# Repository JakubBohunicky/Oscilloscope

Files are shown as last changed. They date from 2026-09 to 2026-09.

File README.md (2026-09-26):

# Digital USB Oscilloscope

A simple 2-channel USB oscilloscope built around an **ESP32-S3** and an **AD9288** ADC (100 MSPS per channel). The board samples the signal, sends the data over USB to a PC, and a Windows app draws the waveform.

Made as a high-school SOČ project (2025).

<p align="center">
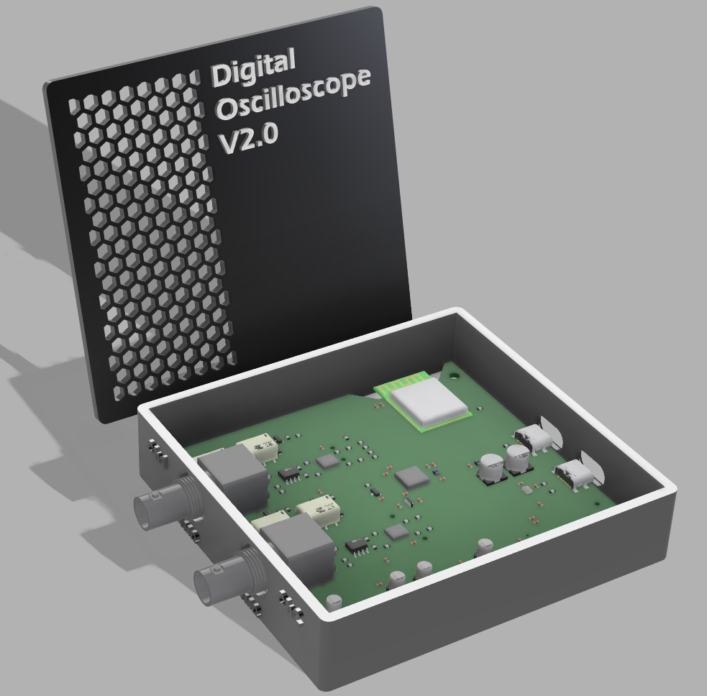
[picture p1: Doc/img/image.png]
3D render of V2.0 in its case
  
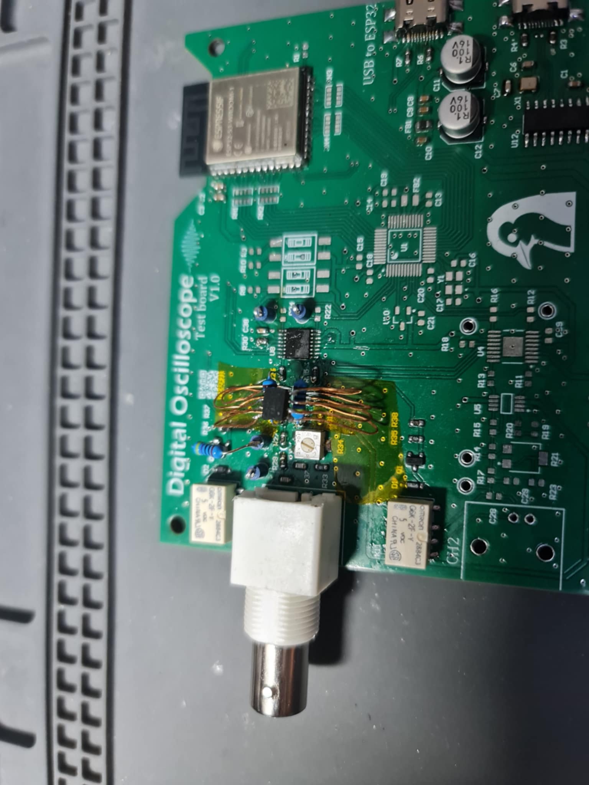
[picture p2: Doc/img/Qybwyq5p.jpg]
Assembled V1.0 test board
  
</p>
<p align="center"><i>Left: V2.0 in its 3D-printed case (render). Right: V1.0 test board.</i></p>

## Features

- 2 channels, BNC inputs
- AD9288 dual 8-bit ADC, up to 100 MSPS per channel
- x1 / x10 input range switched by relays
- Adjustable gain per channel (V/div) and time base (s/div)
- Powered and connected over USB-C
- PC app with live waveform display, min/max readout and optional smoothing

## How it works

```
BNC in → x1/x10 relays → AD8138 (diff. driver) → AD8370 (VGA) → AD9288 ADC → ESP32-S3 → USB-UART (CH340) → PC app
```

1. The input signal goes through a relay-switched attenuator (x1 / x10).
2. The **AD8138** converts it to a differential signal and the **AD8370** variable-gain amplifier scales it so it fits the ADC's 1 Vpp input.
3. The **AD9288** samples both channels; the **ESP32-S3** reads the samples in parallel through its GPIOs.
4. The ESP32 sends the data over UART (460800 baud) through a CH340 USB bridge.
5. The PC app sets the COM port, time base and V/div, and draws the received samples.

Power comes from the USB 5 V. LDOs make 3.3 V for the ESP32 and ADC, and a DC-DC boost to 12 V followed by regulators makes the ±5 V for the ADC driver.

## Schematic

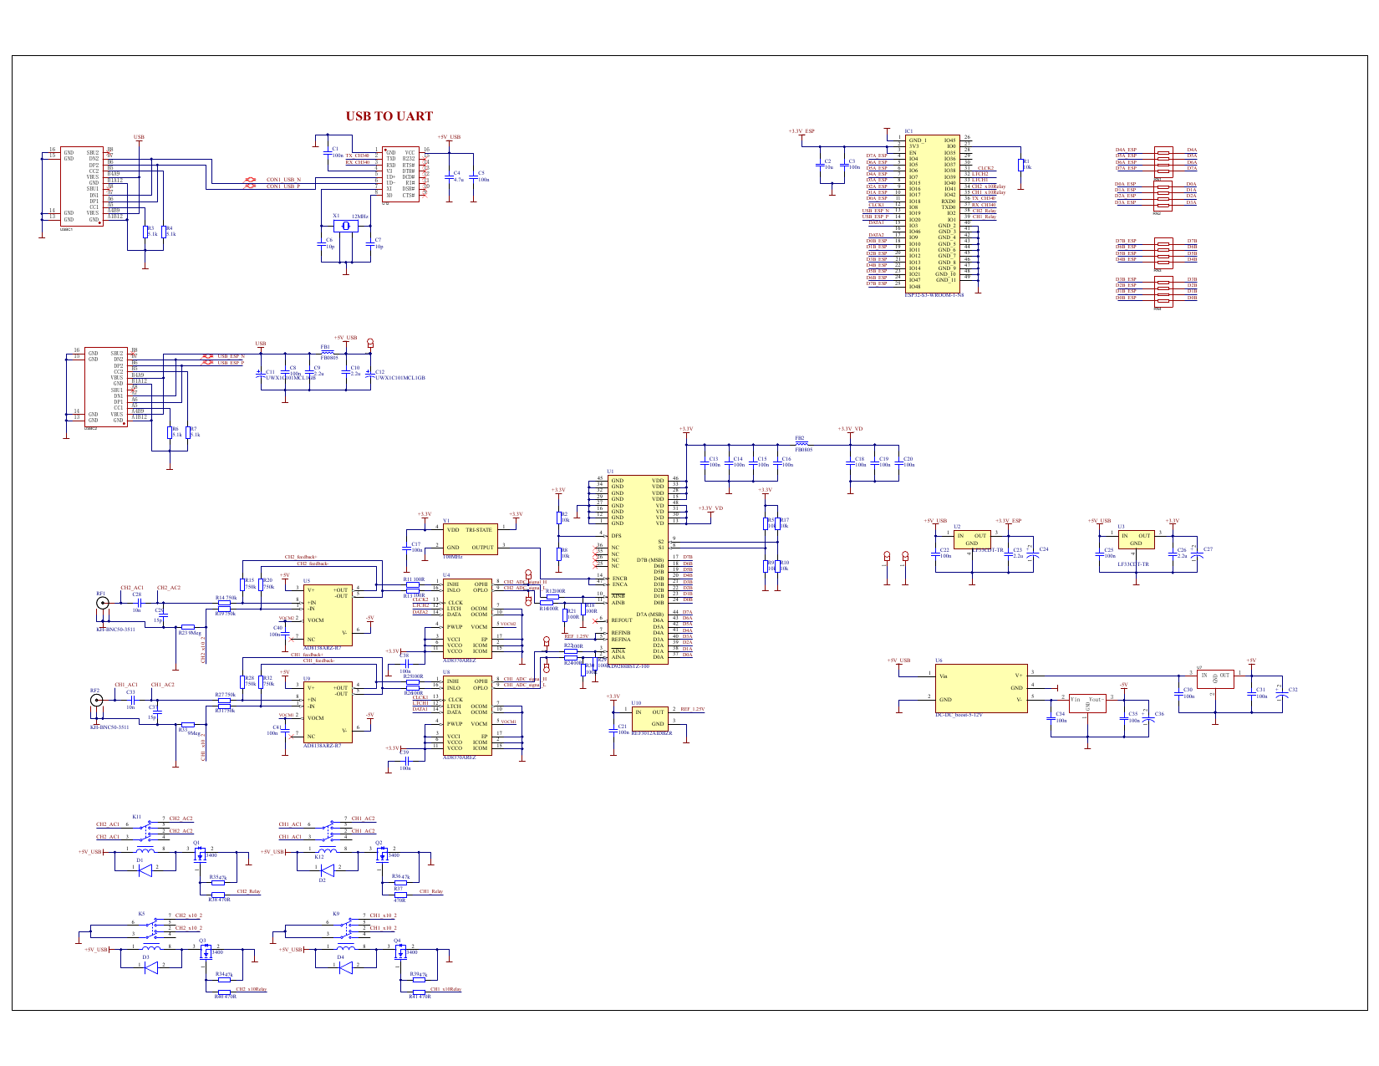
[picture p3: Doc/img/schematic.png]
Schematic


Full Altium projects (schematic, PCB, 3D model, assembly drawings) are in [`PCBs/`](PCBs/).

## Simulation

The input stage was simulated in SPICE before building the board, in both x1 and x10 mode.

| x1 | x10 |
|---|---|
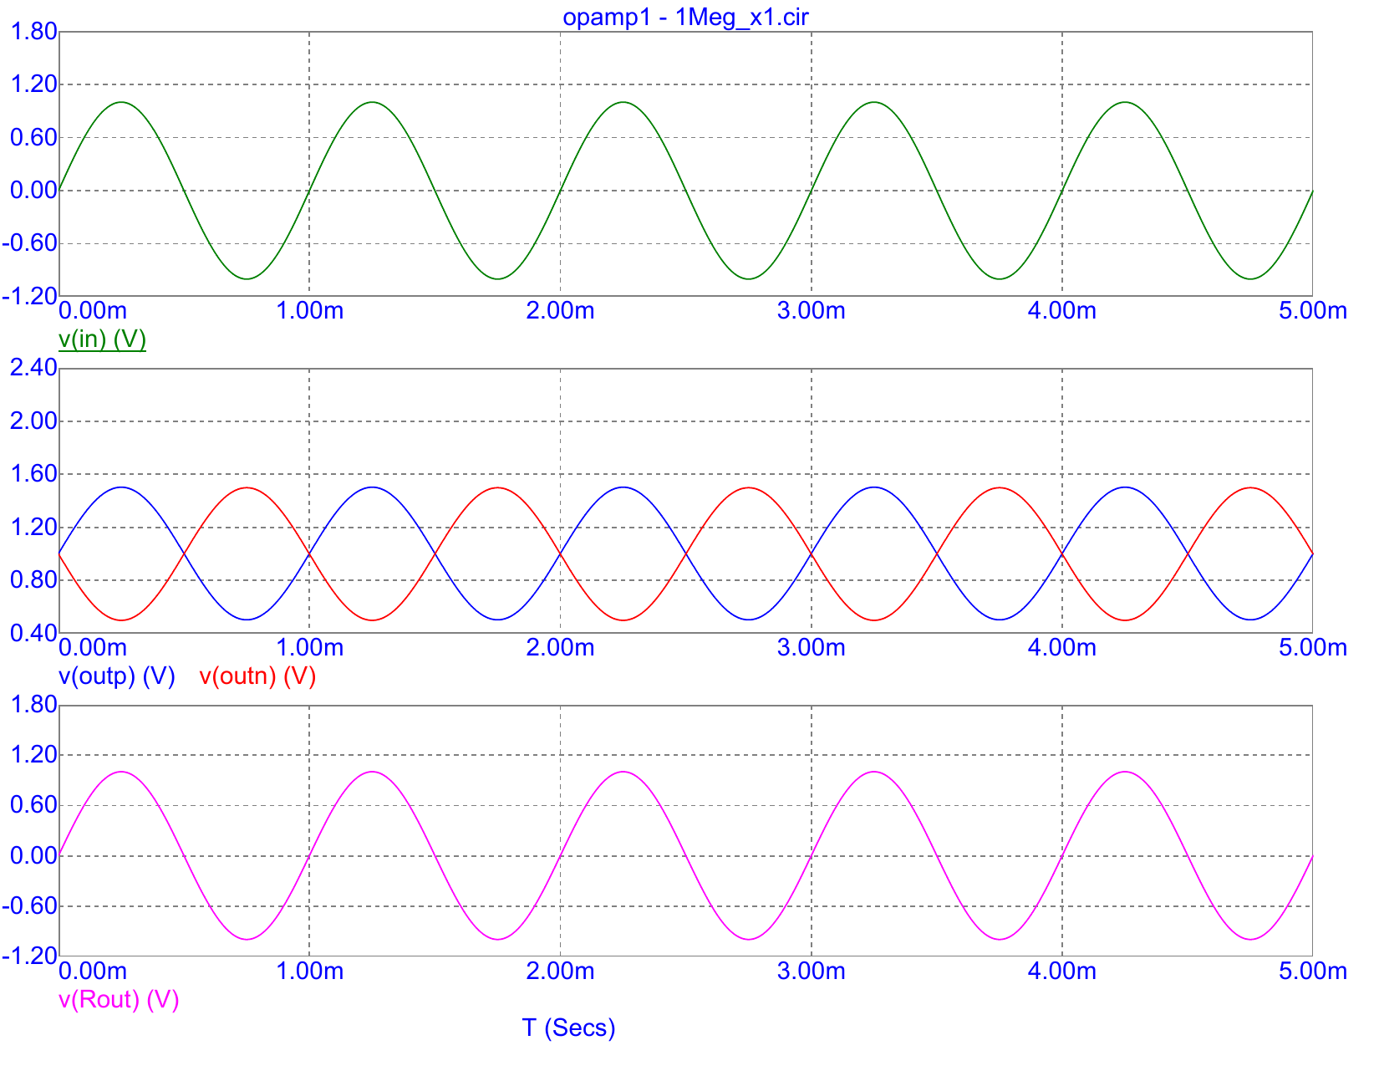
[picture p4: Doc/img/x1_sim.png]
x1 simulation
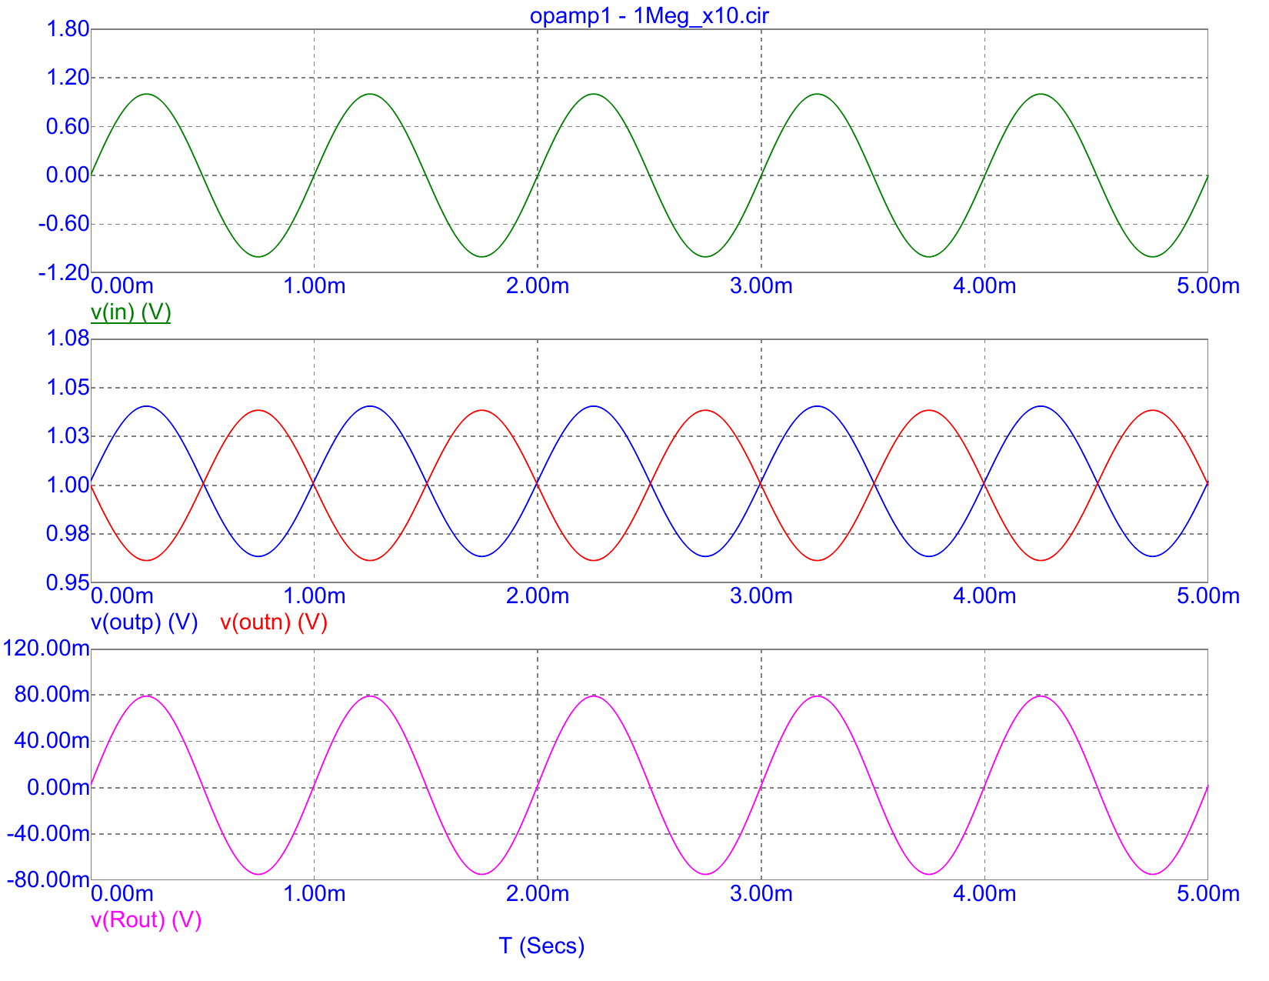
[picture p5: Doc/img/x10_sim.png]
x10 simulation
|  |  |

Circuit files are in [`Sim/`](Sim/).

## PC application

A simple Windows app (C# WinForms, source in [`Firmware/APP/`](Firmware/APP/); open `Osciloskop_software.sln` in Visual Studio) that works like a serial plotter: pick the COM port, press **OPEN**, and set the time base and V/div for each channel.

| Sine (5 ms/div) | Two sines, phase shift (8 µs/div) |
|---|---|
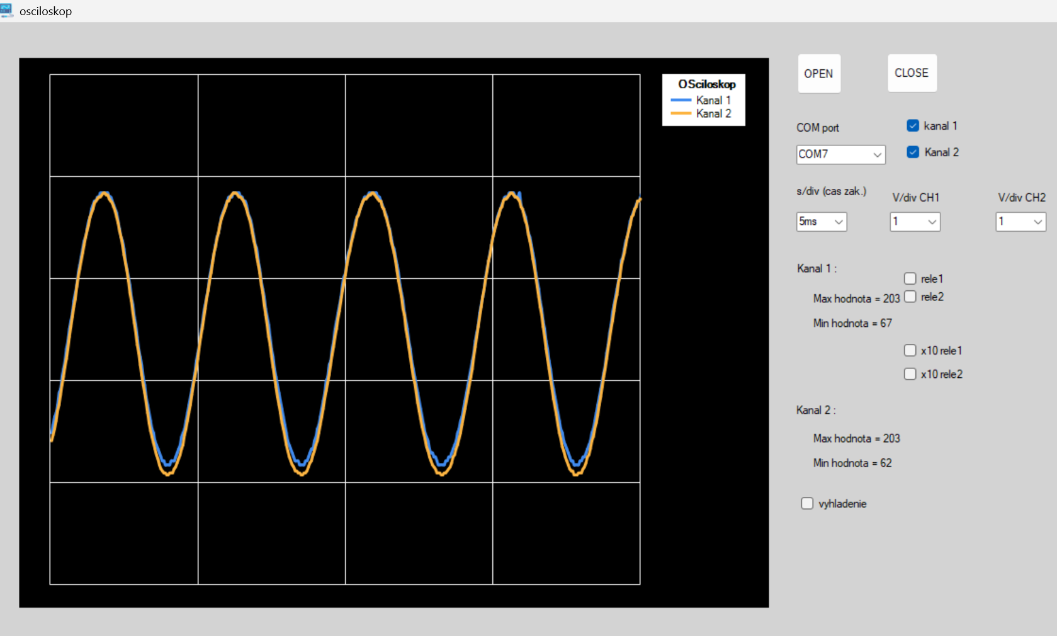
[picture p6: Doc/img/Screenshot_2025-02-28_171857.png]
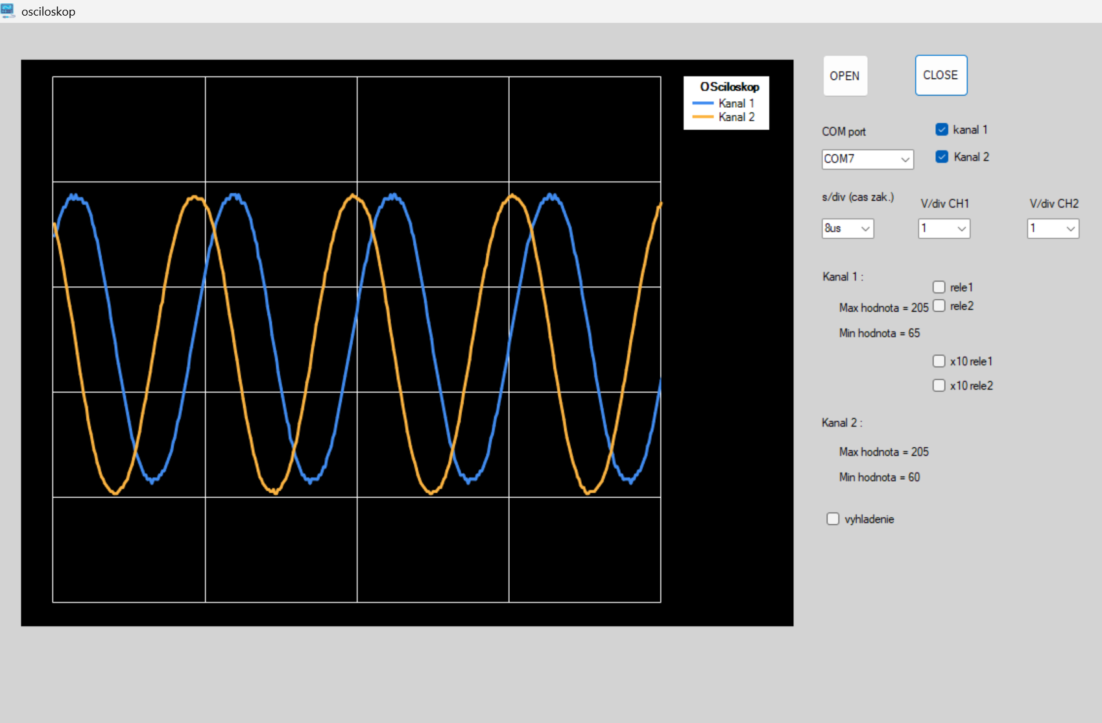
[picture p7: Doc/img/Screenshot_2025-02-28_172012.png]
|  |  |
| **Sine, different V/div** | **Triangle** |
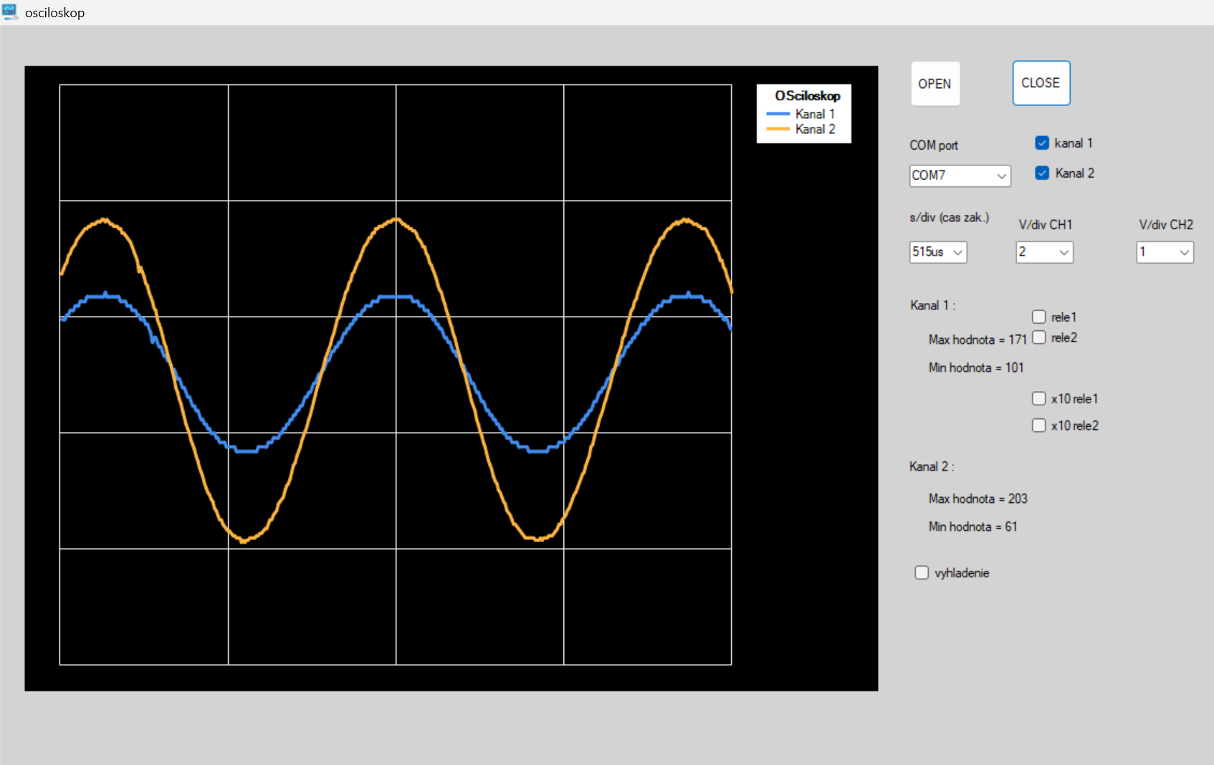
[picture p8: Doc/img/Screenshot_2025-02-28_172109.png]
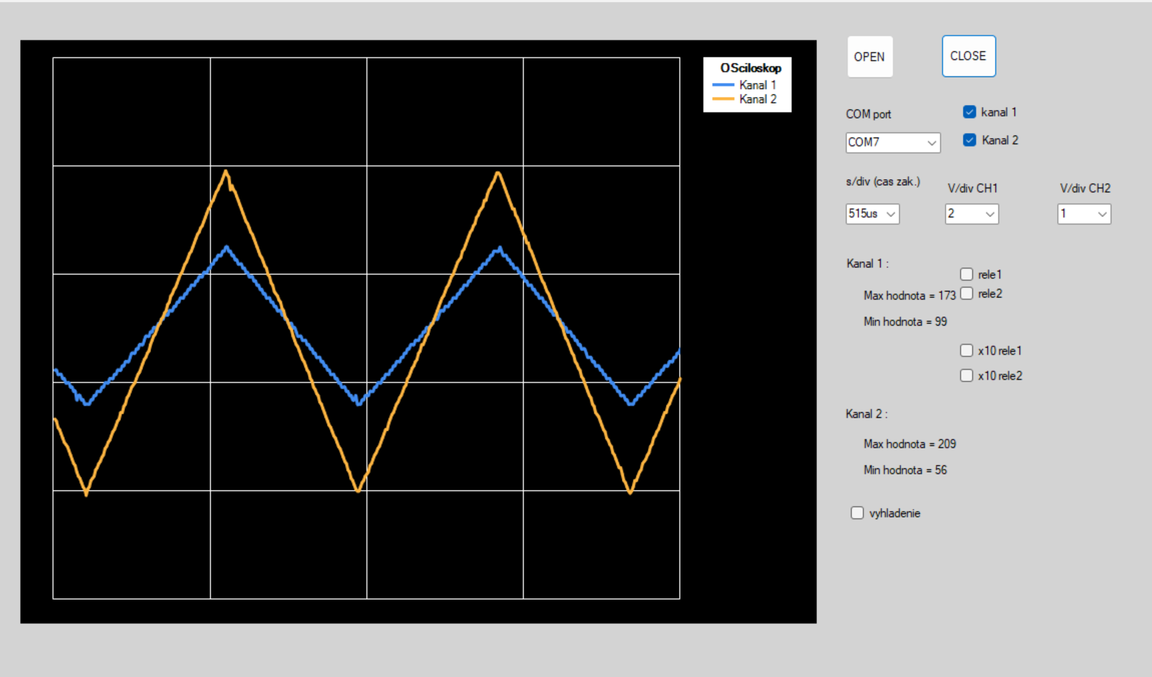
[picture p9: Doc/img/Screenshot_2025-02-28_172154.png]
|  |  |
| **Square wave** | **Linearity test** |
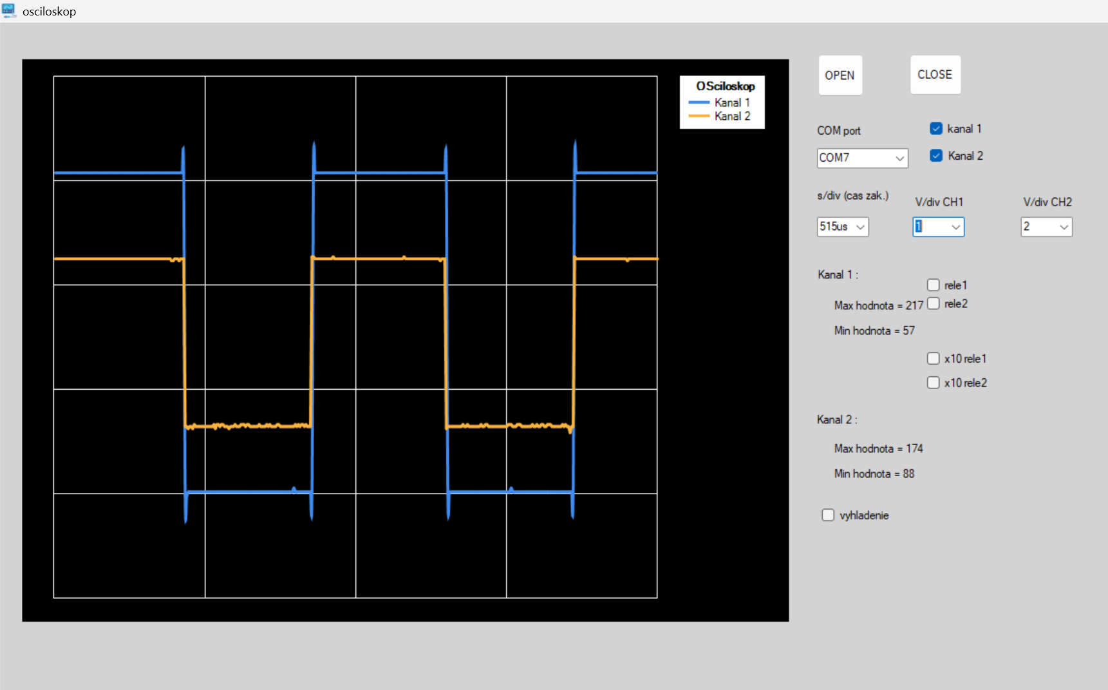
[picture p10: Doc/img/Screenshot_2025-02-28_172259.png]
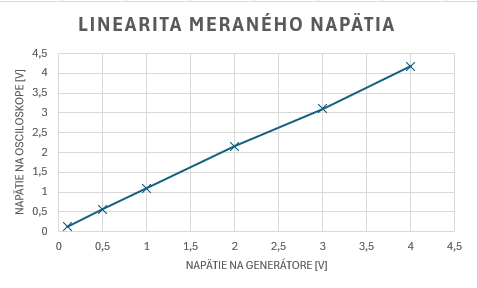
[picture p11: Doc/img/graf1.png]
|  |  |

The linearity test compares the voltage set on a signal generator with the voltage measured by the oscilloscope (0–4 V).

## Repository

| Folder | Contents |
|---|---|
| `PCBs/` | Altium projects, schematics and assembly drawings (V01, V02) |
| `Firmware/EPS32/` | ESP32 firmware (ESP-IDF) |
| `Firmware/APP/` | Windows app for viewing the signal (C#, Visual Studio) |
| `Sim/` | SPICE simulations of the input stage |
| `Doc/` | Full documentation and presentation (in Slovak) |

## Build the firmware

Needs [ESP-IDF](https://docs.espressif.com/projects/esp-idf/en/latest/esp32s3/get-started/).

```bash
cd Firmware/EPS32
idf.py set-target esp32s3
idf.py build flash monitor
```

## Documentation

- [Full documentation (SK)](Doc/SOC_Documentation.pdf)
- [Presentation (SK)](Doc/SOC_Presentation.pdf)

## Authors

Jakub Bohunický, Ondrej Peter, Peter Bódi

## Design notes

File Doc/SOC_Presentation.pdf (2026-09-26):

# Digitálny Osciloskop

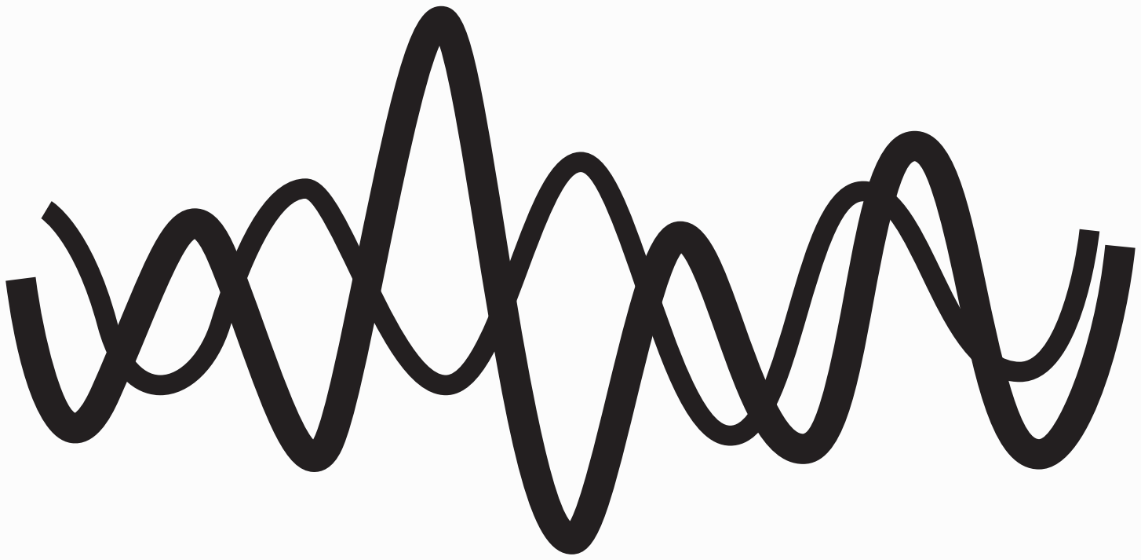
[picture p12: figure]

Jakub Bohunický,
Ondrej Peter, Peter Bódi

SPSŠE Nitra

# Náš cieľ:

Vytvoriť cenovo dostupný osciloskop pre študentov s možnosťou vlastného zostavenia

# Vývoj nášho osciloskopu

### Výber súčiastok

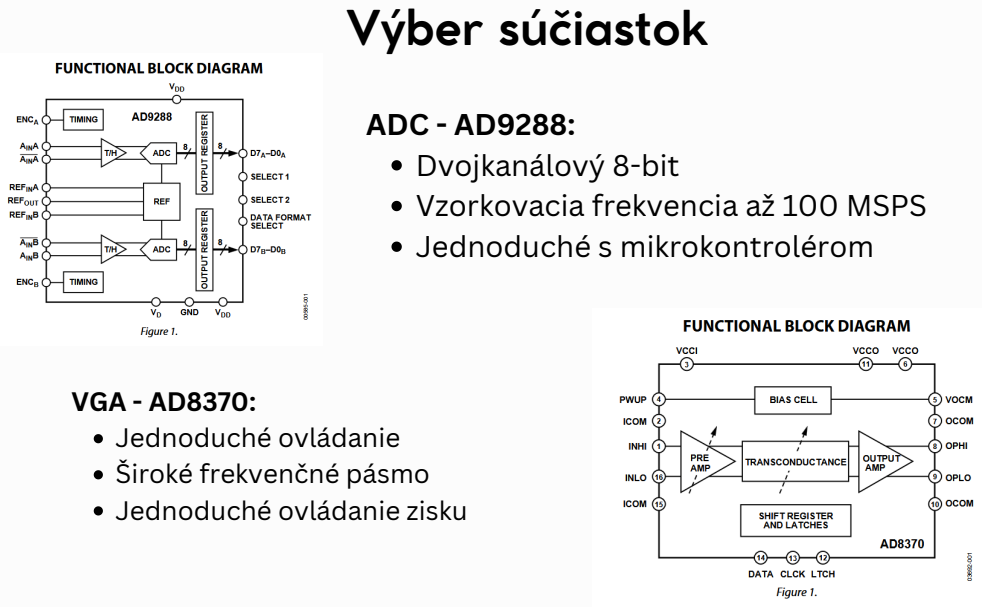
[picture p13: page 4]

ADC - AD9288:
Dvojkanálový 8-bit
Vzorkovacia frekvencia až 100 MSPS
Jednoduché s mikrokontrolérom

VGA - AD8370:
Jednoduché ovládanie
Široké frekvenčné pásmo
Jednoduché ovládanie zisku

### Výber súčiastok

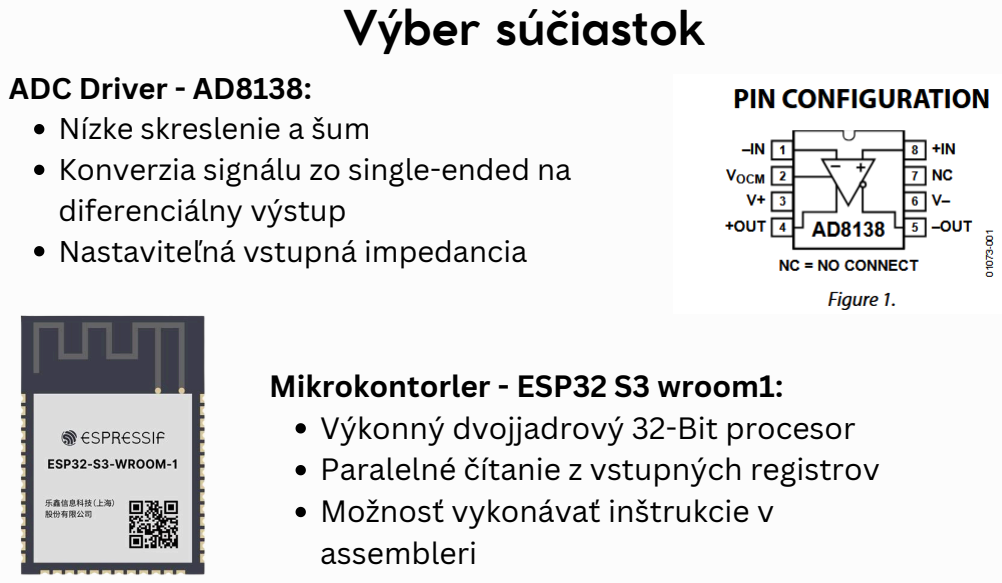
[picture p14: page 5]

ADC Driver - AD8138:
Nízke skreslenie a šum
Konverzia signálu zo single-ended na
diferenciálny výstup
Nastaviteľná vstupná impedancia

Mikrokontorler - ESP32 S3 wroom1:
Výkonný dvojjadrový 32-Bit procesor
Paralelné čítanie z vstupných registrov
Možnosť vykonávať inštrukcie v
assembleri

### Simulácia vstupného obvodu

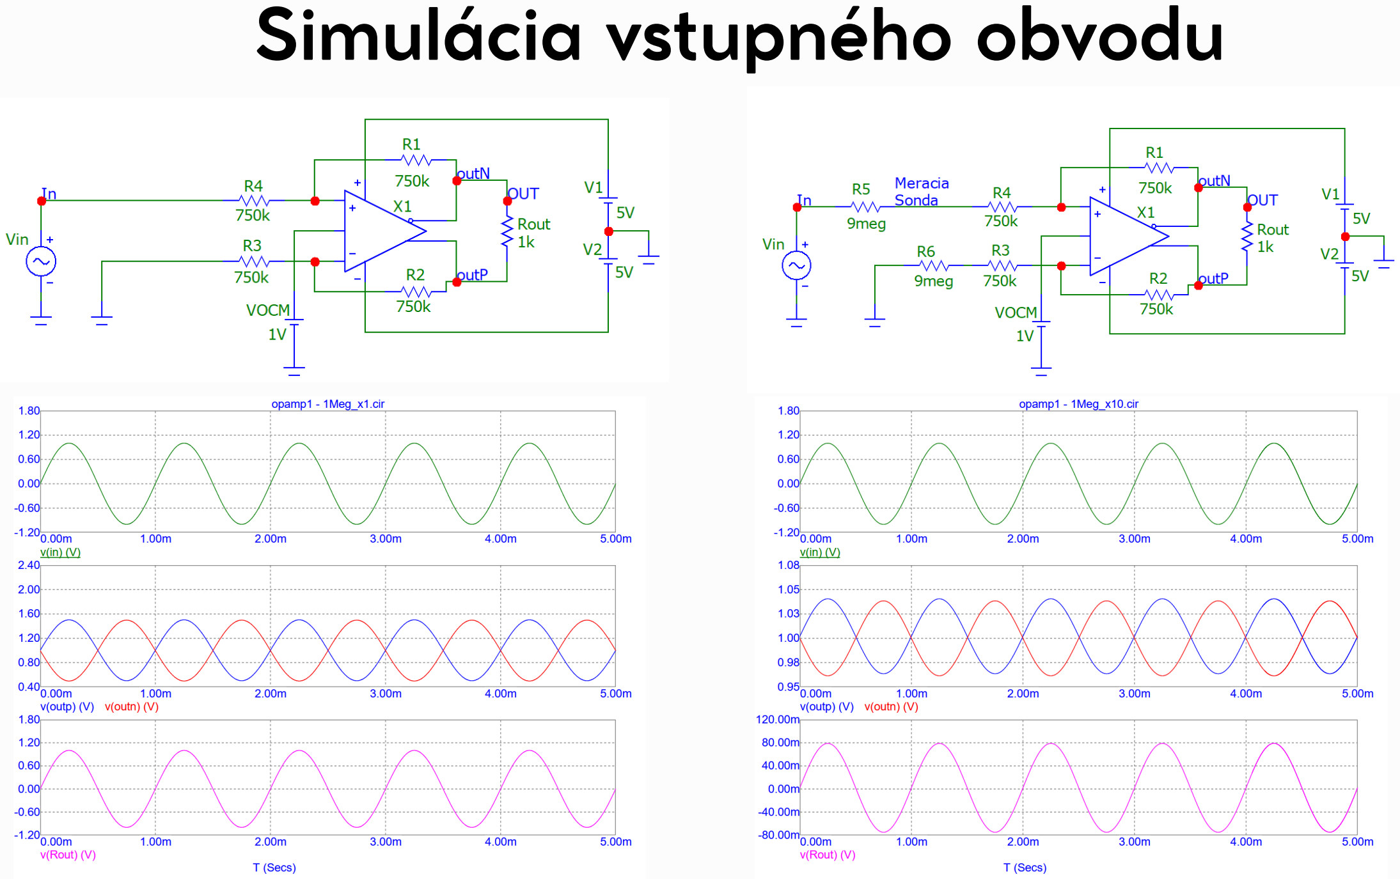
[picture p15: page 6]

### Bloková schéma

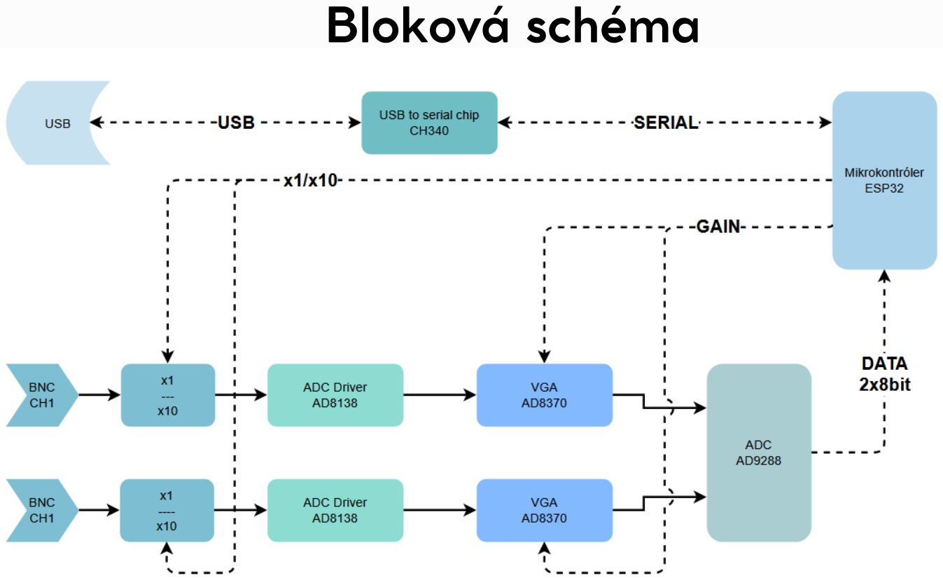
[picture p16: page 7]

### Nastavovalnie zosilnenia

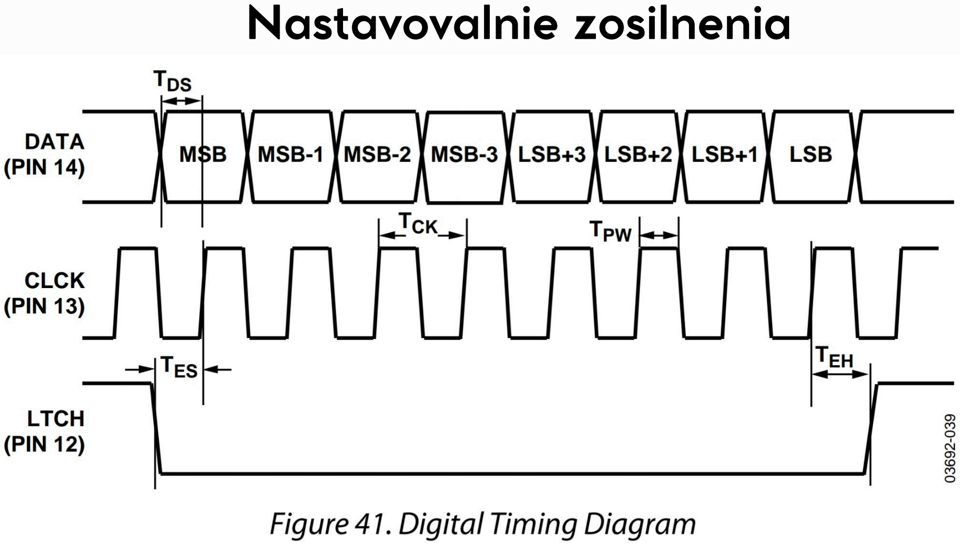
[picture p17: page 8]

### Testovacia doska

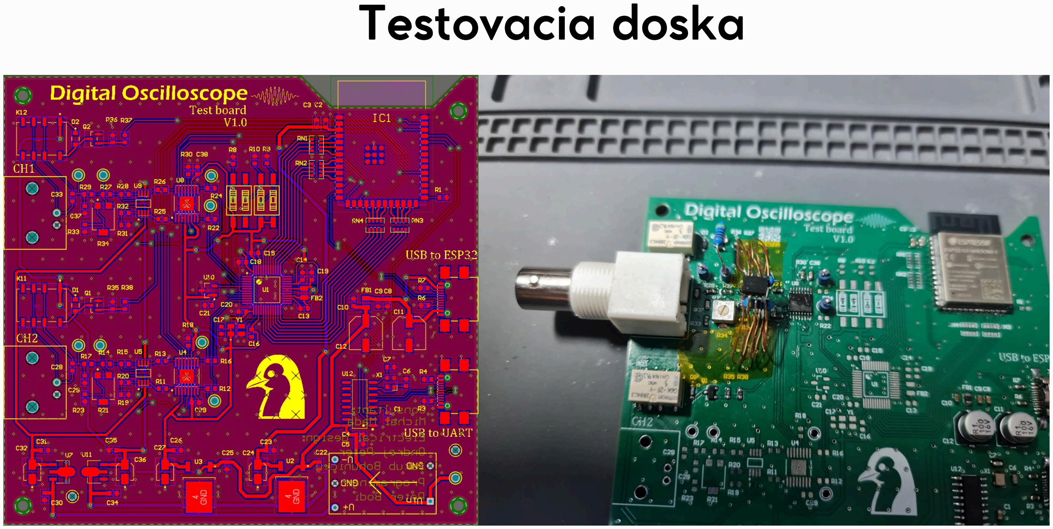
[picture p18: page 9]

### Finálne vyhotovenie

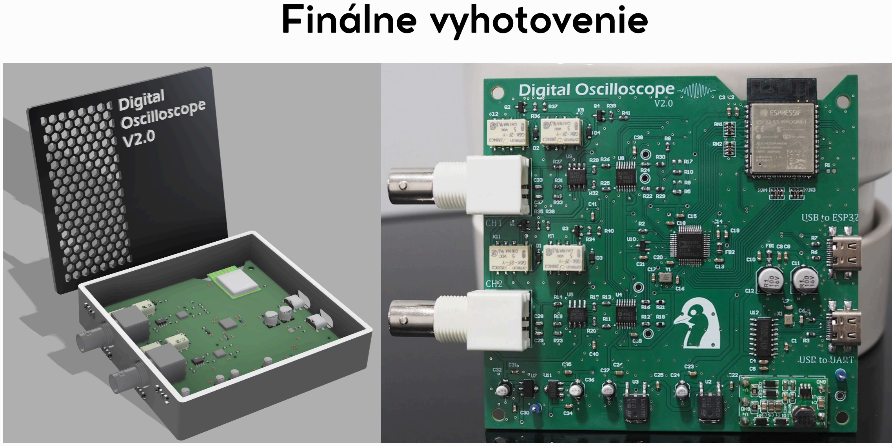
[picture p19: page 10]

### CHARAKTERISTIKY OSCILOSKOPU

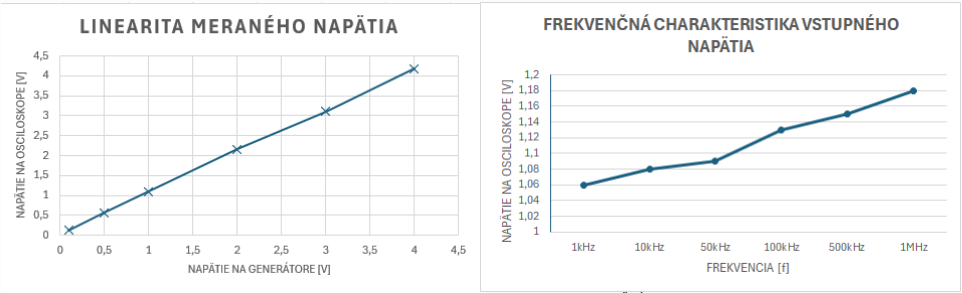
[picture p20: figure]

PRI VSTUPNOM NAPÄTÍ 1V

Dosihnuté parametre:
Maximálne vstupné napätie: 5V/50V
Vzorkovacia frekvencia: 100MSPS/80MSPS Vstupná impedancia: 1MΩ

# Ďakujem za pozornosť

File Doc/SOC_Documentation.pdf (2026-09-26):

STREDNÁ PRIEMYSELNÁ ŠKOLA STROJNÍCKA A ELEKTROTECHNICKÁ

ULICA FRAŇA KRÁĽA 20, 949 01 NITRA

DIGITÁLNY OSCILOSKOP

Stredoškolská odborná činnosť

Číslo odboru: 12

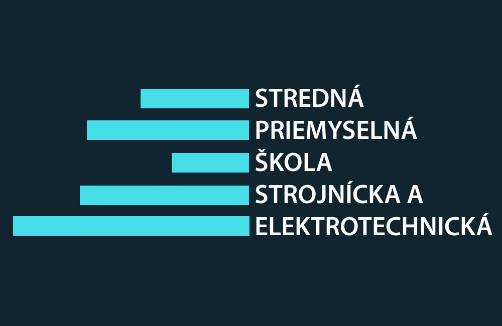
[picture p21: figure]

Riešitelia :Jakub Bohunický, Ondrej Peter, Peter Bódi

Nitra

2025

Ročník štúdia: tretí, štvrtý

STREDNÁ PRIEMYSELNÁ ŠKOLA STROJNÍCKA A ELEKTROTECHNICKÁ

ULICA FRAŇA KRÁĽA 20, 949 01 NITRA

DIGITÁLNY OSCILOSKOP

Stredoškolská odborná činnosť

Číslo odboru: 12

Riešitelia: Jakub Bohunický, Ondrej Peter, Peter Bódi

Nitra

2025

Ročník štúdia: tretí, štvrtý

Školiteľ: Ing. Michal Mada

Čestné vyhlásenie

Vyhlasujem, že prácu stredoškolskej odbornej činnosti na tému Digitálny

osciloskop som vypracoval samostatne, s použitím uvedených literárnych zdrojov. Som

si vedomý zákonných dôsledkov, ak v nej uvedené údaje nie sú pravdivé.

Meno a priezvisko autora

Poďakovanie

Touto cestou by sme sa chceli poďakovať školiteľovi práce, Ing. Michalovi

Madovi za pomoc, odborné vedenie, cenné rady a pripomienky pri vypracovaní našej

práce.

## OBSAH

SPŠSE Nitra | Problematika a prehľad literatúry

ÚVOD

Digitálne USB osciloskopy predstavujú moderné a flexibilné nástroje na meranie

a analýzu elektrických signálov. Pri práci s nimi sa stretávame s rôznymi pojmami, ako

sú vzorkovacia frekvencia, šírka pásma, ktoré môžu byť pre začiatočníkov náročné na

pochopenie. Táto téma nás oslovila natoľko, že sme sa rozhodli vytvoriť si vlastný

osciloskop, aby sme lepšie poukázali na jeho fungovanie a možnosti využitia. Touto

prácou chceme sprístupniť tému digitálnych osciloskopov najmä pre študentov tým, že

poskytneme interaktívne a dostupné možnosti zobrazenia a analýzy signálov. Pomocou

grafického znázornenia a možnosti meniť parametre merania umožníme lepšie

pochopenie fungovaniu elektroniky a jej využitia v praxi. Pochopenie základných

princípov obvodov je kľúčové nielen pri štúdiu, ale aj v praktickej elektronike, keďže

tieto prístroje sú nevyhnutnou súčasťou vývoja a diagnostiky elektronických systémov.

Takéto USB osciloskopy kombinujú kompaktnosť s vysokou presnosťou merania,

vhodnou aj pre náročnejšie projekty. Pre študentov poskytujú dostatočný výkon na

efektívnu prácu a rozvoj v elektrotechnike.

SPŠSE Nitra | Problematika a prehľad literatúry

### 1 PROBLEMATIKA A PREHĽAD LITERATÚRY

### 1.1 OSCILOSKOP

Osciloskop je elektronický merací prístroj na zobrazovanie a analýzu elektrických

signálov v čase. Na jednej osi znázorňuje napätie a na druhej čas, čo umožňuje detailné

skúmanie ich vlastností, ako sú amplitúda, frekvencia či skreslenie. Jeho využitie je

neoddeliteľnou súčasťou práce s elektrickými obvodmi, kde pomáha odhaľovať chyby,

overovať návrhy a optimalizovať systémy. Umožňuje presné doladenie parametrov, čím

zabezpečuje spoľahlivú a efektívnu prevádzku zariadení. Navyše hrá kľúčovú úlohu v

rozvoji nových technológií a inovácií.

Osciloskop umožňuje nielen sledovať, ale aj analyzovať signály, čím prispieva k

presnejšej kontrole a zlepšovaniu výkonu elektronických systémov. Poskytuje tak

neoceniteľný pohľad do správania elektrických signálov, čo uľahčuje diagnostiku a vývoj

nových technológií. (OSCILOSKOP, 2020)

### 1.2 VÝVOJ OSCILOSKOPOV

Vývoj osciloskopov prešiel od analógových zariadení po moderné digitálne

prístroje s pokročilými funkciami. Kým staršie analógové modely využívali katódovú

trubicu (CRT) na zobrazovanie signálov v reálnom čase, ich obmedzené možnosti

ukladania údajov viedli k postupnému nahradeniu digitálnymi osciloskopmi (DSO).

DSO priniesli revolúciu v meracej technike, pretože signály konvertujú do

digitálnej podoby pomocou vzorkovania. Ich hlavnými výhodami sú možnosť ukladania,

podrobnej analýzy, automatických výpočtov a širokej škály pokročilých funkcií. Vďaka

veľkej pamäti umožňujú dlhodobý záznam signálov a ich detailnú analýzu. Dnes sú

štandardom v priemysle, výskume aj vzdelávaní vďaka svojej flexibilite a presnosti.

### 1.3 VÝBER SPRÁVNEHO TYPU OSCILOSKOPU

Pri výbere osciloskopu zohrávajú dôležitú úlohu parametre, ako sú šírka pásma,

vzorkovacia frekvencia, mobilita a cena. Stolné osciloskopy sú určené pre profesionálne

aplikácie, kde je potrebná vysoká presnosť, rýchle vzorkovanie a pokročilé nástroje. Ich

veľké displeje a viackanálové meranie umožňujú detailnú vizualizáciu a diagnostiku

zložitých elektronických systémov. Nevýhodou je ich vyššia cena a nižšia prenosnosť.

SPŠSE Nitra | Problematika a prehľad literatúry

Naopak, USB osciloskopy predstavujú kompaktné a cenovo dostupné riešenie. Sú

vhodné pre študentov, začínajúcich technikov a hobby nadšencov, ktorí potrebujú

základné meranie signálov bez nutnosti investovať do drahých prístrojov. Ich hlavnými

výhodami sú prenosnosť, jednoduché ovládanie a nízka cena. Nevýhodou môže byť

nižšia presnosť a závislosť od výkonu počítača.

Pre špecifické aplikácie existujú aj prenosné osciloskopy, ktoré kombinujú

výhody oboch typov. Poskytujú dostatočnú presnosť, pričom sú navrhnuté na použitie v

teréne, kde je potrebná mobilita a nezávislosť od externého počítača. Ich nevýhodou je

však často vyššia cena v porovnaní s USB modelmi. (TYPY OSCILOSKOPOV, 2025)

### 1.4 ZÁKLADNÉ ČASTI OSCILOSKOPU

Vstupný obvod - osciloskopu slúži na privádzanie a prispôsobenie meraného

signálu pre ďalšie spracovanie. Zabezpečuje správne impedančné prispôsobenie a

ochranu ďalších častí obvodov pred prepätím.

Operačný zosilňovač - Operačný zosilňovač je kľúčový prvok pri úprave

analógového signálu pred jeho spracovaním v analógovo-digitálnom prevodníku (ADC).

Jeho hlavnou úlohou je zosilnenie alebo zoslabnutie signálu, čím optimalizuje využitie

dynamického rozsahu ADC a zabezpečuje presnú digitalizáciu.

Riadenie zisku zosilňovača umožňuje prispôsobiť veľkosť signálu požiadavkám

spracovacieho systému, čím sa predchádza jeho preťaženiu alebo strate jemných detailov.

Dôležitými parametrami operačných zosilňovačov sú šírka pásma, linearita, nízky šum a vstupná impedancia. Široké pásmo zaručuje spoľahlivé spracovanie vysokofrekvenčných

signálov, lineárna odozva minimalizuje skreslenie a nízka úroveň šumu zabezpečuje

presnosť merania aj pri slabých vstupných signáloch. Vysoká vstupná impedancia je

nevyhnutná na to, aby zosilňovač nezaťažoval zdroj signálu a nespôsoboval jeho degradáciu. (OPERAČNÉ ZOSILŇOVAČE, 2015)

SPŠSE Nitra | Problematika a prehľad literatúry

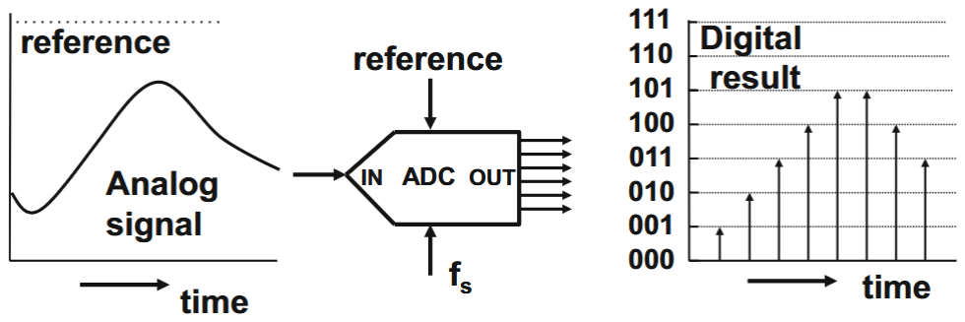
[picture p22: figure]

8

Analógovo-digitálny prevodník (ADC) - slúži na konverziu spojitého

analógového signálu do digitálnej formy, ktorú je možné ďalej spracovávať

mikrokontrolérom alebo iným digitálnym systémom. Tento proces pozostáva z troch

hlavných krokov: vzorkovanie, kvantovanie a kódovanie.

Pri vzorkovaní sa analógový signál meria v pravidelných časových intervaloch,

pričom frekvencia vzorkovania určuje, ako často sa odoberajú vzorky. Kvantovanie

priraďuje každej vzorke najbližšiu možnú diskrétnu hodnotu, čo vedie k vzniku

kvantizačnej chyby. Nakoniec kódovanie prevádza získané hodnoty na digitálny kód

reprezentujúci vstupný signál v číselnej forme.

Presnosť digitalizovaného signálu závisí od rozlíšenia ADC a vzorkovacej

frekvencie – vyššie hodnoty týchto parametrov zabezpečujú vernejšiu reprezentáciu

analógového signálu. Oproti analógovému spracovaniu signálu ponúka digitálne

spracovanie viaceré výhody, ako lepší odstup signálu od šumu, presné uchovávanie

údajov a možnosť vykonávania komplexných výpočtov.

Obrázok 1 ADC, Marcel JM Pelgrom, 2020

SPŠSE Nitra | Problematika a prehľad literatúry

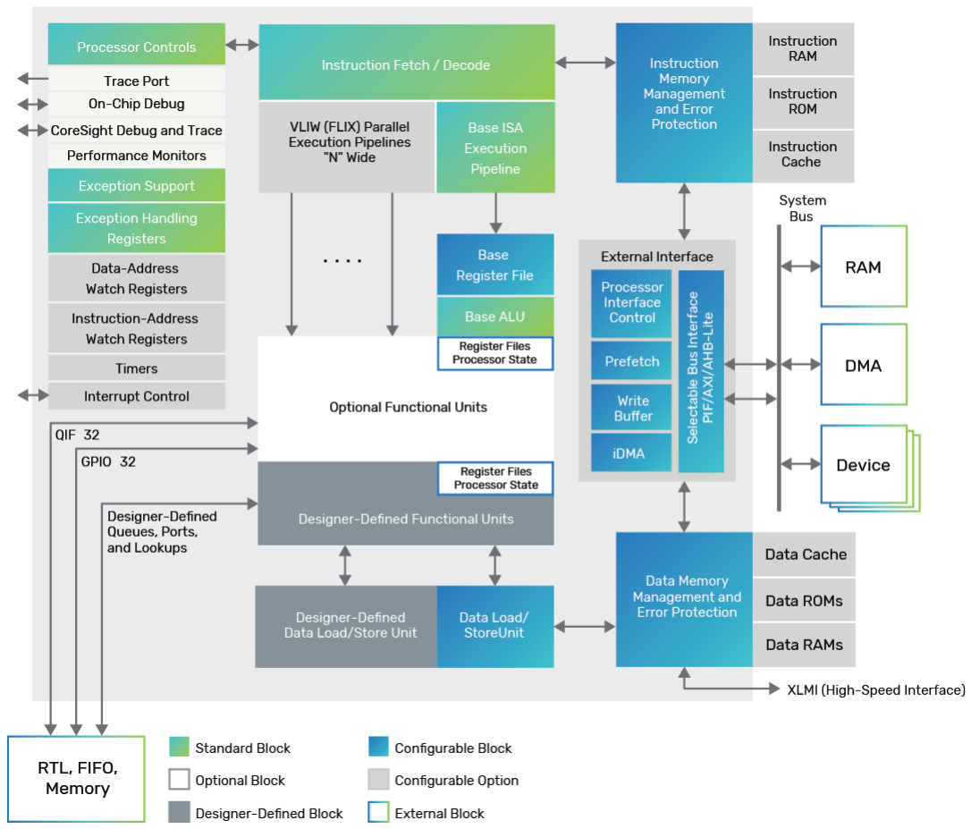
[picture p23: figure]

9

Mikrokontrolér - je vysoko integrované zariadenie, ktoré obsahuje procesor

(CPU), pamäť a periférne obvody na jednom čipe. Jeho úlohou je riadenie a spracovanie

údajov v elektronických systémoch, pričom umožňuje efektívne a automatizované

vykonávanie úloh.

Mikrokontrolér vykonáva program uložený v pamäti ROM alebo Flash, kde sú

uložené inštrukcie pre jeho činnosť. Počas behu programu využíva RAM na dočasné

uloženie údajov a EEPROM na uchovávanie trvalých informácií. Vstavané časovače,

vstupno-výstupné (I/O) porty a komunikačné rozhrania umožňujú interakciu s okolitým

prostredím a inými zariadeniami.

Obrázok 2 Blokový diagram procesora Xtensa LX7 používaný v ESP32, Cadence, 2025

SPŠSE Nitra | Ciele práce SOČ

10

### 2 CIELE PRÁCE SOČ

Cieľom tejto práce je návrh a realizácia digitálneho USB osciloskopu spolu so

softvérom na PC, ktorý umožní presnú analýzu signálov v reálnom čase. Systém bude

využívať vysokorýchlostný AD prevodník na vzorkovanie signálov a komunikovať s

počítačom cez USB rozhranie. Softvér bude slúžiť na vizualizáciu nameraných údajov,

spracovanie signálov a ich analýzu.

Čiastkové ciele:

- Výber vhodných súčiastok pre realizáciu zariadenia
- Návrh schémy a simulácia digitálneho USB osciloskopu
- Návrh a výroba dosky plošných spojov
- Realizácia a následné osadenie DPS
- Osadenie a oživenie elektroniky osciloskopu
- Implementácia firmvéru pre mikrokontrolér zabezpečujúceho

komunikáciu a spracovanie dát

- Vývoj PC softvéru na vizualizáciu a analýzu signálov
- Testovanie a optimalizácia celého systému

SPŠSE Nitra | Výsledky práce

### 3 MATERIÁL A METODIKA

### 3.1 HARDWARE

Na prevod analógových signálov na digitálne hodnoty sme si vybrali dvojkanálový

prevodník AD9288, ktorý poskytuje vzorkovaciu frekvenciu 100 MSPS na každý kanál s

rozlíšením 8 bitov. Tento prevodník sme zvolili kvôli jeho diferenciálnemu vstupu, ktorý

nám umožňuje presnejšie meranie signálu a efektívnejšiu elimináciu rušenia. Vďaka jeho

vysokej rýchlosti snímania dokážeme zachytiť aj veľmi rýchle zmeny v analyzovanom

signáli, čo je pre náš merací systém kľúčové.

Aby sme mohli signál korektne priviesť na ADC, použili sme zosilňovač AD8370

s nastaviteľným ziskom, ktorý nám umožňuje nastaviť úroveň zosilnenia od -11 dB do

+34 dB. Tento zosilňovač sme zvolili na prispôsobenie signálu tak, aby napätie medzi

diferenciálnym vstupmi ADC nepresiahlo 1 Vpp (peak-to-peak). Pre správne impedančné

prispôsobenie vstupu osciloskopu sme si vybrali operačný zosilňovač AD8138ARMZ,

ktorý zabezpečuje vstupnú impedanciu 1 MΩ.

Ako riadiaci mikropočítač sme v tejto práci použili ESP32 vo verzií S3, a to najmä

z dôvodu vysokej rýchlosti procesora (až 240MHz) v porovnaní napríklad s bežnejšie

používaným ale pomalším mikropočítačom ATmega 8 a toho, že procesor ktorý sme sa

rozhodli použiť disponuje dvoma jadrami ktoré dokážu bežať súčasne a nezávisle na

sebe. To z mikropočítača ESP32 robí optimálnu voľbu práve pre aplikáciu ako riadiaci

prvok tohto projektu, keďže každé jadro dokáže nezávisle spracovávať dáta z

prislúchajúceho meracieho kanálu. Toto je nevyhnutné, keďže cieľom tejto práce je

vytvorenie osciloskopu schopného súčasne spracovávať dáta z viacerých meracích

kanálov.

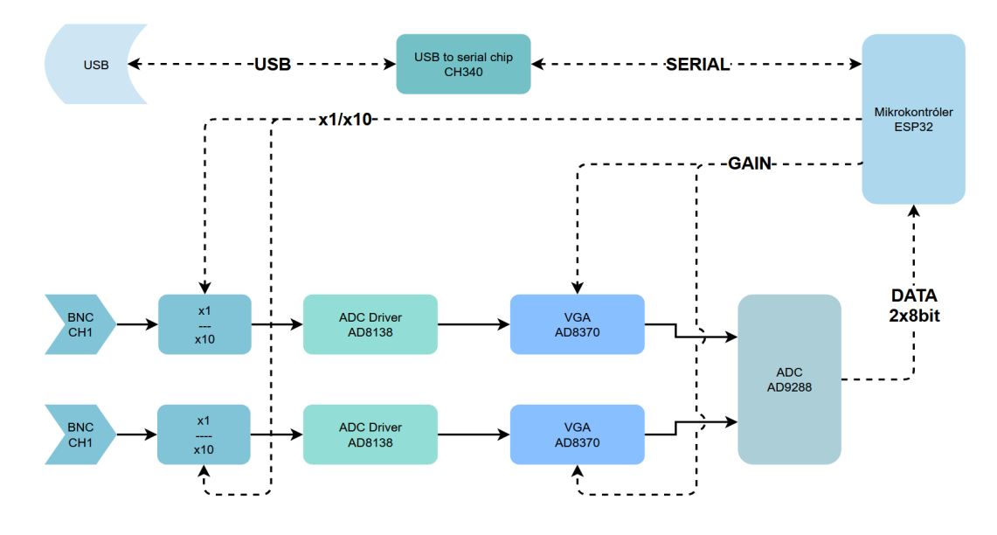
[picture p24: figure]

Obrázok 3 Bloková schéma zapojenia osciloskopu

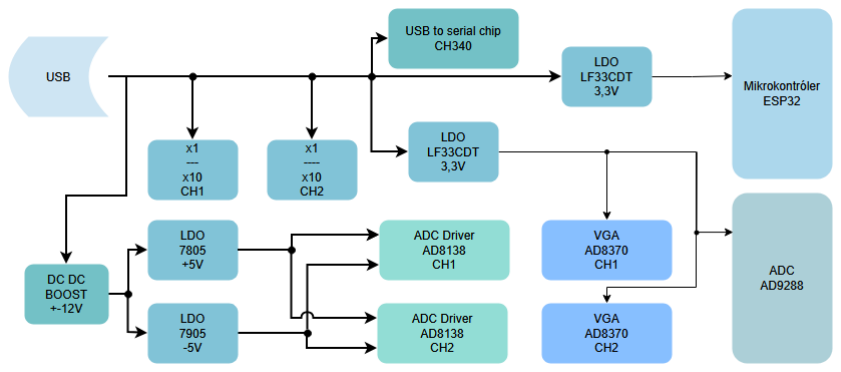
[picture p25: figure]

Na obrázku 4 môžeme vidieť schému napájania rôznych sekcii. Napájanie je

zložené zo štyroch napäťových úrovni. Jedna z najdôležitejších časti nášho osciloskopu

je mikropočítač ESP32, ktorý je napájaný vlastným LDO (low dropout regulator), ktorý

premieňa 5V z USB na 3,3V. Priamo na 5V je napojený iba prevodník z USB na UART a relé na prepínanie deličky. Ďalšie LDO z výstupom 3,3V napája dva operačné

zosilňovače s nastaviteľným ziskom (VGA) a analógovo digitálny prevodník. Ďalší blok

mame DC-DC boost na napätie 12V kvôli zápornej napájacej vetve, ktorú budeme

potrebovať na napájanie ADC driveru. Napätie 12V sme následne prekonvertovali na dve

Obrázok 4 Bloková schéma napájania osciloskopu vetvy +5V a -5V kvôli stabilnej hodnote napájacieho napätia a kvôli zníženiu šumu, ktorý

vzniká pri spínaných meničoch.

### 3.2 SIMULÁCIA A VÝPOČTY

Súčasne s výberom dostupných súčiastok pre náš osciloskop sme vykonali

simuláciu vstupného obvodu, aby sme zabezpečili kompatibilitu medzi jednotlivými

integrovanými obvodmi. Cieľom bolo overiť správnu funkčnosť celého zapojenia ešte

pred objednaním plošných spojov, čím sme minimalizovali nutnosti dodatočných úprav.

Jednou zo základných požiadaviek pri návrhu bolo zabezpečenie vstupnej impedancie na

úrovni 1 MΩ, čo je štandardná hodnota pre osciloskopy. Vstupný zosilňovač, ktorý sme

použili, má v datasheete uvedenú rovnicu na výpočet vstupnej impedancie, podľa ktorej

sme upravili hodnoty rezistorov v obvode spätnej väzby na hodnotu 750kΩ.

Keďže osciloskop sa používa s meracími sondami, ktoré často ponúkajú

prepínateľný deliaci pomer x1 a x10, museli sme tomu prispôsobiť aj náš vstupný obvod.

Pri použití sondy s pomerom x10 sa do cesty signálu zaradí dodatočný odpor 9 MΩ, ktorý

spolu s existujúcou impedanciou vstupu vytvára napäťový delič. Aby sme zachovali

správne fungovanie zosilňovača, bolo potrebné pridať ďalší 9 MΩ odpor na druhý vstup

nášho zosilňovača, keďže pracuje v single-ended zapojení. Tým sme zabezpečili rovnaké

podmienky pre signál a zabránili skresleniu alebo nesprávnemu fungovaniu meraní.

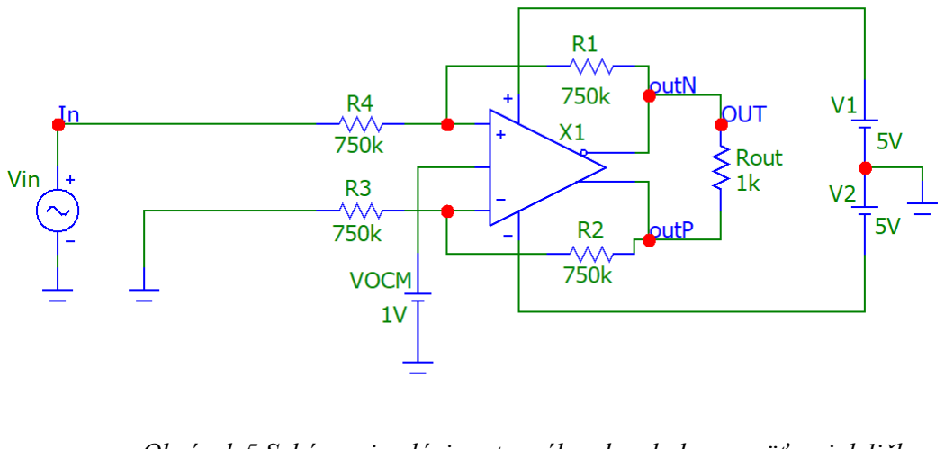
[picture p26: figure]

Obrázok 5 Schéma simulácie vstupného obvodu bez napäťovej deličky

Na simulovanej schéme môžeme vidieť operačný zosilňovač s pinom VOCM,

ktorý slúži na ofset signálu jednosmernou zložkou, pre správne prispôsobenie signálu do

ADC. Tento pin v skutočnom zapojení ovláda operačný zosilňovač s nastaviteľným

ziskom. V simulácii sme použili jednosmerný zdroj, kvôli jednoduchosti simulovaného

zapojenia. Na výstupe operačného zosilňovača máme diferenciálne vedenie, ktoré znižuje

citlivosť na elektromagnetické rušenie, ktoré sa môže indukovať na vodičoch. Keďže

ADC príma rozdiel signálu medzi dvoma diferenciálnymi vodičmi, spoločne rušenie sa

eliminuje, ak je vedenie dobre navrhnuté. Diferenciálny prenos signálu taktiež eliminuje

vplyv kolísania zeme, pretože meria iba spomínaný rozdiel napätia medzi dvoma

vodičmi, ktoré sú pripojené na vstup ADC.

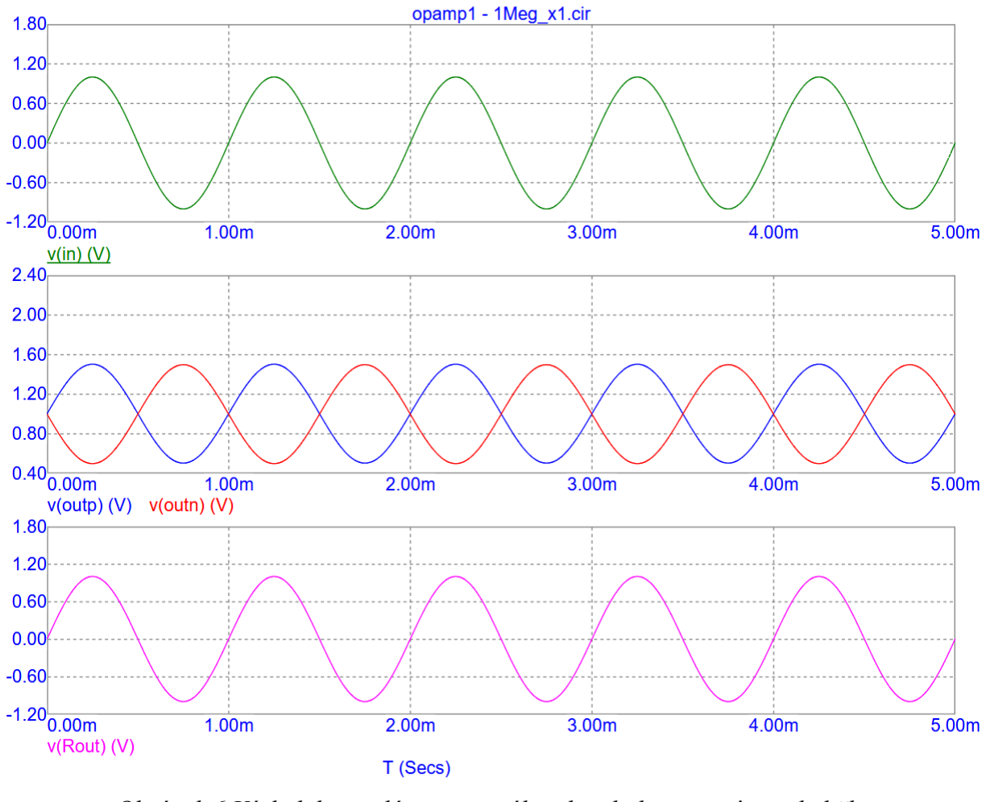
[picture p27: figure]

Obrázok 6 Výsledok simulácie vstupného obvodu bez napäťovej dedičky

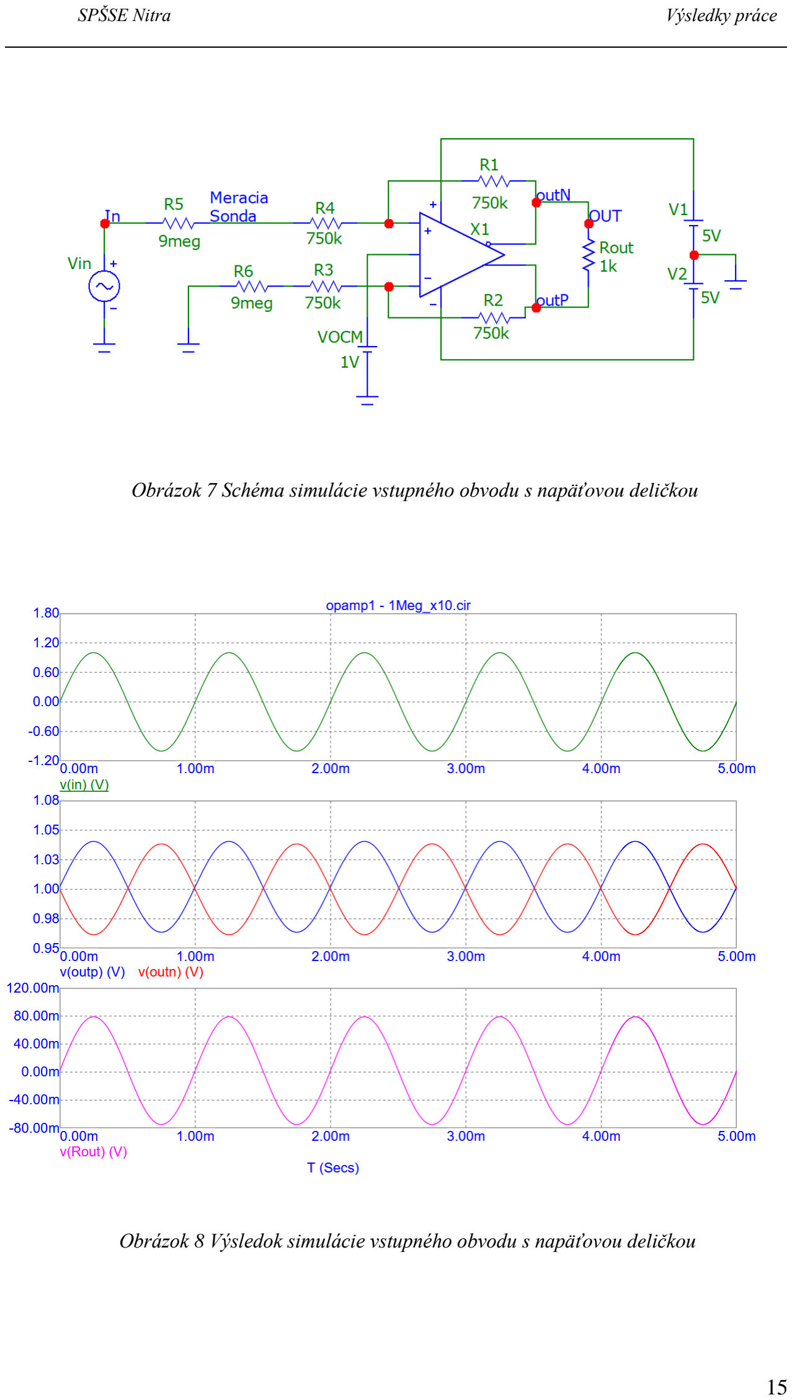
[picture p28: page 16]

Obrázok 7 Schéma simulácie vstupného obvodu s napäťovou deličkou

Obrázok 8 Výsledok simulácie vstupného obvodu s napäťovou deličkou

### 3.3 KOMUNIKÁCIA S AD8370

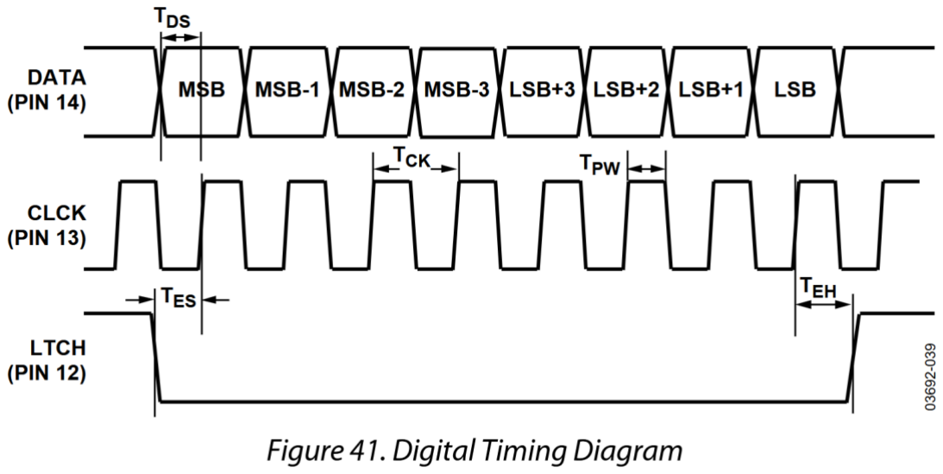
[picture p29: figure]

Obrázok 9 komunikácia na riadenie operačného zosilňovača s riaditeľným ziskom

Komunikáciu medzi VGA a mikrokontrolérom riadime sami, keďže sme museli

implementovať požadovaný riadiaci protokol nášho zosilňovača. VGA začína prijímať

hodnotu zosilnenia signálu zopnutím pinu LTCH na zem. Následne cyklicky zopíname

pin CLOCK, pričom pred každým zopnutím nastavíme hodnotu na pine DATA z výstupu

ESP32, keďže VGA číta hodnoty na nábežnú hranu signálu CLOCK.

Prenášané dáta do VGA tvoria 8-bitovú sériu, na základe ktorej sa nastavuje

hodnota zosilnenia. Prvý bit zo série, známy ako MSB (Most Significant Bit), sa používa

na prepínanie zosilňovača medzi režimami HIGH a LOW gain. Zvyšných 7 bitov slúži

na nastavenie konkrétnej hodnoty zosilnenia pre vybraný režim VGA.

### 3.4 NÁVRH DOSKY

Na návrh dosky plošných spojov sme použili Altium Designer, pretože poskytuje

veľmi dobré prostredie na prácu s komplikovanejšími návrhmi a zároveň obsahuje širokú

škálu knižníc súčiastok, čo výrazne uľahčilo proces návrhu.

Pre tento projekt sme sa rozhodli pre štvorvrstvovú dosku, aby sme

minimalizovali rušenie, keďže ide o merací prístroj, kde je dôležitá presnosť signálov.

Horná a dolná vrstva boli použité na signálové cesty, zatiaľ čo vnútorné vrstvy slúžili ako

polygóny pre GND. Tieto vrstvy boli prepojené prepojkami, čím sme zabezpečili kratšie

prúdové slučky a tým aj nižšie elektromagnetické rušenie.

Okrem toho sme impedančne prispôsobili dosku plošných spojov (PCB) podľa

impedančného profilu výrobcu, pričom sme zohľadnili hrúbku dielektrika, hrúbku medi

a šírku ciest, aby sme zabezpečili správne impedančné parametre a minimalizovali odrazy

signálu. Pri návrhu sme tiež dbali na správne rozloženie komponentov a napájacích trás,

čím sme zabezpečili spoľahlivú funkčnosť návrhu.

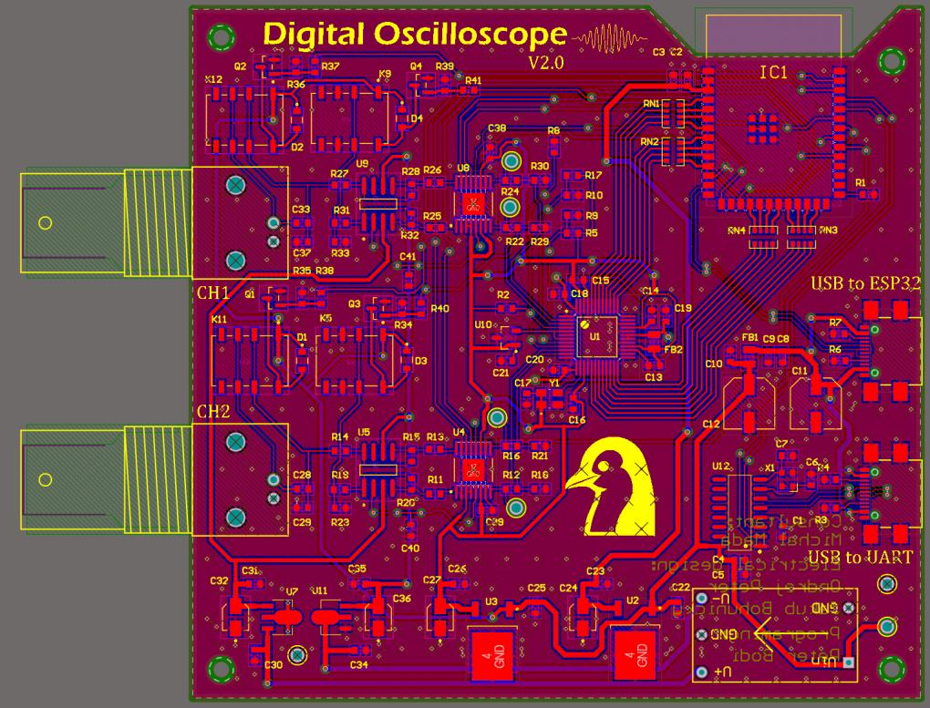
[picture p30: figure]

Obrázok 10 Návrh PCB

### 4 VÝSLEDKY PRÁCE

### 4.1 POPIS VIZUÁLNEJ ČASTI APLIKÁCIE

Aplikácia obsahuje hlavné okno, ktoré je rozdelené na niekoľko logických častí. Tieto

časti slúžia na ovládanie aplikácie, výber nastavení a zobrazovanie grafických

výstupov. Aplikácia je automaticky maximalizovaná hneď pri spustení, aby sa

využila celá plocha obrazovky.

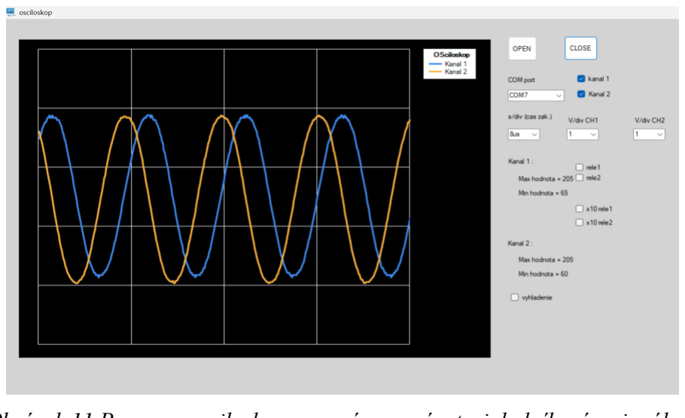
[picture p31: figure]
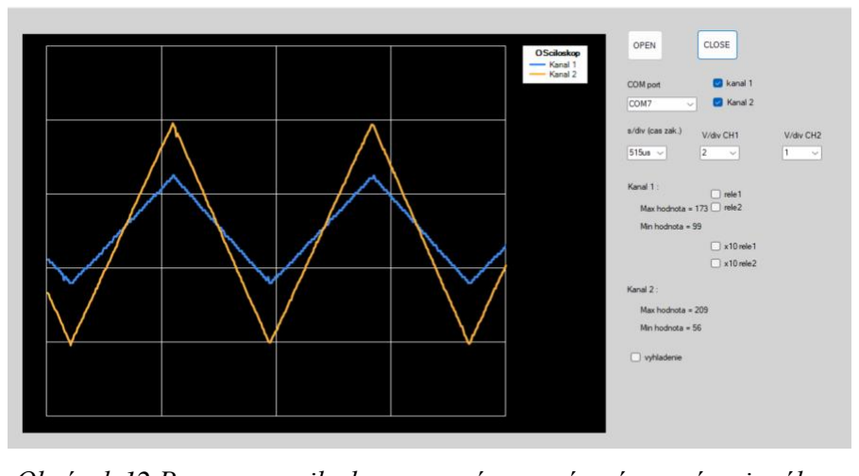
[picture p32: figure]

Obrázok 12 Program osciloskopu so znázorneným sínusovým signálom

Obrázok 11 Program osciloskopu so znázorneným trojuholníkovým signálom

Nastavenie a spustenie komunikácie:

- Nastavenie sériovej komunikácie:
- OPEN – tlačidlo, ktoré otvára sériový port a inicializuje komunikáciu

(realizované pomocou komponentu Button).

- CLOSE – tlačidlo, ktoré zatvára sériový port, avšak iba v prípade ak bol

vopred (realizované pomocou komponentu Button).

- Rozbaľovacie menu na výber COM portu - umožňuje výber portu na

komunikáciu so zariadením (realizované pomocou komponentu

comboBox).

- Menu pre voľbu časovej základne (t/div) - umožňuje výber časovej

základne osciloskopu v závislosti od frekvencie meraného signálu

komunikáciu so zariadením (realizované pomocou komponentu

comboBox).

- Menu pre voľbu napäťového rozsahu (U/div) - umožňuje nastaviť

napäťový rozsah v závislosti od amplitúdy meraného signálu komunikáciu

so zariadením (realizované pomocou komponentu comboBox).

- Tlačidlo SINGE CHANEL – tlačidlo slúžiace na voľbu zobrazenia

oboch meracích kanálov (dual chanel ) alebo iba jedného z nich (single

chanel), ak je tlačidlo aktívne osciloskop funguje ako jednokanálový, v

opačnom prípade zobrazuje súčasne oba meranie kanály (realizované

komponentom checkBox).

Zobrazovanie nameraných hodnôt:

Je realizované pomocou dvoch grafických panely, pričom každý zobrazuje jeden

z kanálov (vytvorené s použitím komponentu chart), na ktorých sú vykreslené dáta v

reálnom čase. Dáta sú zobrazené vo forme časového priebehu pre každý zo kanálov, teda

na osy X sa nachádza priebeh časovej základne osciloskopu a na osy Y sú zobrazované

namerané napäťové úrovne jednotlivých vzoriek. Pred každým nasledujúcim meracím

cyklom sú predchádzajúce vzorky odstránené a nahradené novými.

### 4.2 POPIS FUNGOVANIA APLIKÁCIE

Aplikácia funguje ako jednoduchý sériový plotter (zobrazovač), ktorý prijíma dáta

zo sériového portu (z mikropočítača) a zobrazuje ich v reálnom čase.

1. Inicializácia aplikácie
- Po spustení sa načítajú dostupné COM porty z počítača a pridajú sa do

rozbaľovacieho menu pre výber portu. Používateľ si môže vybrať port, ku

ktorému je pripojený osciloskop.

- Do ďalšieho rozbaľovacieho menu sa načítajú dostupné hodnoty pre časovú

základňu. Podľa tohto nastavenia si užívateľ volí aj vzorkovaciu frekvenciu,

keďže je závislá od nastavenie časovej základne.

- V poslednom rozbaľovacom menu je potrebné nastavenie požadovaného

napäťového rozsahu meraného signálu. V závislosti od tohto nastavenia dôjde k

prislúchajúcej konfigurácii meracích zosilňovačov.

- Sériový port je nakonfigurovaný na rýchlosť 460800 bajtov za sekundu, čo

umožňuje vysokorýchlostný prenos dát.

2. Otvorenie sériového portu
- Po kliknutí na tlačidlo OPEN sa otvorí vybraný sériový port. Program vyšle

inicializačné príkazy pozostávajúce zo zvolených rozsahov pre prvotné nastavenie

osciloskopu.

3. Prijímanie a spracovanie dát
- Program | neustále | kontroluje | prichádzajúce | dáta | pomocou | udalosti

„serialPort_DataReceived“. Dáta sú spracovávané na základe špecifických

podmienok:

- Ak je prijatá hodnota "CH1", program začne zapisovať prijaté dáta do poľa

určeného pre uloženie dát z prvého meracieho kanálu.

- Ak je prijatá hodnota "CH2", znamená to, že nasledujúce dáta budú

prislúchať k druhému kanálu a teda musia byť ukladané do prislúchajúcej

pozície v pamäti.

- Po odoslaní všetkých nameraných dát pre daný cyklus meracia je z

mikropočítača vyslaný príkaz „VYPIS“ čo počítaču signalizuje, že všetky

vzorky boli úspešne prijaté a môže prejsť na ďalší krok, ktorým je

vykreslenie nameraných priebehov pomocou volania metódy „Invoke“.

- Prijaté hodnoty sú rozdelené na vzorky a každá vzorka sa pridáva do

zodpovedajúceho grafu.

4. Zobrazovanie dát
- Metóda „Invoke“ vykresľuje získané dáta na grafy pre kanály 1 a 2 (prípadne len

jeden z nich ak je osciloskop nastavený ako jednokanálový).

- Pre každý kanál sú vykreslené dáta na osobitnom grafe. Používajú sa série bodov,

ktoré sa dynamicky aktualizujú s prichádzajúcimi dátami.

5. Zatvorenie sériového portu
- Tlačidlo CLOSE ukončí komunikáciu so zariadením tým, že zatvorí sériový port.

Tým sa zabráni ďalšiemu prijímaniu dát. Toto tlačidlo slúži teda najmä pre

dočasné zastavenie príjmu ďalších dát a umožnenie analýzy vzoriek už prijatých.

### 4.3 PROGRAMOVÝ CYKLUS

Konfigurácia meracieho zosilňovača – pred každým meracím cyklom je

potrebné nastaviť napäťové zosilnenie meraného signálu pomocou meracieho

zosilňovača. Hodnota zosilnenia je reprezentovaná osem bitovým číslom prislúchajúcim

k napäťovému rozsahu, ktorý si užívateľ zvolil v grafickom rozhraní vytvorenom pre toto

zariadenie. Toto nastavenie meracieho zosilňovača je realizované formou synchrónnej

komunikácie upravenej na parametre vyžadované dokumentáciou použitého zosilňovača.

Na komunikáciu medzi mikropočítačom (ESP32) a meracím zosilňovačom sú použité tri

GPIO piny mikropočítača vopred nakonfigurované na účel tejto komunikácie. Prenos dát

začína prepnutím pinu pripojeného na povoľovací vstup zosilňovača do logickej nuly,

následne sa po jednotlivých bitoch prenesie číslo zodpovedajúce zvolenému rozsahu, čo

je realizované spínaní GPIO pinu pripojeného na dátový vstup zosilňovača, aktuálne

hodnota na tomto pine závisí od vymaskovanej hodnoty čísla reprezentujúceho zvolený

rozsah a rýchlosť toho spínania závisí od rýchlosti hodinového (synchronizačného) cyklu,

ktorý sa vysiela na hodinový (CLK) vstup zosilňovača. Po odoslaní ôsmych bitov reprezentujúcich zvolený rozsah sa povoľovací vstup prepne spať do logickej nuly čo

signalizuje ukončenie komunikácie. Po ukončení komunikácie s meracím zosilňovačom nastane v programe pauza o dĺžke 1µs. Táto pauza slúži na zaistenie toho, že merací

zosilňovač stihol korektne nastaviť požadované zosilnenie. Toto nastavenie je zhodné pre

zosilňovače oboch kanálov.

Odoberanie vzoriek meraného priebehu – Samotné meranie pozostáva z

viacerých častí. Prvou je odoberanie vzoriek meraného signálu v digitálnej forme z

výstupu AD prevodníka, ktorého úlohou je prevádzať analógovú hodnotu napätia

privádzaného na jeho vstup na osem bitové číslo reprezentované logickými hodnotami na

jeho výstupných pinoch. Táto forma výstupu z AD prevodníka umožňuje paralelné čítanie

všetkých bitov súčasne, čo výrazne zvyšuje rýchlosť zápisu do pamäti mikropočítača v

porovnaní so sériovým čítaním jednotlivých bitov. Keďže táto forma výstupu po prvotnej

konfigurácii spojovacích pinov umožňuje priamy zápis priamo do registrov oboch jadier

procesora účastne. Následne sú hodnoty z oboch registrov zapísané do zodpovedajúcich

buniek vnútornej pamäte mikropočítača. Ako najrýchlejšie riešenie pre tento zápis sme

sa rozhodli pre implementáciu rutiny assmbleru, keďže vykonanie tejto inštrukcie trvá

len jeden hodinový cyklus procesora, čo umožňuje dosiahnuť vyššiu vzorkovaciu

frekvenciu v porovnaní s použitím bežných inštrukcii jazyka C v, ktorom sú realizované

ostatné časti programu. Po načítaní vzorky nasleduje oneskorenie, ktoré je realizované

taktiež pomocou ruty assembleru s názvom „nop“, ktorá reprezentuje len prázdnu

inštrukciu pre procesor, ktorá však trvá len jeden takt procesora teda je ňou možné vytvoriť veľmi presné oneskorenia a to už od dĺžky jednotiek nanosekúnd pre meranie

veľmi vysokých frekvencii, až po niekoľko sekundové oneskorenia pre meranie

frekvencii menších ako 1Hz. Po uplynutí oneskorenia dôjde k odobraniu ďalšej vzorky vyššie uvedeným spôsobom. Dĺžka tohto oneskorenia závisí od zvoleného časového

rozsahu, ktorý udáva s akou frekvenciou sa má meraný signál vzorkovať.

Komunikácia s počítačom – Po uložení dát opisujúcich meraný priebeh do

vnútornej pamäti mikropočítača sú následne odosielané cez rozhranie UART (USB) do

pripojeného počítača na následné spracovanie a vykreslenie užívateľovi. Z dôvodu

zvýšenia rýchlosti prenosu sa namerané dáta odosielajú v upravenom formáte, táto úprava

spočíva v odosielaní viacerých vzoriek v jednom prenášanom reťazci v, ktorom sú

jednotlivé hodnoty oddelené vopred definovaným znakom. Toto riešenie sme zvolili aj napriek tomu, že komunikačná rýchlosť (bound rate) by mala postačovať aj na

odosielanie každej hodnoty oddelene, tu však narážame na obmedzenia systému v ktorom

bola vyvinutá aplikácia prijímajúca dáta, ktorá neumožňuje ukladať prijaté dáta pri danej

rýchlosti. Preto je potrebné viacero vzoriek vkladať do jedného prenosového reťazca

ktorý je po prijatí v PC korektne uložený a dekódovaný. Po odoslaní všetkých vzoriek sa

mikropočítač vráti do stavu čakania na to, kým mu bude z PC vyslaný napäťový a časový

rozsah (ako je bližšie uvedené v časti 2.) a po prijatí týchto rozsahov sa celým merací

cyklus (body 2. až 4.) spustí znovu.

### 4.4 VÝSLEDNE VYHOTOVENIE

Počas vývoja sme narazili na viaceré problémy, pričom jedným z najvýraznejších

bol nesprávny offset na diferenciálnych pároch medzi naším VGA a ADC prevodníkom.

Náš VGA poskytuje na pine VOCM napätie, ktoré sa rovná presne polovici jeho

napájacieho napätia, čo v našom prípade predstavovalo 3.33V / 2 = 1.67V. Toto napätie

následne ovplyvňovalo prvý vstupný operačný zosilňovač, ktorý posunul úroveň signálu

príliš vysoko. Náš ADC však vyžaduje, aby bol offset diferenciálnych párov presne 1V.

Aby sme tento problém odstránili v novej generácii dosiek, implementovali sme

napäťový delič na vstupoch, ktorý prispôsobuje úroveň signálu na požadovanú hodnotu 1V. Ďalším problémom bolo dosiahnutie dostatočne vysokej vzorkovacej frekvencie pri

použití mikrokontroléra ESP32, ktorý beží na frekvencii 240 MHz. Pri bežnom čítaní

údajov z ADC pomocou štandardných knižníc sme dosahovali vzorkovaciu frekvenciu

len približne 60 MHz. Aby sme tento výkon zvýšili, implementovali sme špeciálne

assemblerové inštrukcie, ktoré umožňujú extrémne rýchle načítanie celého registra v

jednom inštrukčnom cykle. Z tohto dôvodu sme prešli na model ESP32-S3, ktorý

podporuje tieto optimalizované príkazy. Táto zmena nám umožnila výrazne zvýšiť vzorkovaciu frekvenciu. Ďalšou optimalizáciou bolo paralelné spracovanie dát pomocou

oboch jadier, ktoré ESP32 ponúka. Vďaka všetkým týmto vylepšeniam sme boli schopní

dosiahnuť maximálnu vzorkovaciu frekvenciu 120 MHz.

Ku doske sme spravili krabičku pomocou 3D modelu PCB z Altium Designera, ktorú

sme vymodelovali vo fusion 360. Následne sme ju vytlačili na 3D tlačiarni.

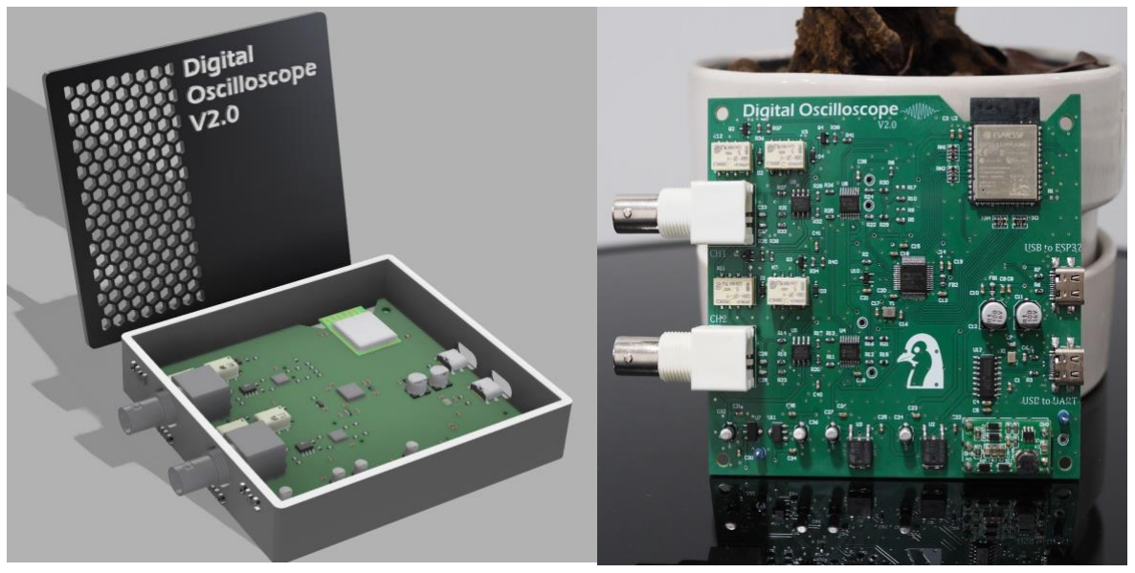
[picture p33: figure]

### 4.5 MERANIE CHARAKTERISTÍK OSCILOSKOPU

Pre overenie správnej funkčnosti a dôveryhodnosti nášho osciloskopu sme sa

rozhodli zmerať jeho vlastnosti. Ako môžeme vidieť, závislosť napätia, ktoré osciloskop

nameria na základe jeho výstupu (obr. č. 15), je lineárna. To znamená, že merania sú

konzistentné a odchýlky minimálne, čo potvrdzuje presnosť zariadenia. Pri frekvenčnej

charakteristike (obr. č. 16) sa priebeh mierne mení so zvyšujúcou sa frekvenciou. Ak sa

však pozrieme na úrovne napätia, zmena medzi minimálnou a maximálnou meracou

frekvenciou bola len 120 mV. Vzhľadom na široké frekvenčné spektrum od 1 kHz až po

1 MHz považujeme tento výsledok za dostatočný a vyhovujúci požiadavkám merania.

Obrázok 13 3D model s krabičkou | Obrázok 14 Vyhotovenie PCB

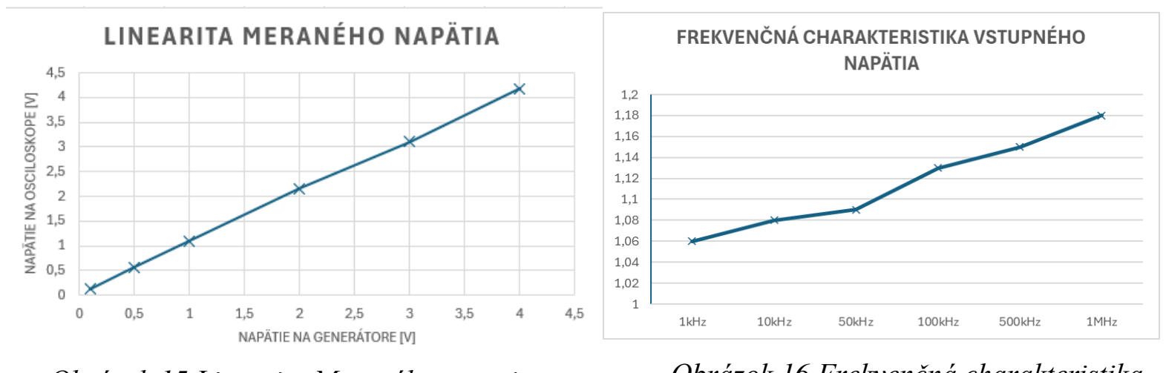
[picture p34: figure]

Obrázok 16 Frekvenčná charakteristika

vstupného napätia pri vstupe 1V

Obrázok 15 Linearita Meraného napätia

SPŠSE Nitra | Diskusia

25

DISKUSIA

Porovnaním nášho digitálneho USB osciloskopu s komerčne dostupnými

riešeniami sme zistili, že napriek nízkym výrobným nákladom približne 30 eur poskytuje

dostatočný výkon pre bežné merania. Zariadenie dosahuje vzorkovaciu frekvenciu

100 MSa/s a ponúka dva kanály, čo ho radí medzi cenovo dostupné, no funkčne adekvátne

riešenia. Tento výsledok je porovnateľný s inými lacnejšími USB osciloskopmi a

potvrdzuje, že aj ekonomicky výhodné zariadenia môžu ponúknuť dostatočne dobré

parametre aj pre náročnejšie aplikácie.

Osciloskop je vybavený vlastnou softvérovou aplikáciou pre počítač, ktorá

umožňuje sledovanie signálových priebehov v reálnom čase a poskytuje základné

analytické funkcie potrebné pre diagnostiku elektronických obvodov. Testovanie

preukázalo stabilnú prevádzku a dostatočnú presnosť, čím sa zariadenie stáva vhodným

pre široké spektrum aplikácií.

SPŠSE Nitra | Závery práce

26

ZÁVERY PRÁCE

V tejto práci sme dosiahli splnenie cieľov stanovených v úvode. Počas realizácie

však nastali určité úpravy, ako napríklad optimalizácia vstupného obvodu pre zlepšenie

presnosti merania a umožnenie pripojenia sondy s deličkou x10.

Účelom tejto práce bolo vytvoriť digitálny osciloskop, ktorý umožní efektívnu

analýzu elektrických signálov a poskytne intuitívne zobrazenie meraných údajov.

Výsledný systém môže byť využitý na vzdelávacie účely, vývoj elektronických obvodov

či diagnostiku rôznych elektrických zariadení.

Jedným z možných vylepšení tejto práce by bolo rozšírenie komunikačných

možností pridaním bezdrôtového prenosu dát cez Wi-Fi alebo Bluetooth, čím by sa

zvýšila mobilita zariadenia a umožnilo by sa jeho ovládanie cez mobilné aplikácie. Ďalšou možnosťou by bola implementácia spektrálnej analýzy pomocou FFT.

Tento produkt sa vyznačuje kompaktným dizajnom a jednoduchým napájaním cez

USB rozhranie, čo umožňuje jeho použitie kdekoľvek s počítačom, pričom náklady na

výrobu sa relatívne nízke.

SPŠSE Nitra | Zhrnutie

27

ZHRNUTIE

Cieľom tejto práce bolo navrhnúť a realizovať digitálny USB osciloskop, ktorý

umožňuje presnú analýzu elektrických signálov v reálnom čase. Dosiahli sme to návrhom

a implementáciou hardvérového zariadenia na báze vysokorýchlostného AD prevodníka,

ktoré zabezpečuje vzorkovanie signálu a jeho následné spracovanie. Meranie prebiehalo

prostredníctvom mikrokontroléra, ktorý riadil komunikáciu medzi osciloskopom a

počítačom cez USB rozhranie. Namerané údaje boli zobrazované v softvéri na PC, ktorý

poskytoval vizualizáciu signálov vo forme časových priebehov. Softvér zároveň

umožňoval analýzu kľúčových parametrov signálu. Vďaka možnosti nastavenia rôznych

vzorkovacích frekvencií a režimov záznamu bolo možné efektívne skúmať správanie

elektrických obvodov v širokom frekvenčnom rozsahu. Systém tak poskytuje komplexný

nástroj na diagnostiku signálov, identifikáciu porúch a analýzu dynamických vlastností

obvodov, pričom jeho flexibilita a použitie softvérových algoritmov umožňujú presné

spracovanie a vizualizáciu meraných dát.

SPŠSE Nitra | Resume

28

RESUME

The aim of this work was to design and implement a digital USB oscilloscope that

enables precise real-time analysis of electrical signals. We achieved this by designing and

implementing a hardware device based on a high-speed ADC, ensuring signal sampling

and subsequent processing. The measurement was carried out using a microcontroller that

managed communication between the oscilloscope and a computer via a USB interface.

The measured data was displayed in PC software, which provided signal visualization in

the form of time waveforms. The software also enabled the analysis of key signal

parameters. Thanks to the ability to set various sampling frequencies and recording

modes, it was possible to effectively study the behavior of electrical circuits across a wide

frequency range. This system thus provides a comprehensive tool for signal diagnostics,

fault identification, and analysis of circuit dynamic properties, while its flexibility and

use of software algorithms allow for precise processing and visualization of measured

data.

SPŠSE Nitra | Zoznam bibliografických odkazov

29

ZOZNAM BIBLIOGRAFICKÝCH ODKAZOV

ADC, Marcel JM Pelgrom [cit.25.2.2025].

Marcel J. M. Pelgrom 2022, Analog-to-Digital Conversion, Helmond, Netherlands

1032 strán, (ISBN 978-3-030-90808-9)

Blokový diagram procesora Xtensa LX7 používaný v ESP32

[cit.25.2.2025]. Dostupné na internete :

<https://www.cadence.com/en_US/home/resources/datasheets/xtensa-lx7-processor-

ds.html>.

OPERAČNÉ ZOSILŇOVAČE [cit.25.2.2025].

Sergio Franco 2015, Design with Operational Amplifiers and Analog Integrated Circuits

San Francisco, USA, 733 strán (ISBN 978-0-07-802816-8)

OSCILOSKOP [cit.25.2.2025].

David Herres 2020, Oscilloscopes: A Manual for Students, Engineers, and Scientists

Clarksville, USA, 276 strán (ISBN 978-3-030-53885-9)

TYPY OSCILOSKOPOV

[cit.25.2.2025]. Dostupné na internete :

<https://www.keysight.com/used/us/en/knowledge/guides/used-oscilloscope-buying-

guide/types-of-oscilloscope>.

ZOZNAM PRÍLOH

Príloha A – Schéma

Príloha B – CD so zdrojovým kódom a vizuálnou časťou aplikácie

## PRÍLOHA A

CELKOVÁ SCHÉMA ZAPOJENIA

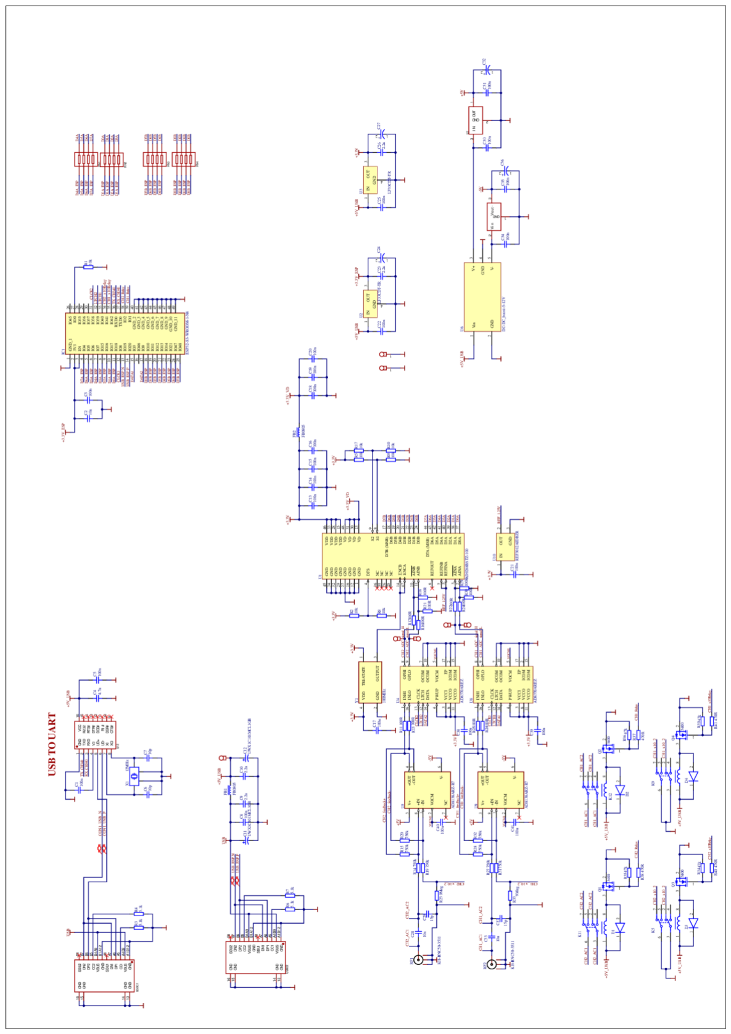
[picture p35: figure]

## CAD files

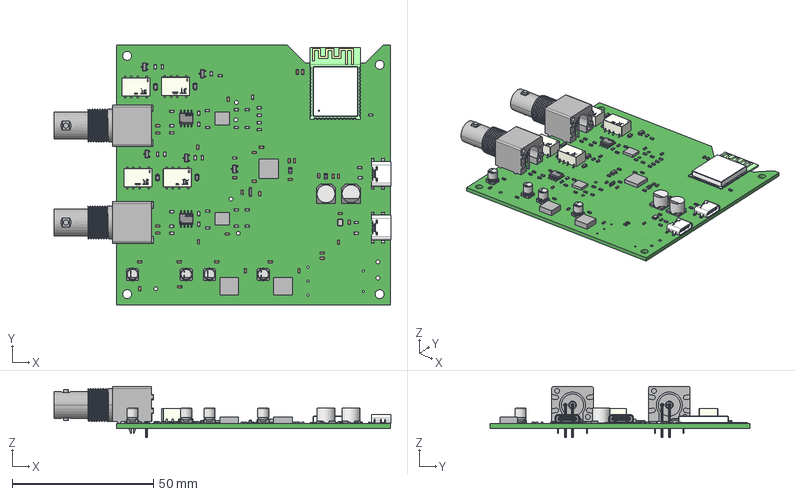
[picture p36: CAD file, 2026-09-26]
PCBs/Oscilloscope_V02/3D model_V02.step
119.5 x 92.1 x 18.2 mm
C0603 x 35
R0603 x 41
pins x 6
logo x 6
73100-0131_RGB8421504 x 2
ON Semi Logo - withoutPN x 4
ON Semi Logo - withoutPN - Copy x 4
TE Connectivity IM43GR 1 x 4
Omron G6K-2F-Y-TR-DC5 2 x 16
Omron G6K-2F-Y-TR-DC5 2_MIR2 x 16
TE Logo x 4
ROHM Logo x 4
Extruded x 5
ECS-250-6-33B2-CTN-TR3
XTAL-2520
USB_C_USB4135-GF-A x 2
BODY_MF03A
LEAD_MF03A x 3
base x 4
cap x 4
lead x 4

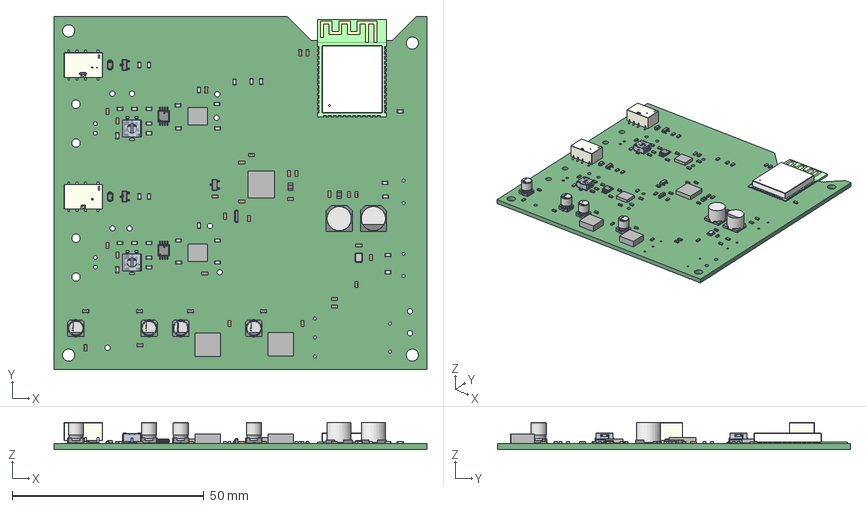
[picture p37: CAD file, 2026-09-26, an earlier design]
PCBs/Oscilloscope_V01/3D model_V01.step
97.2 x 92.1 x 7.14 mm
C0603 x 33
Extruded x 5
ECS-250-6-33B2-CTN-TR3
XTAL-2520
BODY_MF03A
LEAD_MF03A x 3
Leg x 2
Analog Devices Logo x 2
R0603 x 34
3314G1 x 2
ON Semi Logo - withoutPN x 2
ON Semi Logo - withoutPN - Copy x 2
TE Connectivity IM43GR 1 x 2
Omron G6K-2F-Y-TR-DC5 2 x 8
Omron G6K-2F-Y-TR-DC5 2_MIR2 x 8
TE Logo x 2
ROHM Logo x 2
base x 4
cap x 4
pins x 4
logo x 4
lead x 4

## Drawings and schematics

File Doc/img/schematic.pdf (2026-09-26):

# USB TO UART

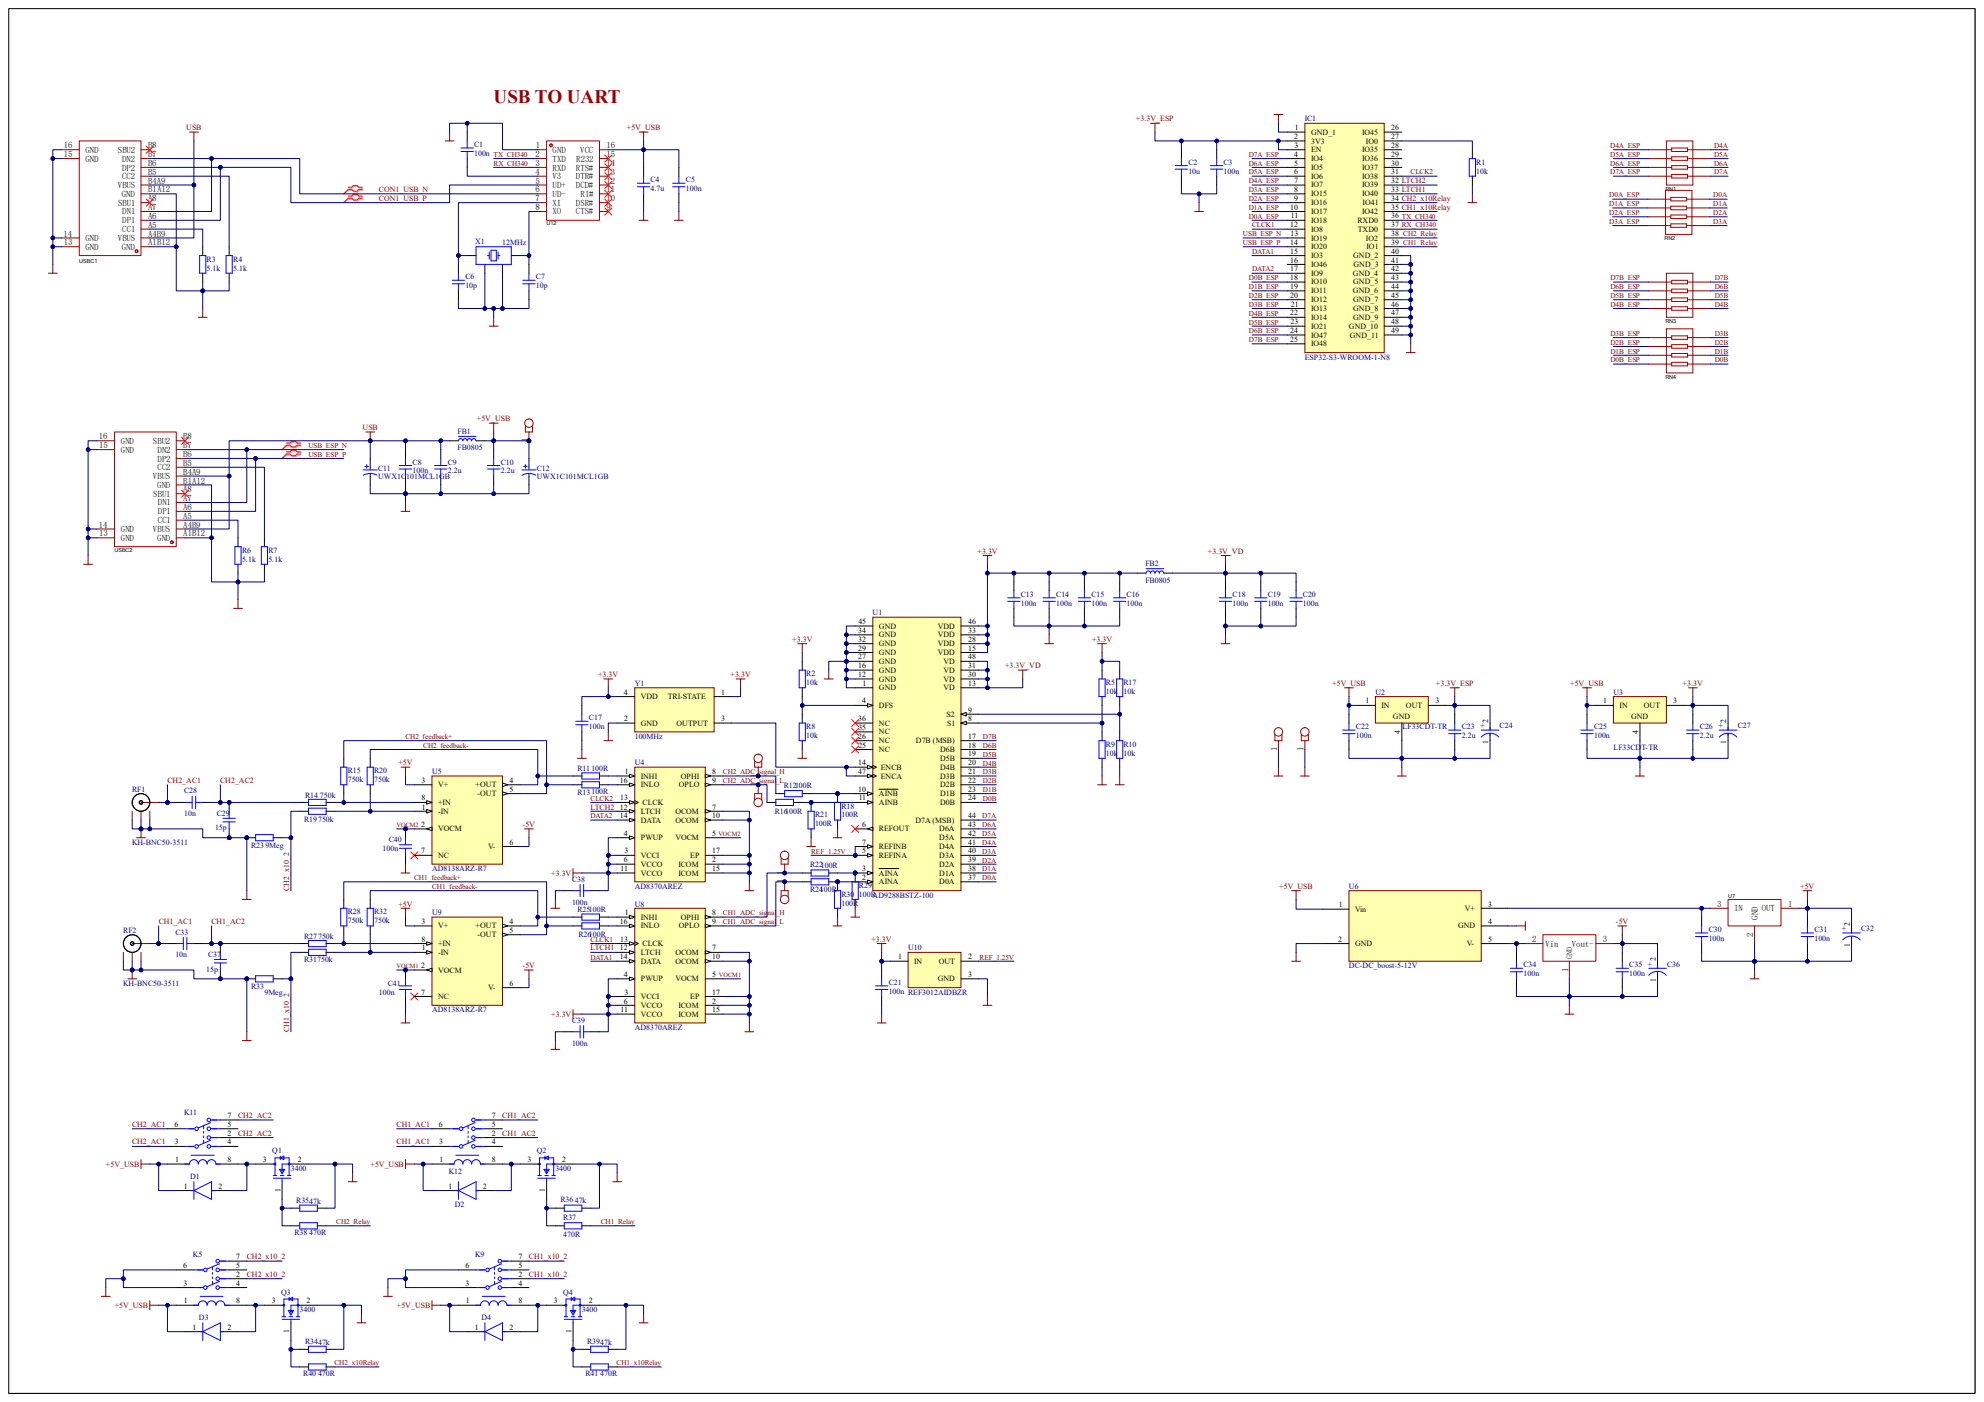
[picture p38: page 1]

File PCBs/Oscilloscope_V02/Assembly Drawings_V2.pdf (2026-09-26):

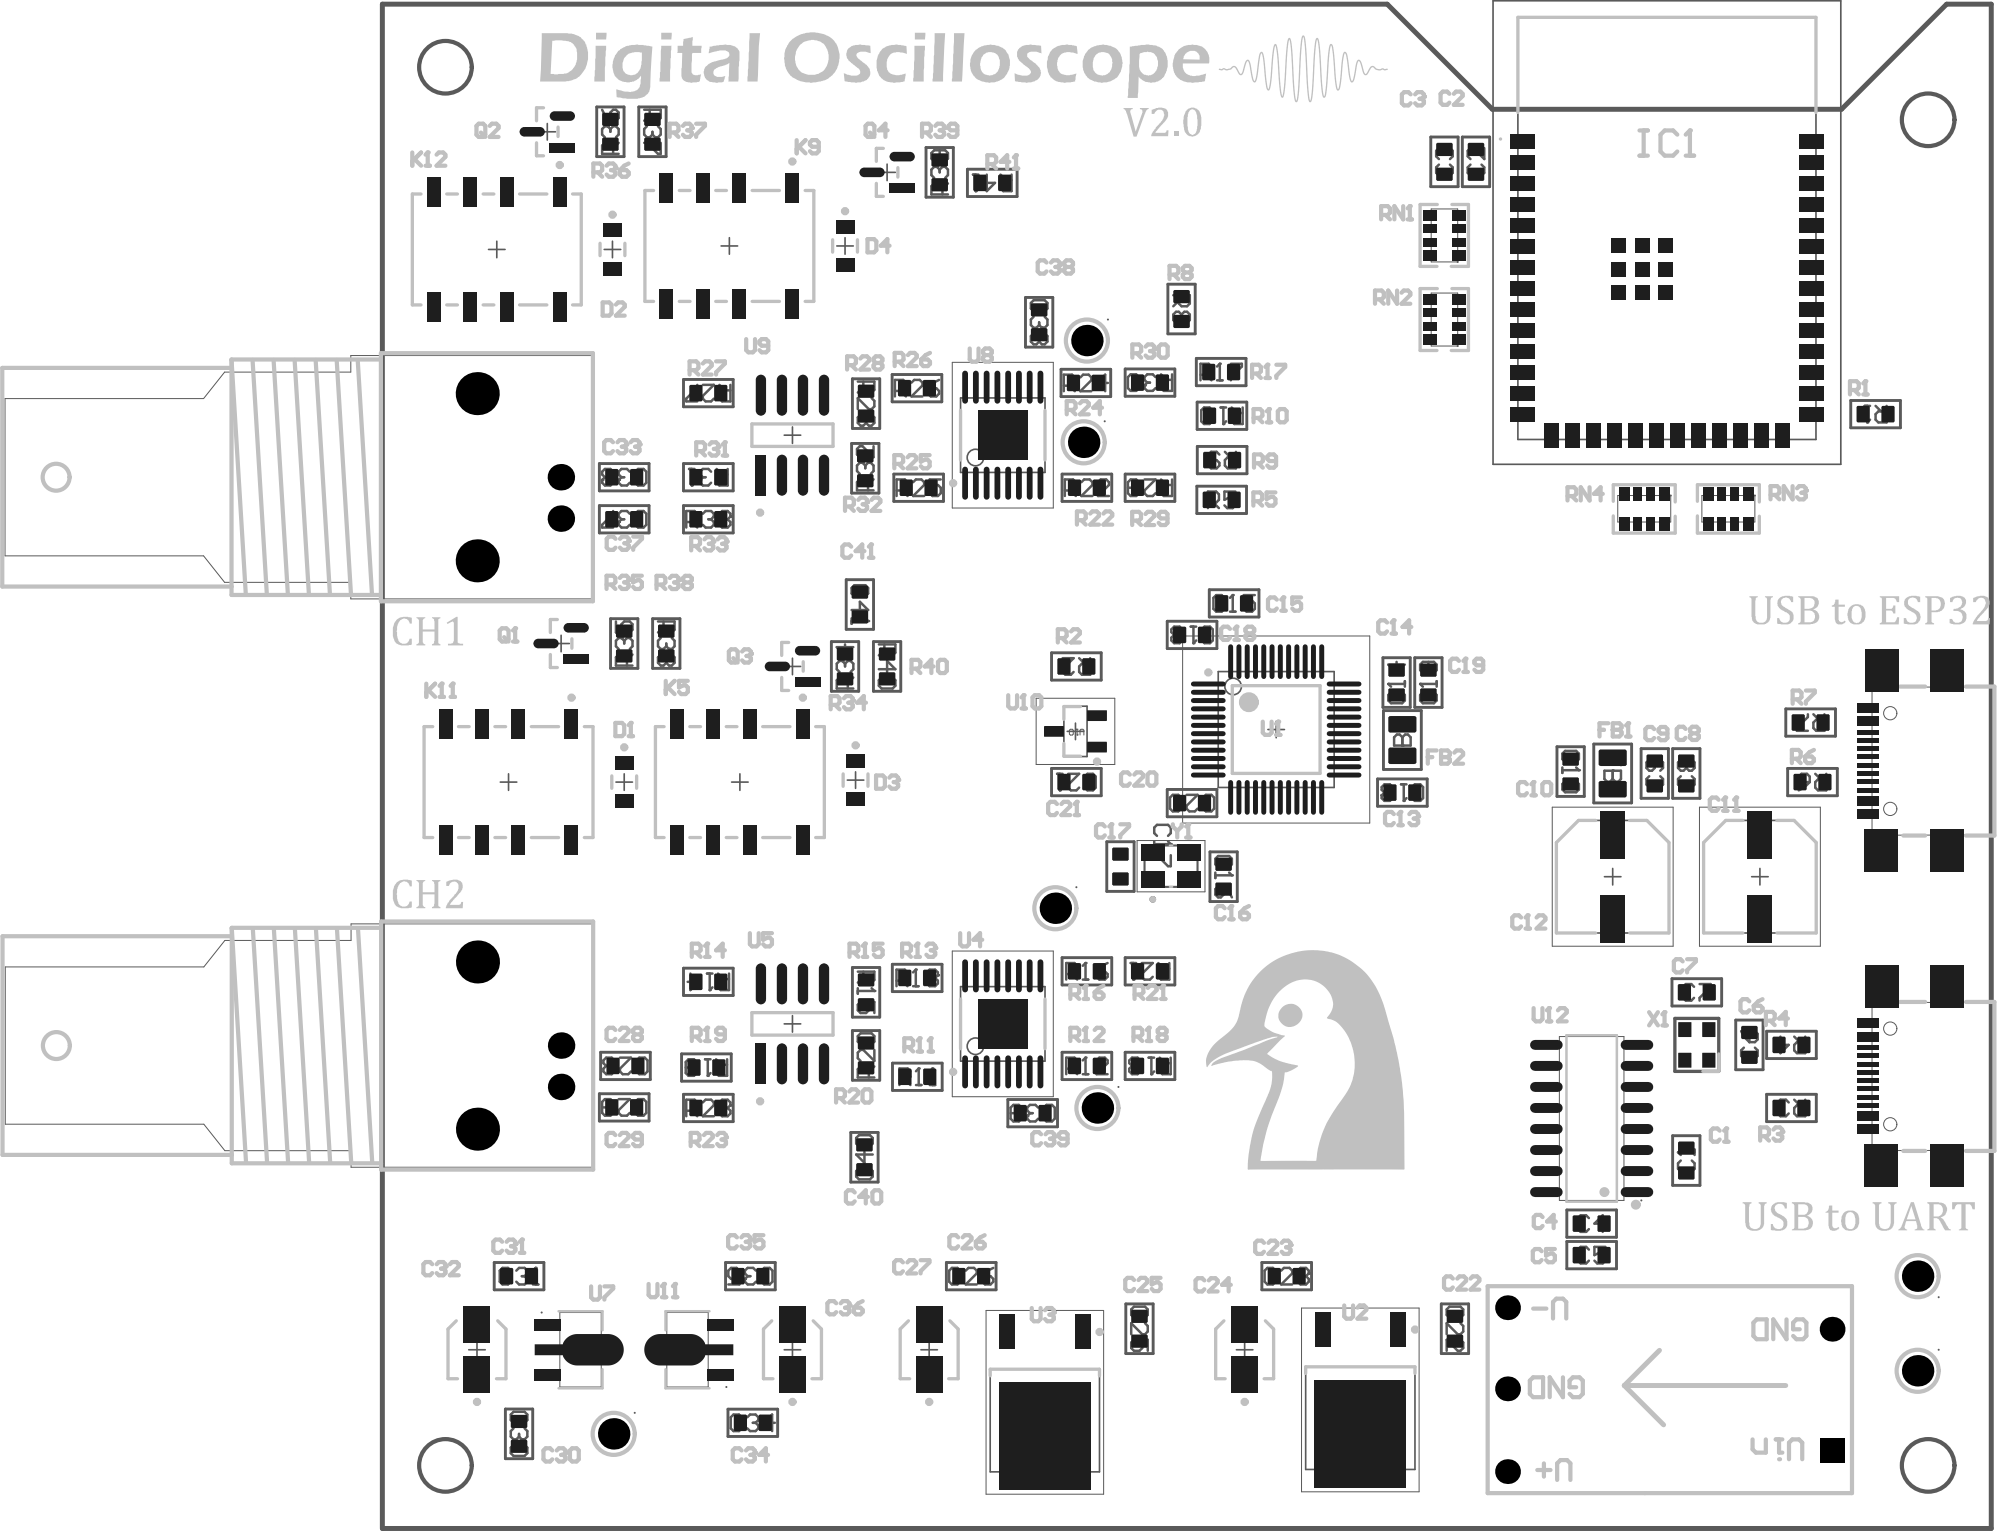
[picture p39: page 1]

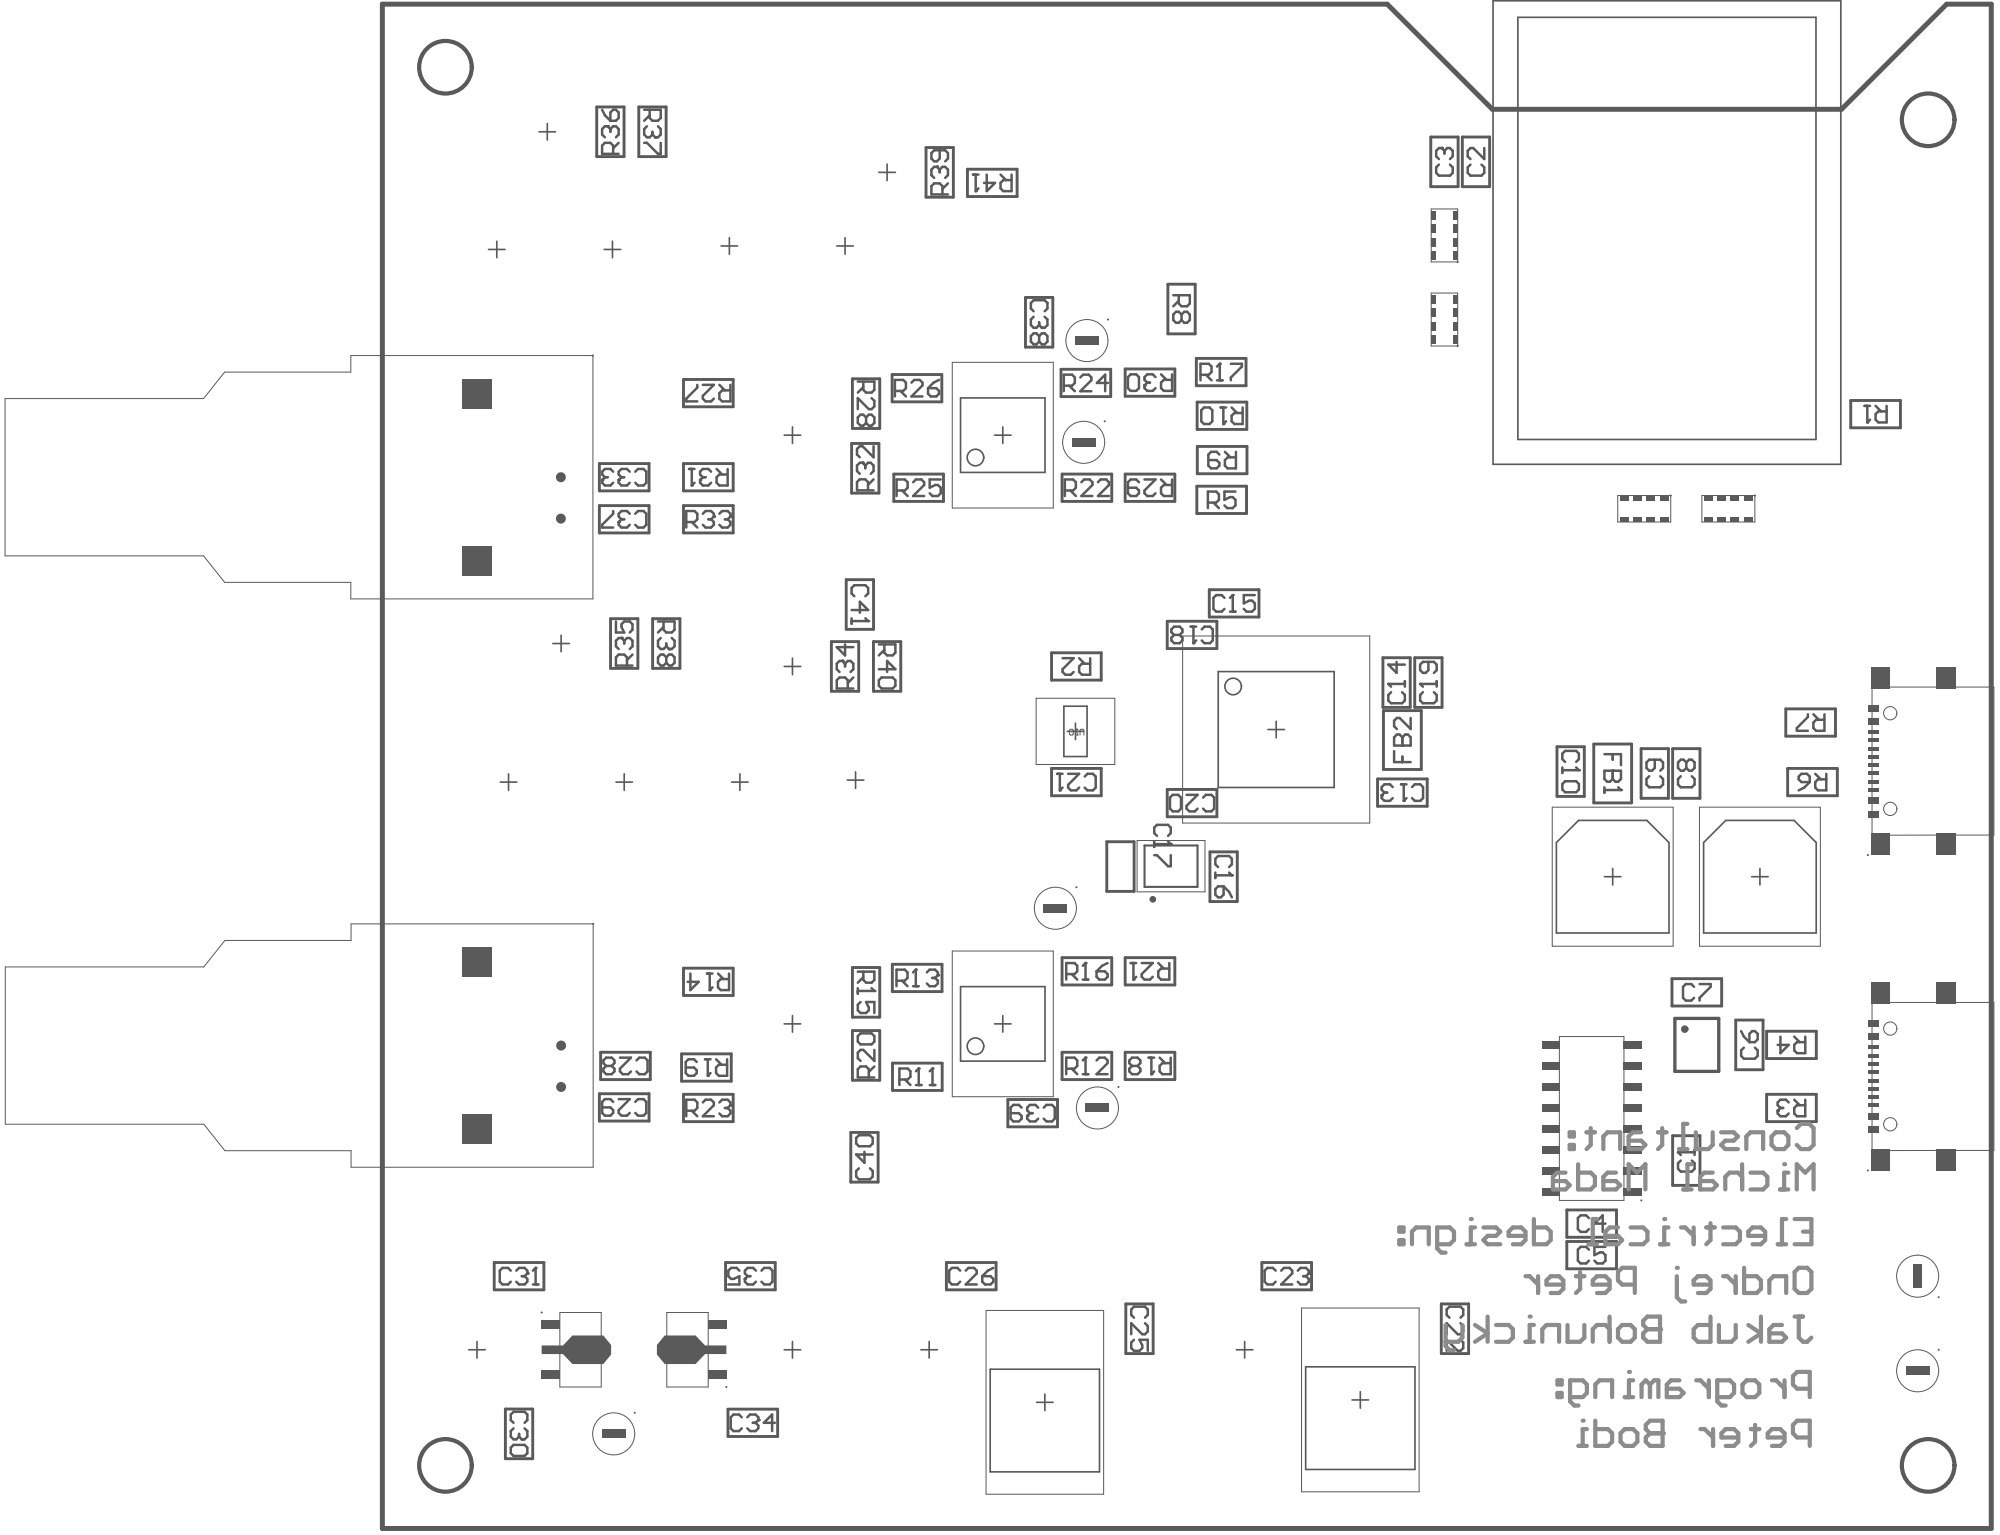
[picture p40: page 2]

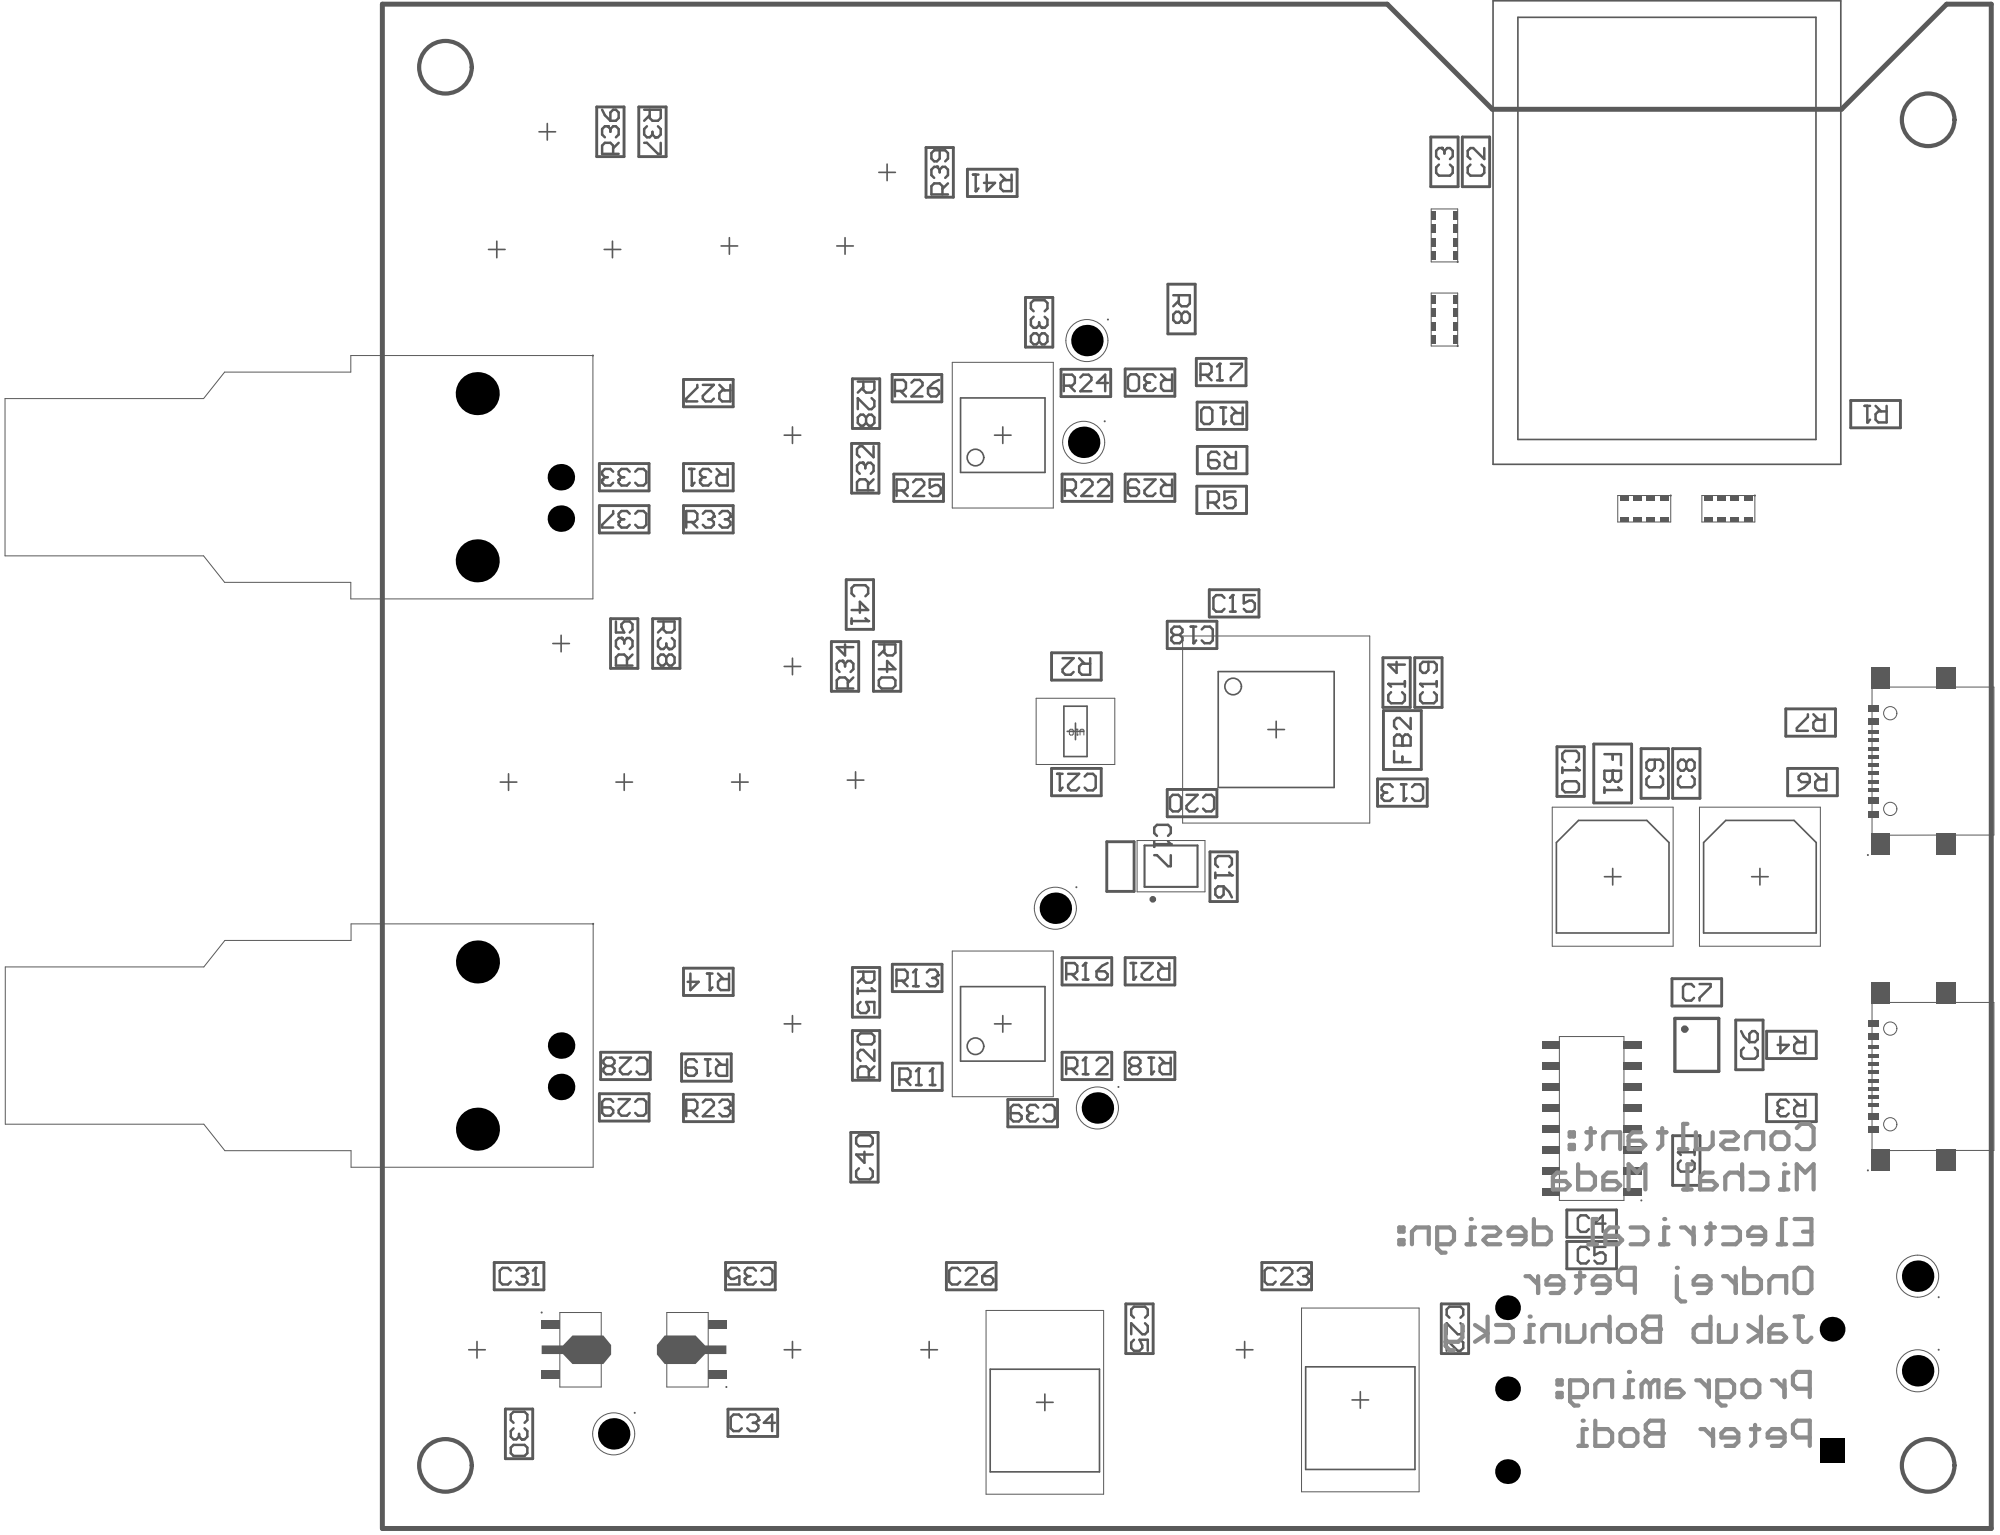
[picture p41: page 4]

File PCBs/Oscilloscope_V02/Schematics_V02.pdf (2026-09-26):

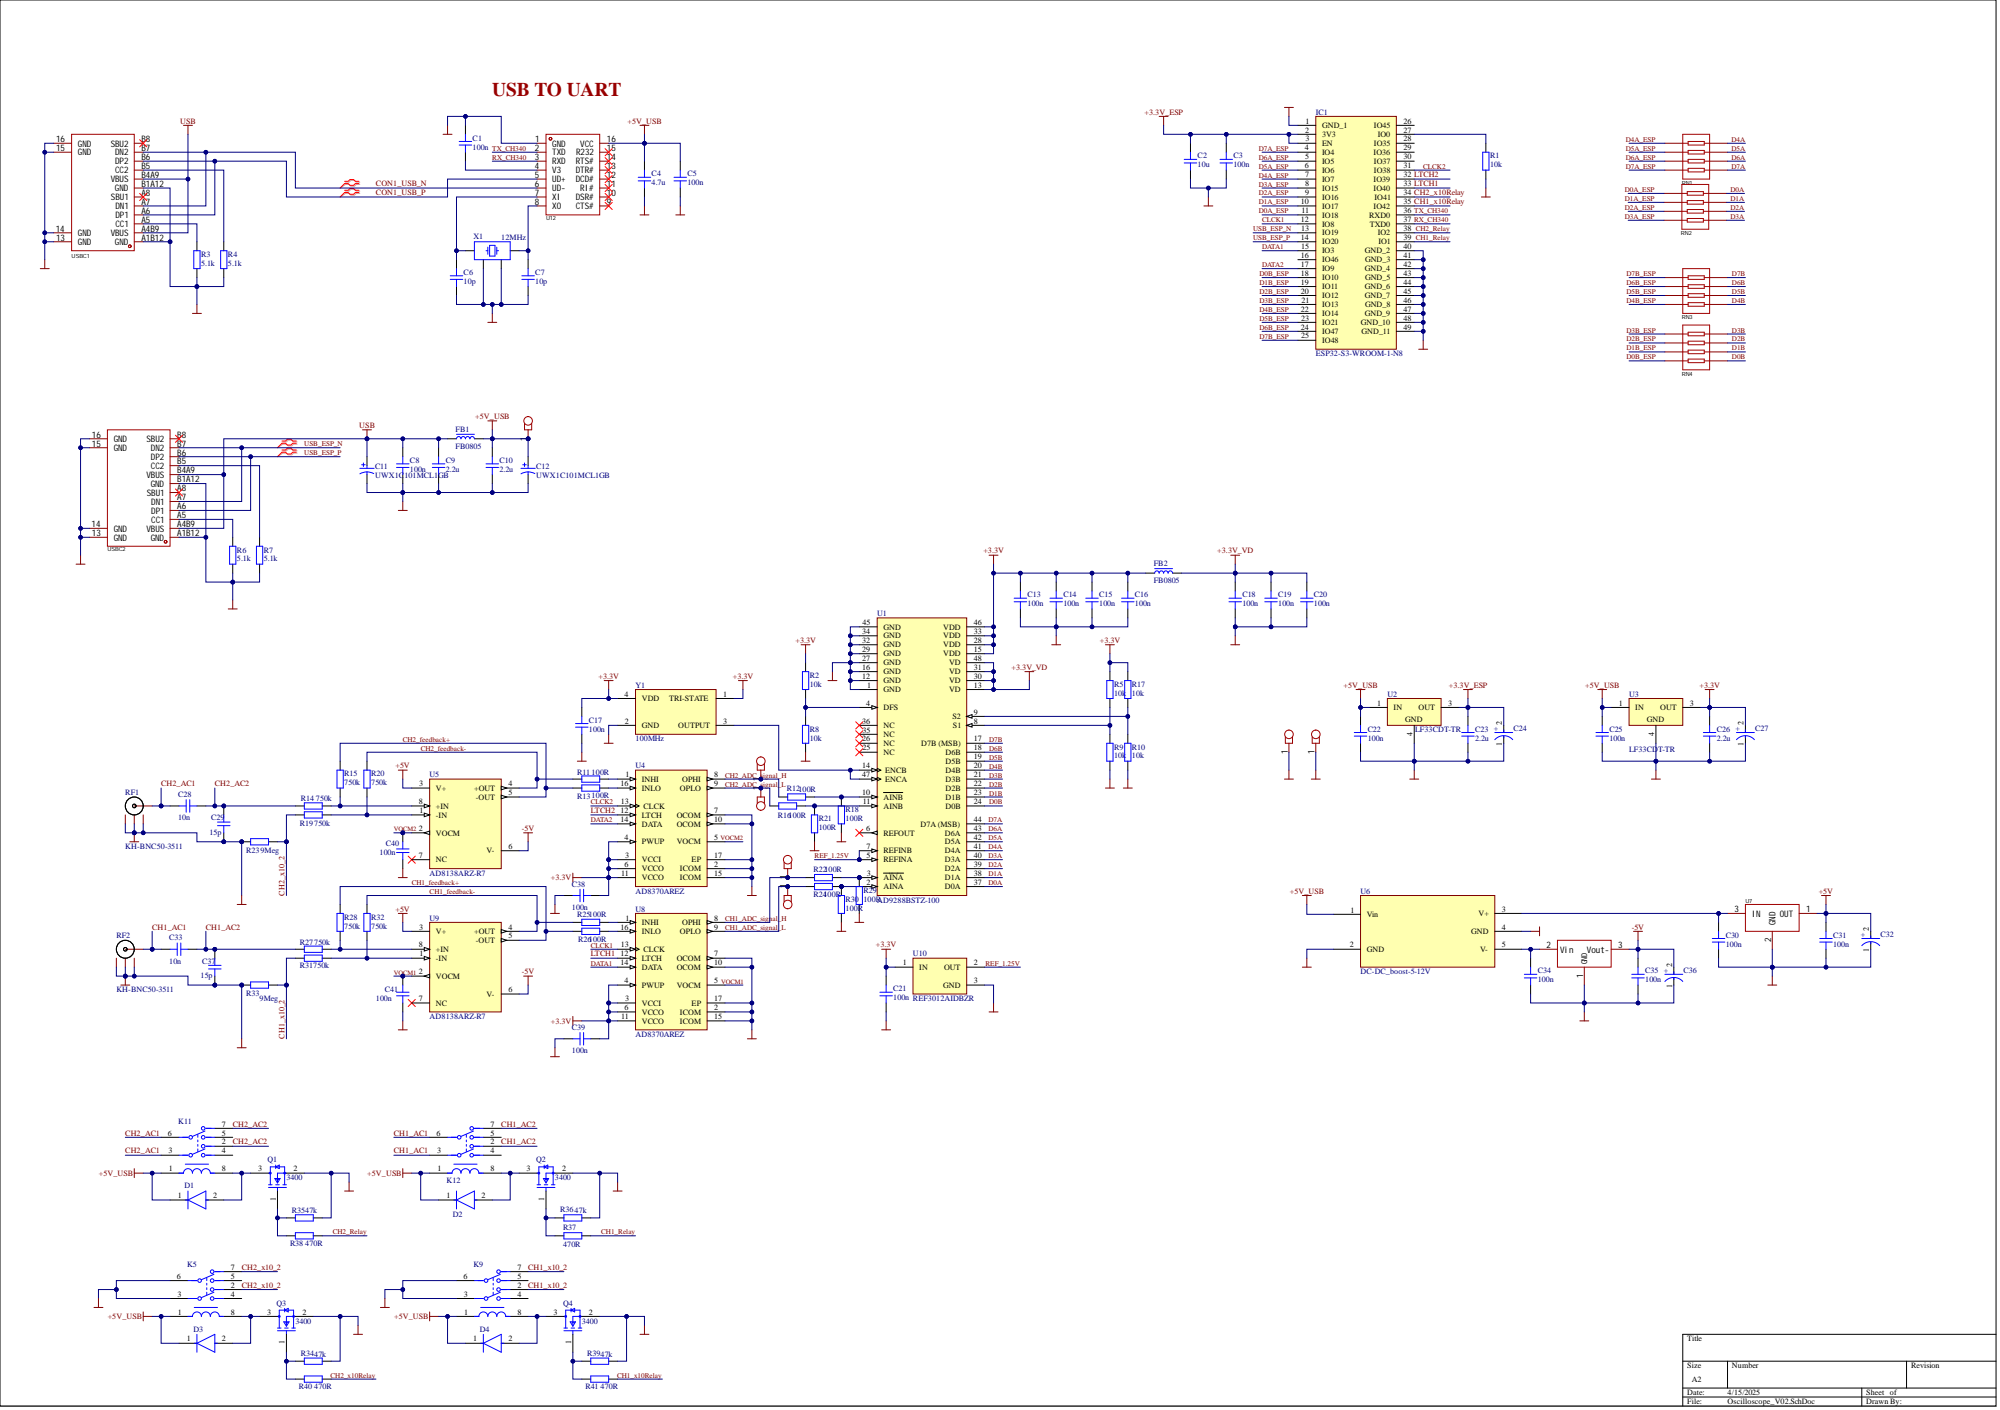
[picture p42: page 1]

+IN 8 | | | CLCK2

-IN 1 | LTCH2 | LTCH 12 CLCK 13 | | REFOUT 6

+IN 8 | | CLCK1

-IN 1 | LTCH1 | | LTCH 12 CLCK 13

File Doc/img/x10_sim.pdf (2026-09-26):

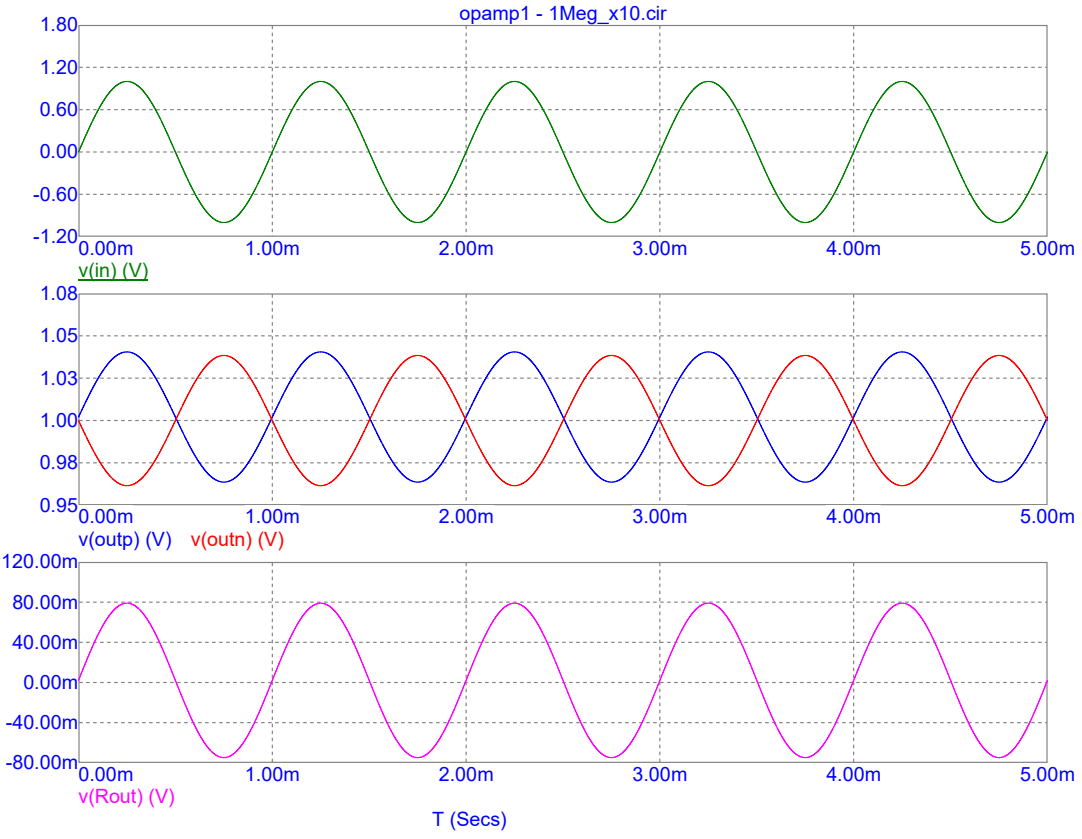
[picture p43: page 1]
v(outp) (V) v(outn) (V); v(Rout) (V); T (Secs); opamp1 - 1Meg_x10.cir

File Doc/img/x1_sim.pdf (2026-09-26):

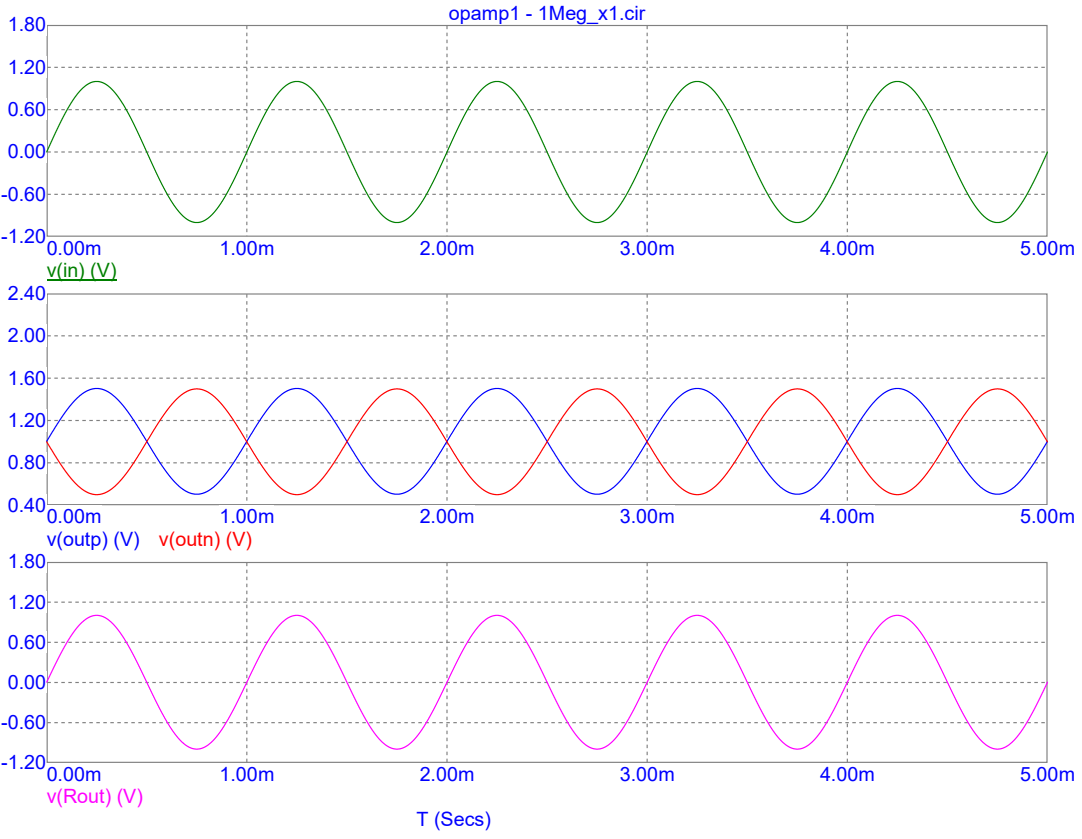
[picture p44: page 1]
v(outp) (V) v(outn) (V); v(Rout) (V); T (Secs); opamp1 - 1Meg_x1.cir

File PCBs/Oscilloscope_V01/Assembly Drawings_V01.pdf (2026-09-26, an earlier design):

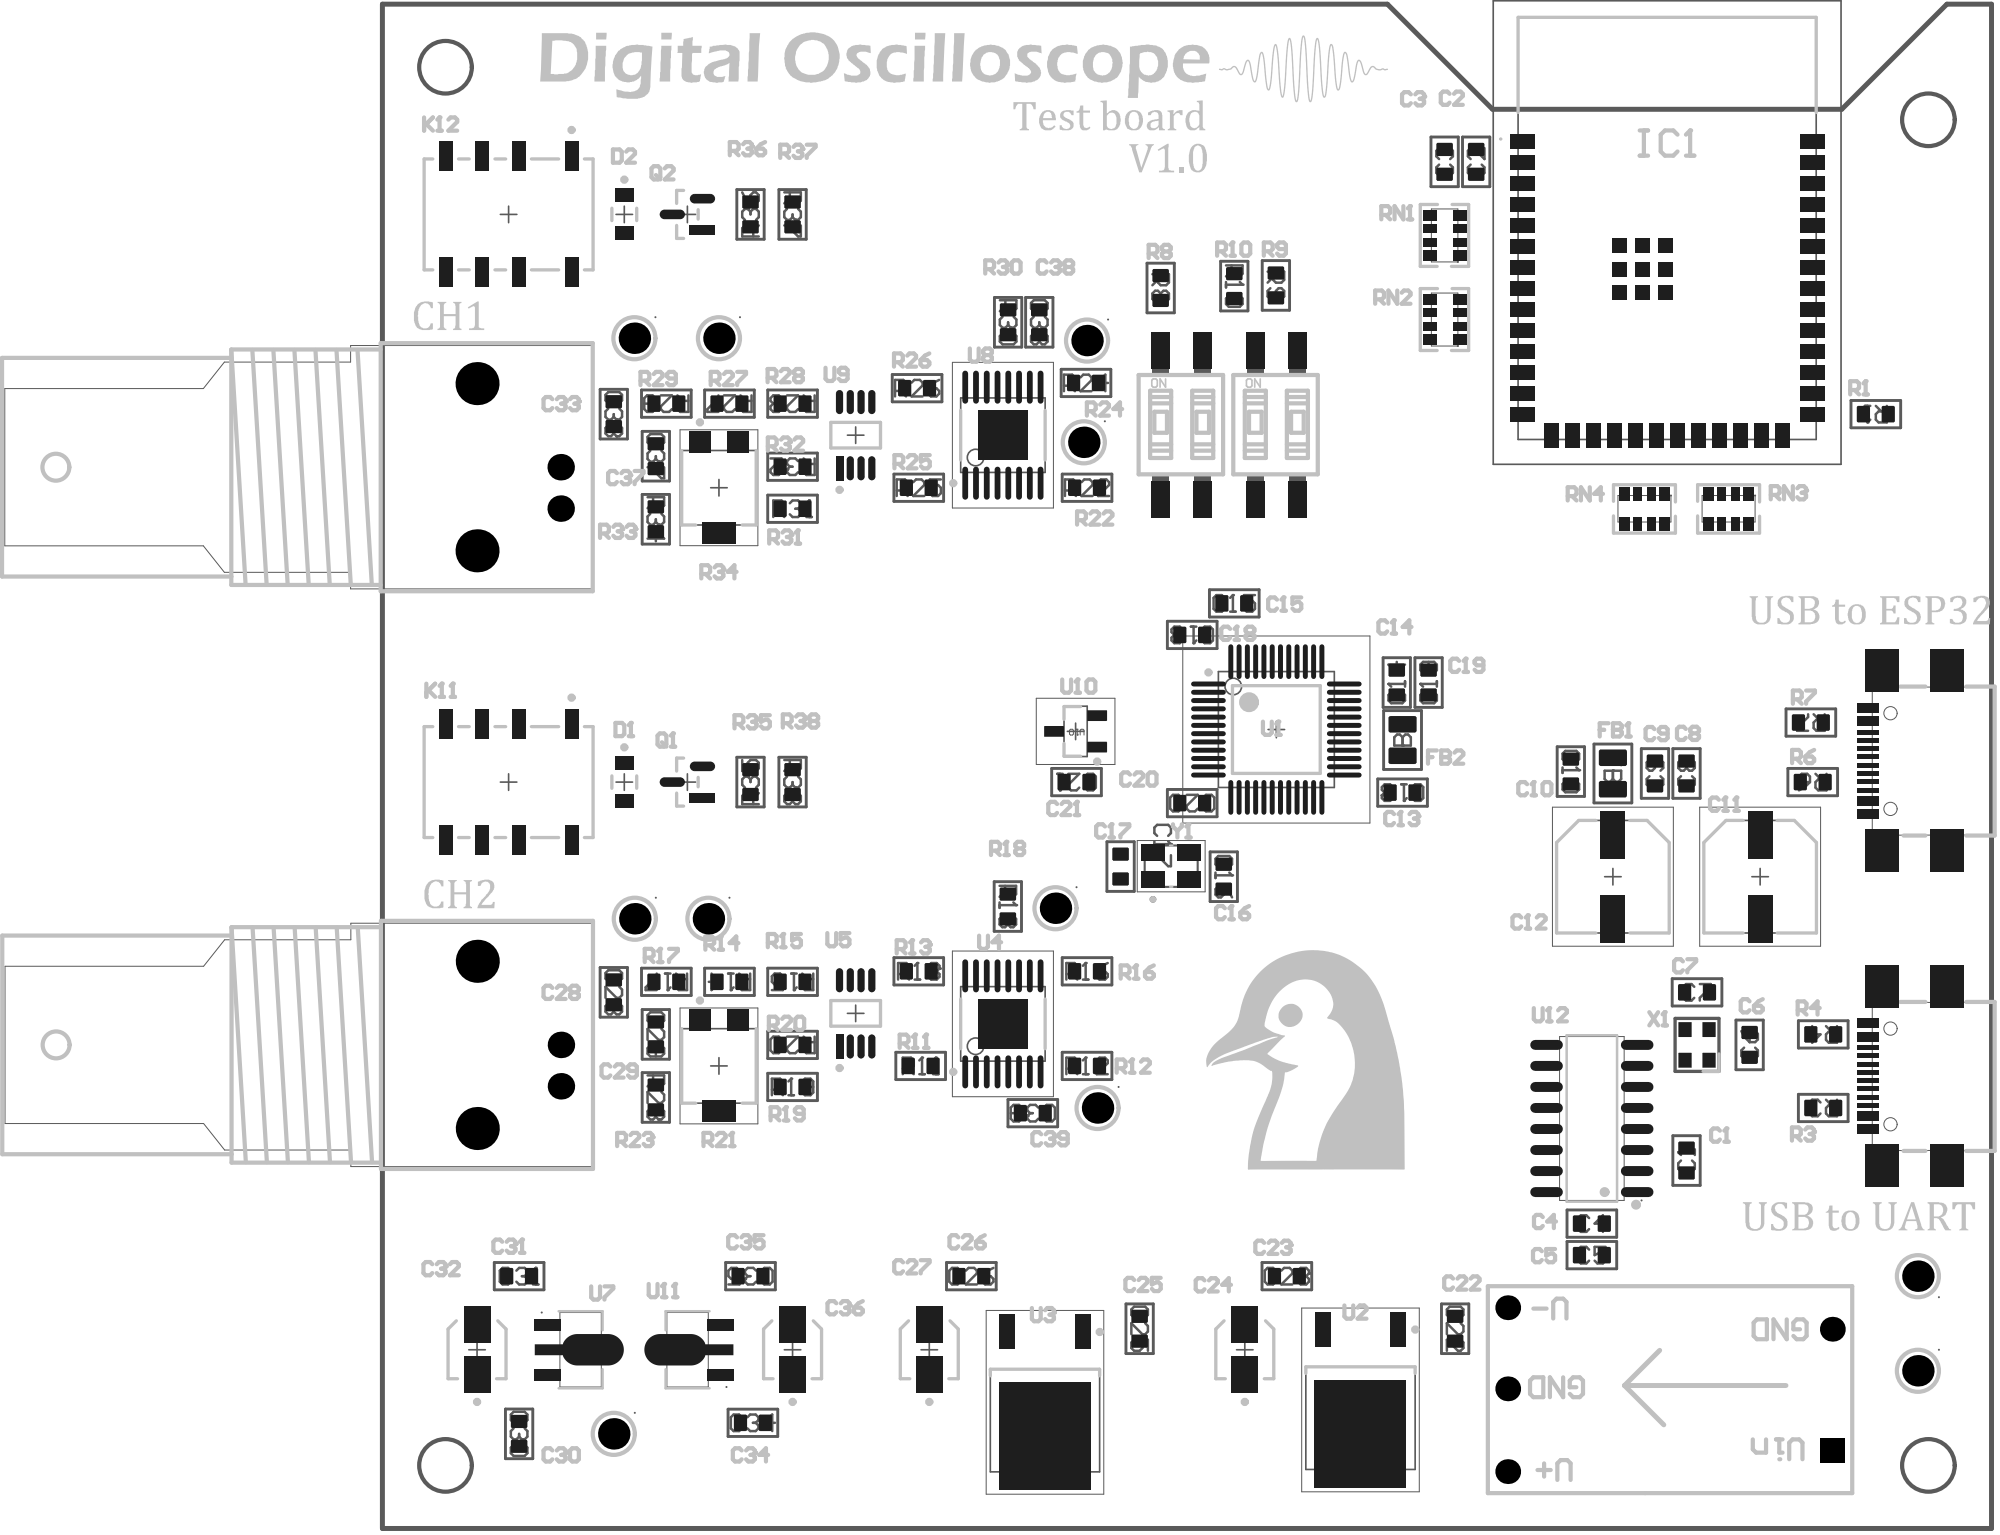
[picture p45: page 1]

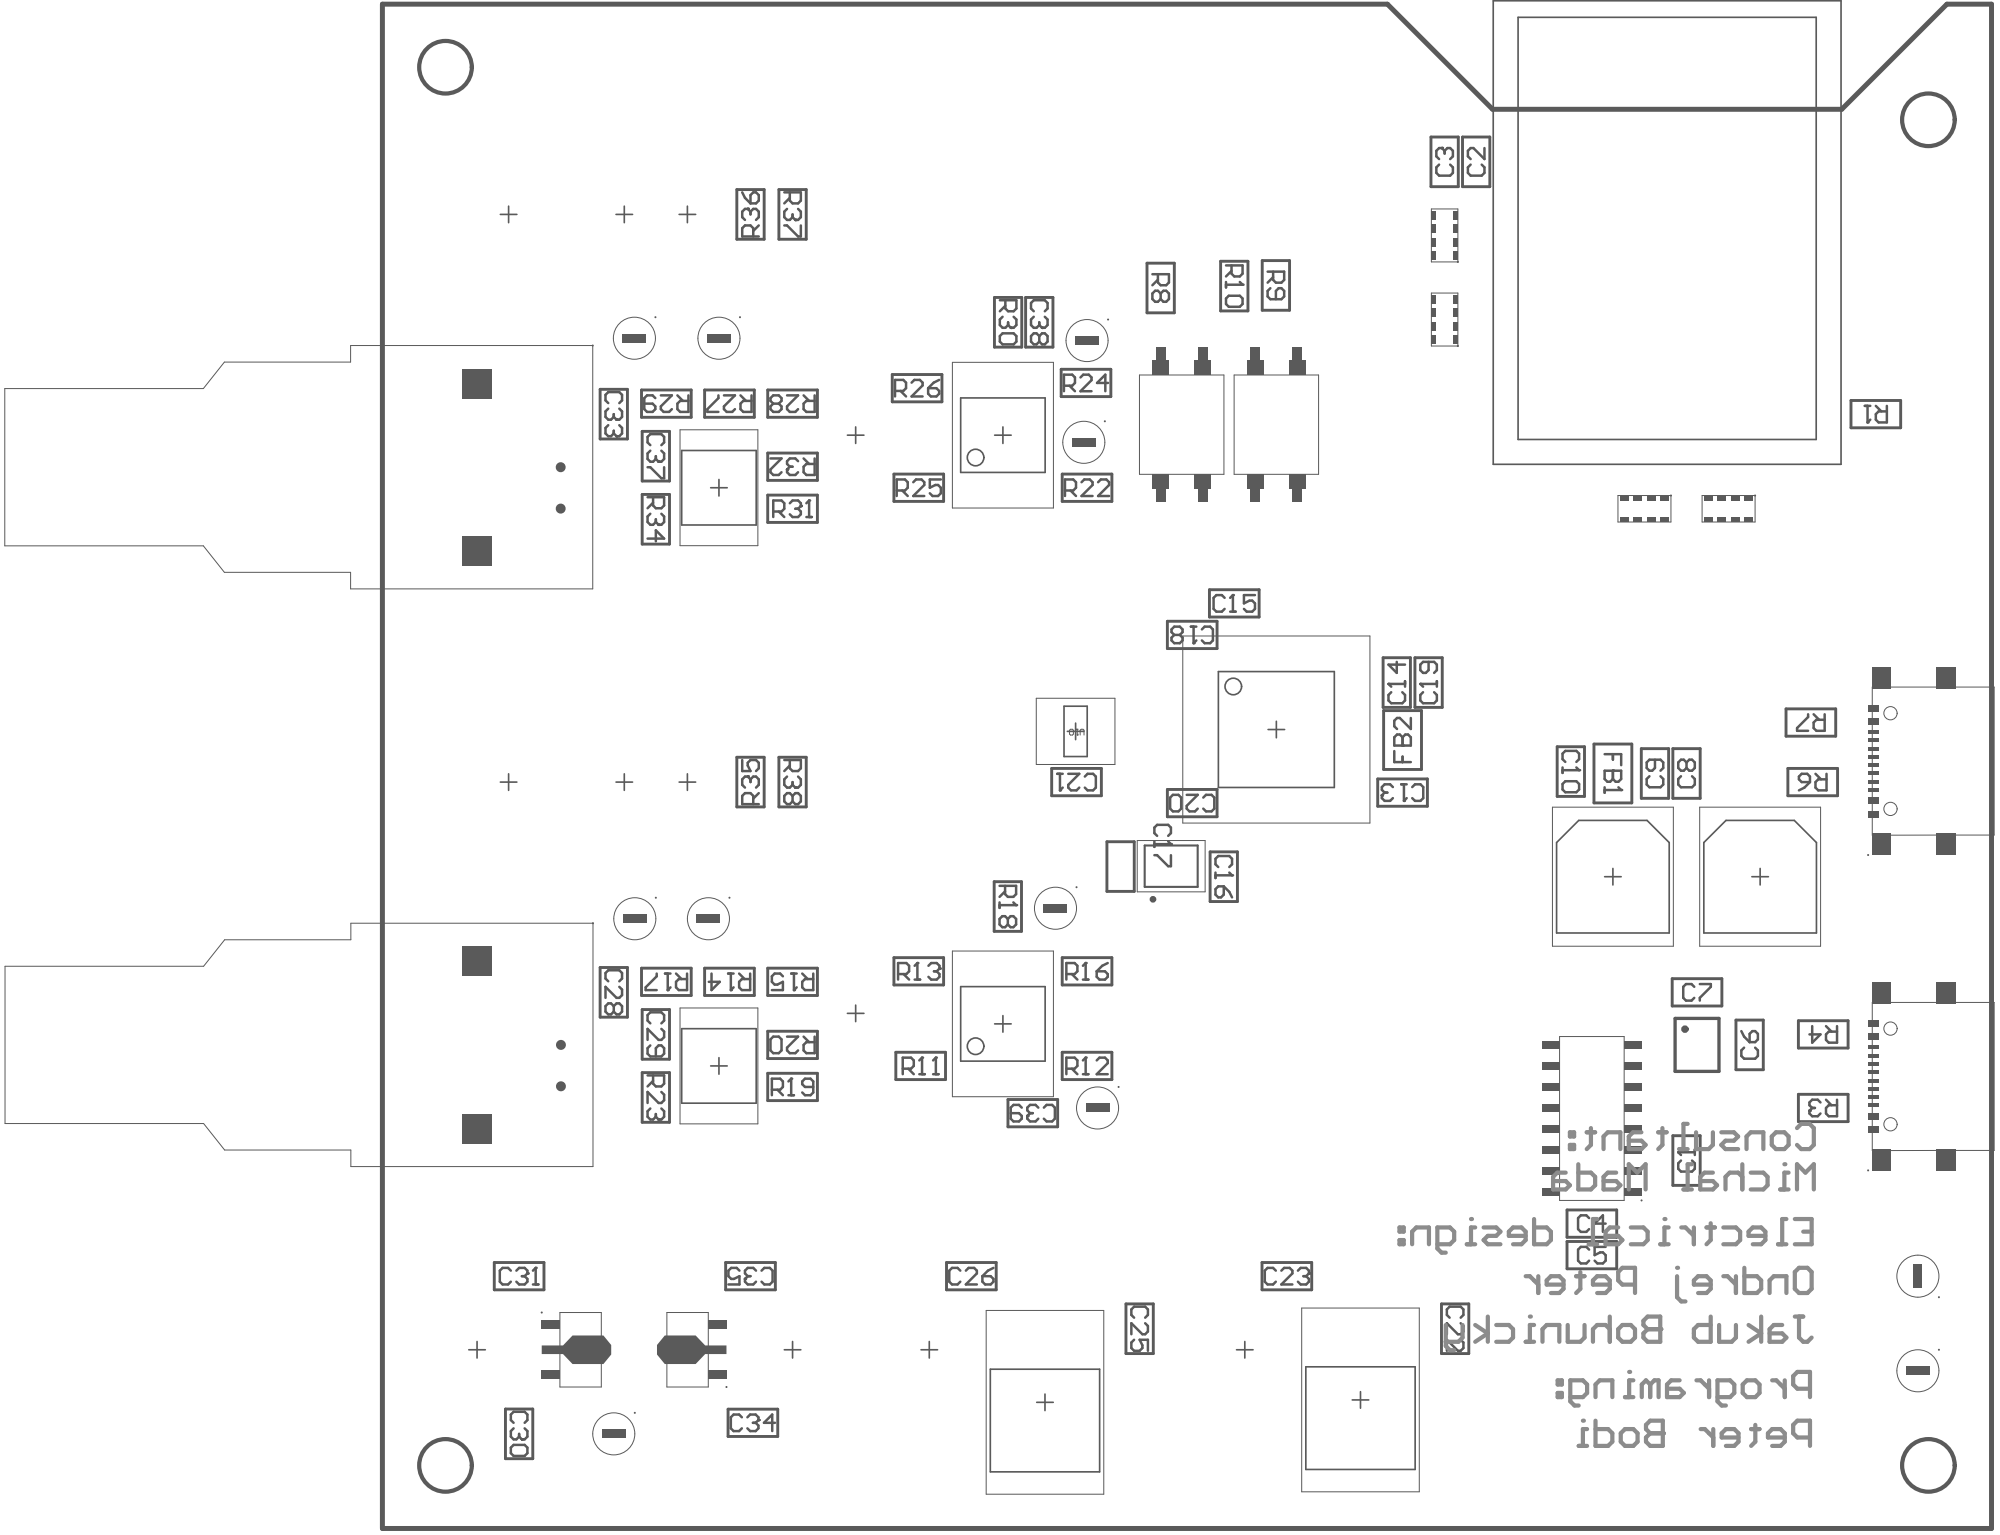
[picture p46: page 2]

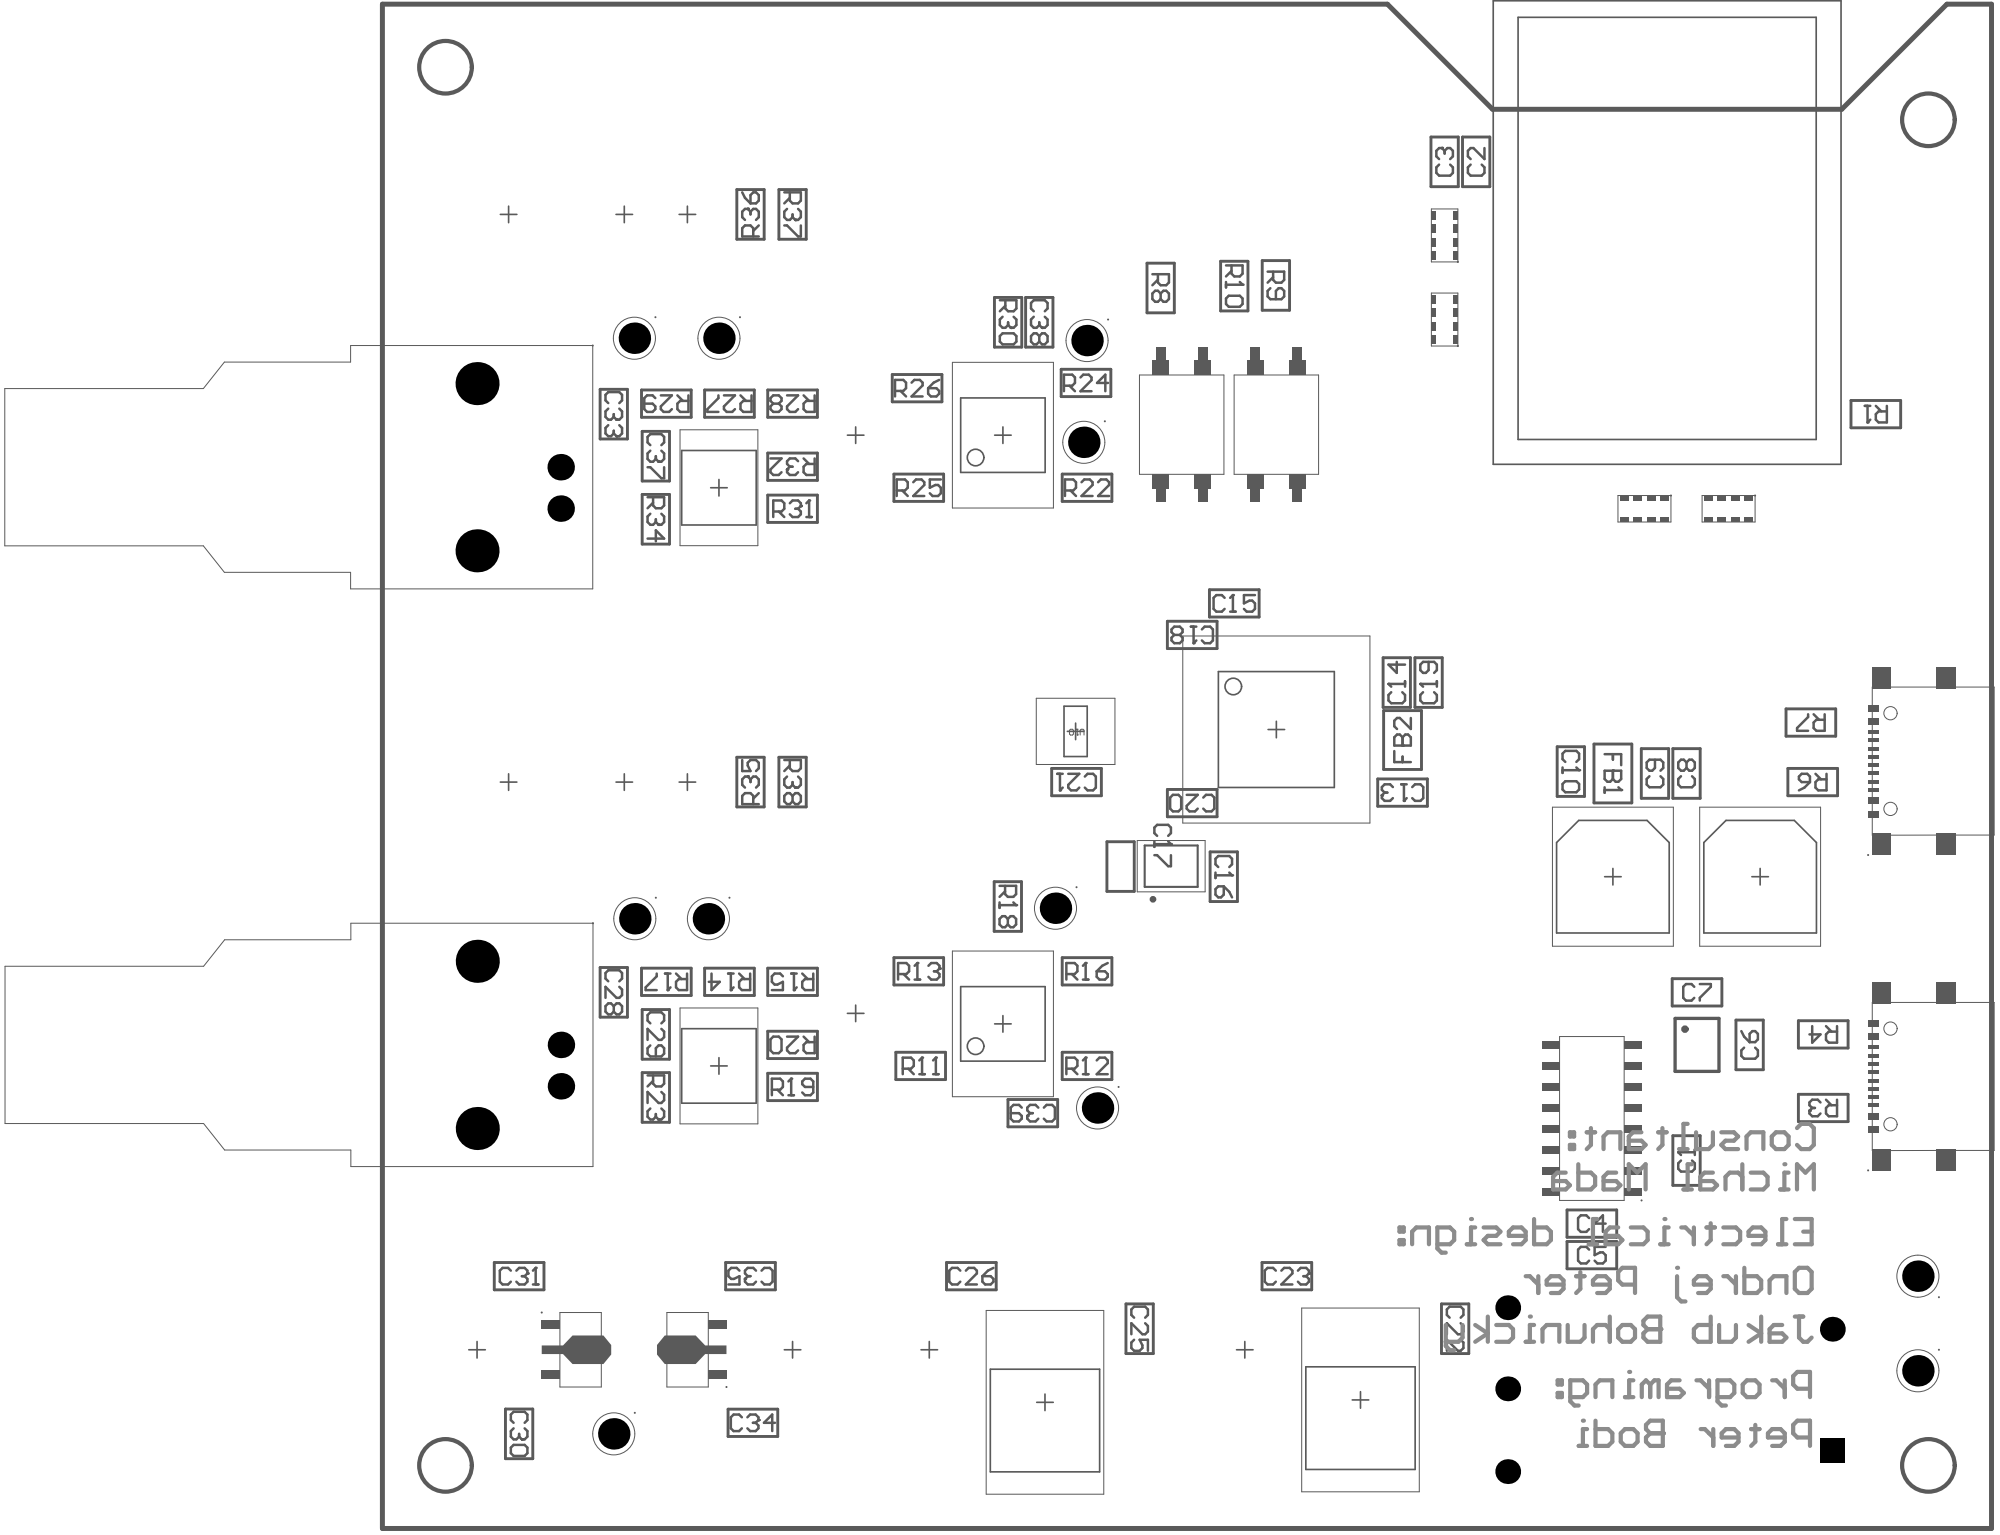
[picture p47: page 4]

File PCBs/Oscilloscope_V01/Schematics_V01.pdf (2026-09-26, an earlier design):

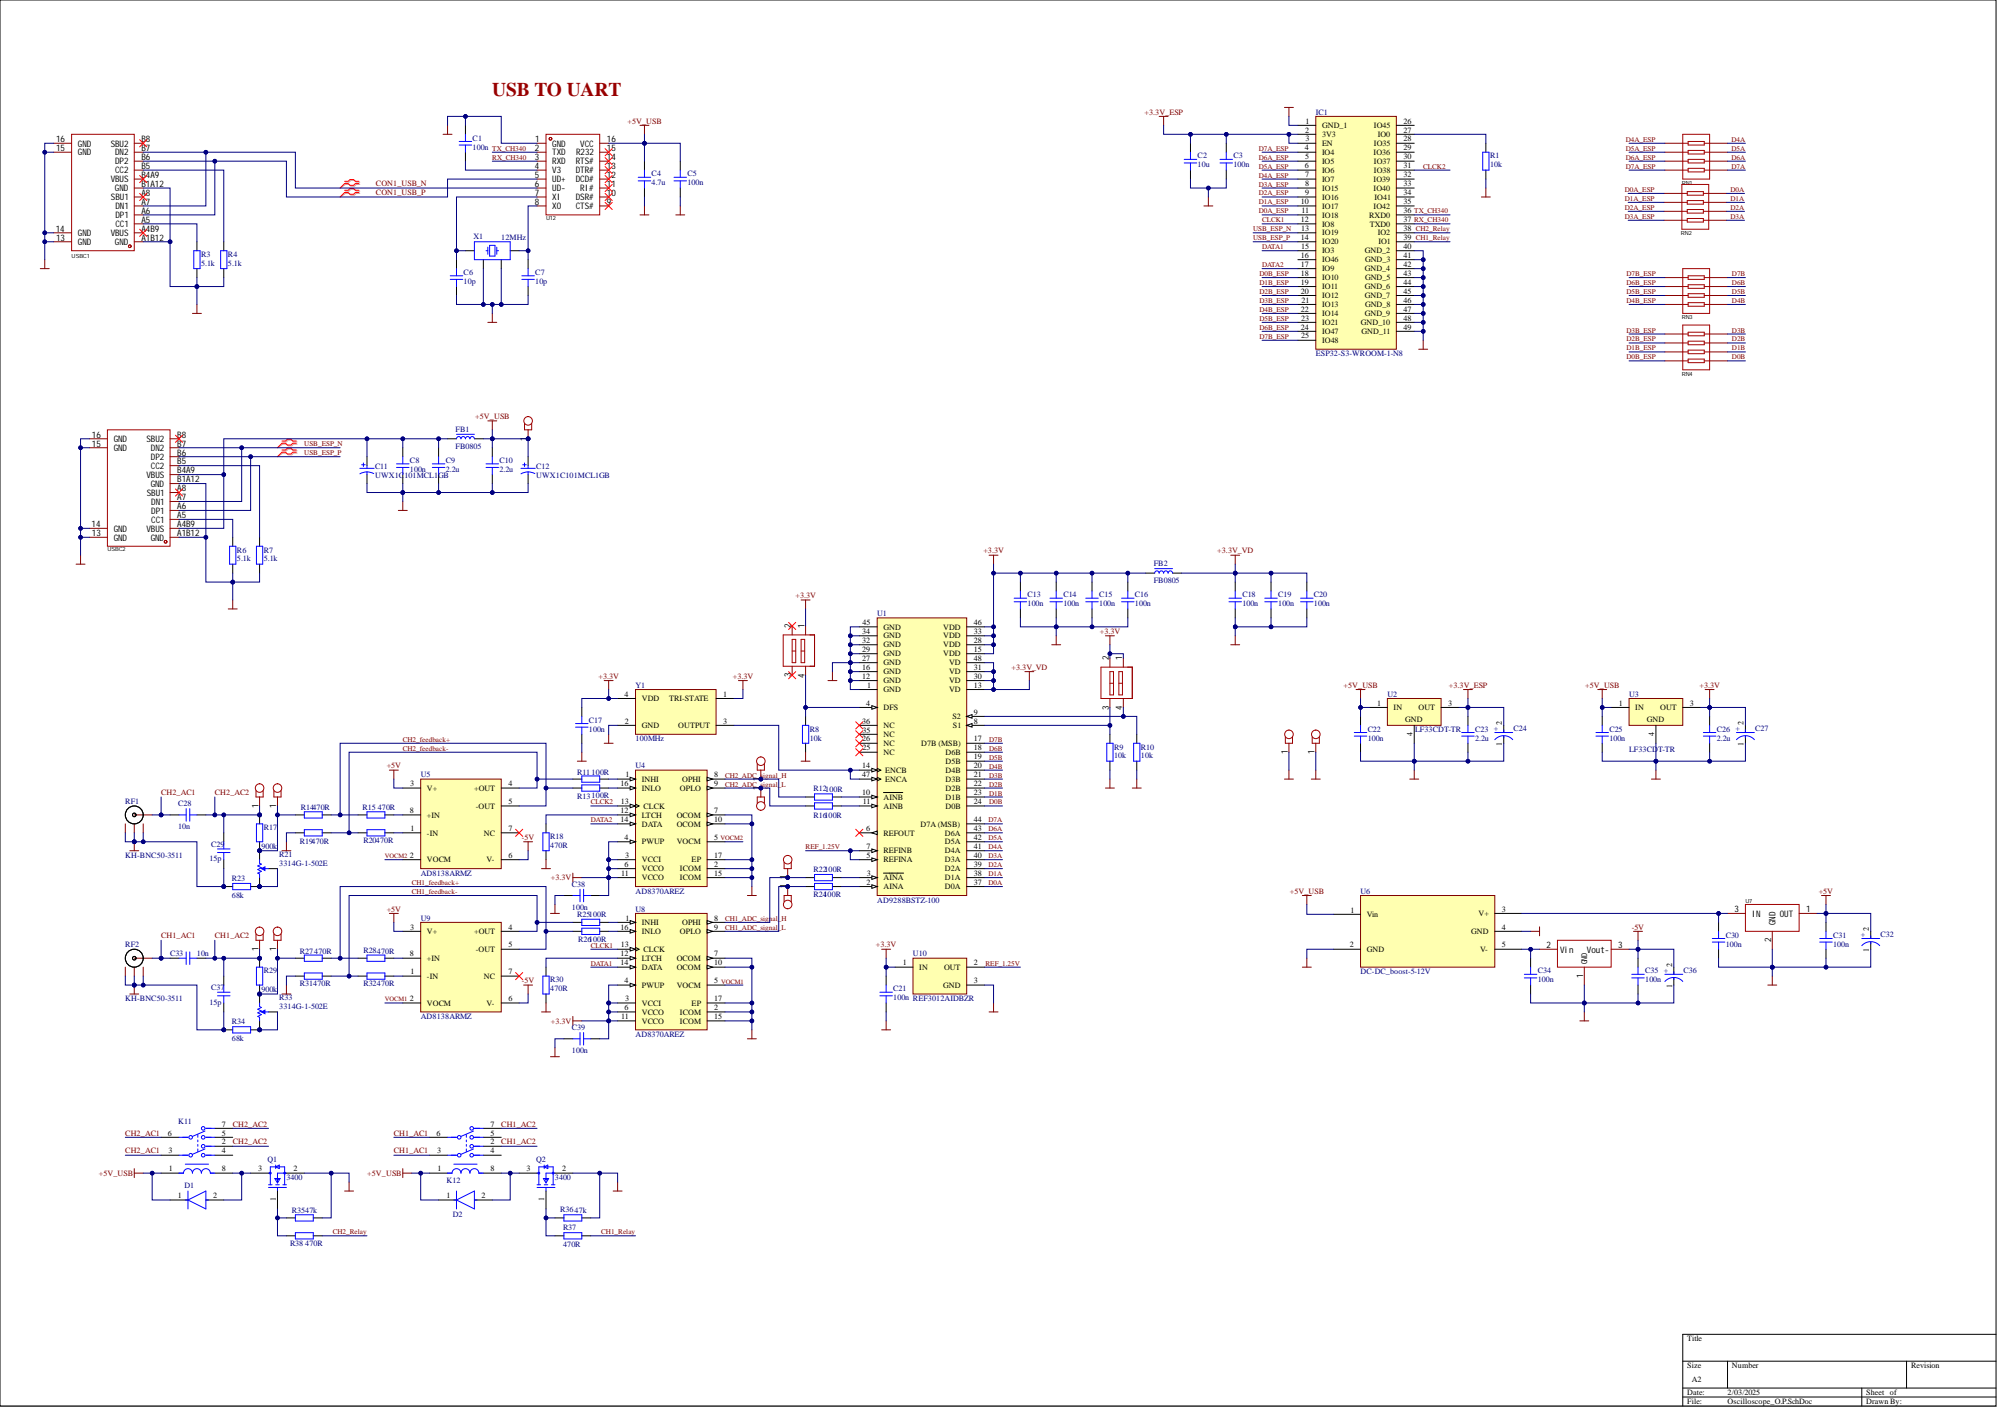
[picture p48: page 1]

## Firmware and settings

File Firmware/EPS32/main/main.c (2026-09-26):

#include "arch/sys_arch.h"
#include <stdint.h >
#include <stdio.h>
#include <stdbool.h>
#include <sys/types.h>
#include <unistd.h >
#include "driver/dedic_gpio.h"
#include "driver/gpio.h"
#include "driver/uart.h"
#include "hal/gpio_types.h"
#include "rom/ets_sys.h"
#include "soc/gpio_num.h"
#include "soc/gpio_periph.h"
#include "soc/gpio_struct.h"
#include "soc/gpio_reg.h"
#include "hal/dedic_gpio_cpu_ll.h"
#include "soc/io_mux_reg.h"
#include "soc/soc.h"
#include "esp_private/io_mux.h"
#include "freertos/FreeRTOS.h"
#include "freertos/task.h"
#include <string.h>
#include <stdlib.h>
#include "esp_log.h"
#include "esp_system.h"

#define UART_NUM UART_NUM_0             // Use UART0 (connected to USB)
#define BUF_SIZE (300)                 // Buffer size for UART data
#define RD_BUF_SIZE (BUF_SIZE)          // Read buffer size
//static const char *TAG = "UART_READ";

void nastavenie_zosilnovaca1(int u_rozsah){
					
			//KOMUNIKACIA S ADprevodnikom
			//kanal 1- LTCH - 40 CLK - 8, DATA - 3 (v pripade zmeny, zmneit aj v configu v Maine)
			//kanal 2- LTCH - 39 CLK - 38, DATA - 9 
			//pridat comboBox do aplikacie
			
			//rele 1 - pin 1, rele2 - pin 2 (len checkBoxy)
				//x10 rele1 - 40, rele2 - 41
			gpio_set_level(40, 0);
			ets_delay_us(1);

			if((0b10000000 & u_rozsah) == 0b10000000) gpio_set_level(3, 1);
			else  gpio_set_level(3, 0);
			ets_delay_us(1); gpio_set_level(8, 1);		
			ets_delay_us(1); gpio_set_level(8, 0);
			
			if((0b01000000 & u_rozsah) == 0b01000000) gpio_set_level(3, 1);
			else  gpio_set_level(3, 0);
			ets_delay_us(1); gpio_set_level(8, 1);		
			ets_delay_us(1); gpio_set_level(8, 0);
			
			if((0b00100000 & u_rozsah) == 0b00100000) gpio_set_level(3, 1);
			else  gpio_set_level(3, 0);
			ets_delay_us(1); gpio_set_level(8, 1);		
			ets_delay_us(1); gpio_set_level(8, 0);
			
			if((0b00010000 & u_rozsah) == 0b00010000) gpio_set_level(3, 1);
			else  gpio_set_level(3, 0);
			ets_delay_us(1); gpio_set_level(8, 1);		
			ets_delay_us(1); gpio_set_level(8, 0);
			
			if((0b00001000 & u_rozsah) == 0b00001000) gpio_set_level(3, 1);
			else  gpio_set_level(3, 0);
			ets_delay_us(1); gpio_set_level(8, 1);		
			ets_delay_us(1); gpio_set_level(8, 0);
			
			if((0b00000100 & u_rozsah) == 0b00000100) gpio_set_level(3, 1);
			else  gpio_set_level(3, 0);
			ets_delay_us(1); gpio_set_level(8, 1);		
			ets_delay_us(1); gpio_set_level(8, 0);
			
			if((0b00000010 & u_rozsah) == 0b00000010) gpio_set_level(3, 1);
			else  gpio_set_level(3, 0);
			ets_delay_us(1); gpio_set_level(8, 1);		
			ets_delay_us(1); gpio_set_level(8, 0);
			
			if((0b00000001 & u_rozsah) == 0b00000001) gpio_set_level(3, 1);
			else  gpio_set_level(3, 0);
			ets_delay_us(1); gpio_set_level(8, 1);		
			ets_delay_us(1); gpio_set_level(8, 0);

	  		gpio_set_level(40, 1);

	  		sys_delay_ms(10);
}

void nastavenie_zosilnovaca2(int u_rozsah){
					
			//KOMUNIKACIA S ADprevodnikom
			//kanal 1- LTCH - 40 CLK - 8, DATA - 3 (v pripade zmeny, zmneit aj v configu v Maine)
			//kanal 2- LTCH - 39 CLK - 38, DATA - 9 
			//pridat comboBox do aplikacie
			
			//rele 1 - pin 1, rele2 - pin 2 (len checkBoxy)
				//x10 rele1 - 42, rele2 - 41
			gpio_set_level(39, 0);
			ets_delay_us(1);

			if((0b10000000 & u_rozsah) == 0b10000000) gpio_set_level(9, 1);
			else  gpio_set_level(9, 0);
			ets_delay_us(1); gpio_set_level(38, 1);		
			ets_delay_us(1); gpio_set_level(38, 0);
			
			if((0b01000000 & u_rozsah) == 0b01000000) gpio_set_level(9, 1);
			else  gpio_set_level(9, 0);
			ets_delay_us(1); gpio_set_level(38, 1);		
			ets_delay_us(1); gpio_set_level(38, 0);
			
			if((0b00100000 & u_rozsah) == 0b00100000) gpio_set_level(9, 1);
			else  gpio_set_level(9, 0);
			ets_delay_us(1); gpio_set_level(38, 1);		
			ets_delay_us(1); gpio_set_level(38, 0);
			
			if((0b00010000 & u_rozsah) == 0b00010000) gpio_set_level(9, 1);
			else  gpio_set_level(9, 0);
			ets_delay_us(1); gpio_set_level(38, 1);		
			ets_delay_us(1); gpio_set_level(38, 0);
			
			if((0b00001000 & u_rozsah) == 0b00001000) gpio_set_level(9, 1);
			else  gpio_set_level(9, 0);
			ets_delay_us(1); gpio_set_level(38, 1);		
			ets_delay_us(1); gpio_set_level(38, 0);
			
			if((0b00000100 & u_rozsah) == 0b00000100) gpio_set_level(9, 1);
			else  gpio_set_level(9, 0);
			ets_delay_us(1); gpio_set_level(38, 1);		
			ets_delay_us(1); gpio_set_level(38, 0);
			
			if((0b00000010 & u_rozsah) == 0b00000010) gpio_set_level(9, 1);
			else  gpio_set_level(9, 0);
			ets_delay_us(1); gpio_set_level(38, 1);		
			ets_delay_us(1); gpio_set_level(38, 0);
			
			if((0b00000001 & u_rozsah) == 0b00000001) gpio_set_level(9, 1);
			else  gpio_set_level(9, 0);
			ets_delay_us(1); gpio_set_level(38, 1);		
			ets_delay_us(1); gpio_set_level(38, 0);

	  		gpio_set_level(39, 1);
	  		sys_delay_ms(10);
}

volatile int d;
int t_rozsah, numbeer;
volatile bool dual_kanal = false, spustit2 = false;
int nap_rozsah = -100;

void dedic_task(void *p)
{
	uint32_t pole1[500];
	d=1;
	int nap_rozsah1 = -100, nap_rozsah2 = -100;
	
	
	
	while(1)
	{
			
		while(d!=1){}
		//gpio_dump_io_configuration(stdout,(1ULL << GPIO_NUM_1) |(1ULL << GPIO_NUM_2) | (1ULL << GPIO_NUM_3) | (1ULL << GPIO_NUM_8) | (1ULL << GPIO_NUM_9) | (1ULL << GPIO_NUM_38) | (1ULL << GPIO_NUM_39) | (1ULL << GPIO_NUM_40)| (1ULL << GPIO_NUM_41)| (1ULL << GPIO_NUM_42) | (1ULL << GPIO_NUM_18) | (1ULL << GPIO_NUM_17) | (1ULL << GPIO_NUM_16) | (1ULL << GPIO_NUM_15) | (1ULL << GPIO_NUM_7) | (1ULL << GPIO_NUM_6) | (1ULL << GPIO_NUM_5) | (1ULL << GPIO_NUM_4) | (1ULL << GPIO_NUM_10) | (1ULL << GPIO_NUM_11) | (1ULL << GPIO_NUM_12) | (1ULL << GPIO_NUM_13) | (1ULL << GPIO_NUM_14) | (1ULL << GPIO_NUM_21) | (1ULL << GPIO_NUM_47) | (1ULL << GPIO_NUM_48));

	

			uint8_t *data = (uint8_t *) malloc(RD_BUF_SIZE);
			
	            while(!uart_read_bytes(UART_NUM, data, RD_BUF_SIZE, pdMS_TO_TICKS(1))){ }
	            char *placeholder = (char *)data;
	            char *token = strtok(placeholder, " "); // Split using space as delimiter
	
		    	for (int f=0; f<8; f++) 
		    	{
					switch (f) 
					{
					case 0:	numbeer = atoi(token) ; if (numbeer != nap_rozsah1) {nastavenie_zosilnovaca1(numbeer);} nap_rozsah1 = numbeer; break;																								
					case 1:	numbeer = atoi(token) ; if (numbeer != nap_rozsah2) {nastavenie_zosilnovaca2(numbeer);} nap_rozsah = numbeer; break;																								
					case 2:	t_rozsah = atoi(token) ; break;
					case 3:	if(atoi(token)==0) {dual_kanal = false;} else {dual_kanal = true;} break;
					case 4:	if(atoi(token)==0) {gpio_set_level(1, 0);} else {gpio_set_level(1, 1);} break;
					case 5:	if(atoi(token)==0) {gpio_set_level(2, 0);} else {gpio_set_level(2, 1);} break;
					case 6:	if(atoi(token)==0) {gpio_set_level(42, 0);} else {gpio_set_level(42, 1);} break;
					case 7:	if(atoi(token)==0) {gpio_set_level(41, 0);} else {gpio_set_level(41, 1);} break;				
					}
		        	token = strtok(NULL, " "); // Get next token
        		}
       
	         //sys_delay_ms(10);
			spustit2 = true;
	  		//CITANIE
	  		
	  		while(!spustit2) {};
	  		
	  		if (t_rozsah == 0) 
	  		{
			asm volatile( "EE.GET_GPIO_IN %[r]" : [r] "=r" (pole1[0]));
			asm volatile( "EE.GET_GPIO_IN %[r]" : [r] "=r" (pole1[1]));
			asm volatile( "EE.GET_GPIO_IN %[r]" : [r] "=r" (pole1[2]));
			asm volatile( "EE.GET_GPIO_IN %[r]" : [r] "=r" (pole1[3]));
			asm volatile( "EE.GET_GPIO_IN %[r]" : [r] "=r" (pole1[4]));
			asm volatile( "EE.GET_GPIO_IN %[r]" : [r] "=r" (pole1[5]));
			asm volatile( "EE.GET_GPIO_IN %[r]" : [r] "=r" (pole1[6]));
			asm volatile( "EE.GET_GPIO_IN %[r]" : [r] "=r" (pole1[7]));
			asm volatile( "EE.GET_GPIO_IN %[r]" : [r] "=r" (pole1[8]));
			asm volatile( "EE.GET_GPIO_IN %[r]" : [r] "=r" (pole1[9]));
			asm volatile( "EE.GET_GPIO_IN %[r]" : [r] "=r" (pole1[10]));
			asm volatile( "EE.GET_GPIO_IN %[r]" : [r] "=r" (pole1[11]));
			asm volatile( "EE.GET_GPIO_IN %[r]" : [r] "=r" (pole1[12]));
			asm volatile( "EE.GET_GPIO_IN %[r]" : [r] "=r" (pole1[13]));
			asm volatile( "EE.GET_GPIO_IN %[r]" : [r] "=r" (pole1[14]));
			asm volatile( "EE.GET_GPIO_IN %[r]" : [r] "=r" (pole1[15]));
			asm volatile( "EE.GET_GPIO_IN %[r]" : [r] "=r" (pole1[16]));
			asm volatile( "EE.GET_GPIO_IN %[r]" : [r] "=r" (pole1[17]));
			asm volatile( "EE.GET_GPIO_IN %[r]" : [r] "=r" (pole1[18]));
			asm volatile( "EE.GET_GPIO_IN %[r]" : [r] "=r" (pole1[19]));
			asm volatile( "EE.GET_GPIO_IN %[r]" : [r] "=r" (pole1[20]));
			asm volatile( "EE.GET_GPIO_IN %[r]" : [r] "=r" (pole1[21]));
			asm volatile( "EE.GET_GPIO_IN %[r]" : [r] "=r" (pole1[22]));
			asm volatile( "EE.GET_GPIO_IN %[r]" : [r] "=r" (pole1[23]));
			asm volatile( "EE.GET_GPIO_IN %[r]" : [r] "=r" (pole1[24]));
			asm volatile( "EE.GET_GPIO_IN %[r]" : [r] "=r" (pole1[25]));
			asm volatile( "EE.GET_GPIO_IN %[r]" : [r] "=r" (pole1[26]));
			asm volatile( "EE.GET_GPIO_IN %[r]" : [r] "=r" (pole1[27]));
			asm volatile( "EE.GET_GPIO_IN %[r]" : [r] "=r" (pole1[28]));
			asm volatile( "EE.GET_GPIO_IN %[r]" : [r] "=r" (pole1[29]));
			asm volatile( "EE.GET_GPIO_IN %[r]" : [r] "=r" (pole1[30]));
			asm volatile( "EE.GET_GPIO_IN %[r]" : [r] "=r" (pole1[31]));
			asm volatile( "EE.GET_GPIO_IN %[r]" : [r] "=r" (pole1[32]));
			asm volatile( "EE.GET_GPIO_IN %[r]" : [r] "=r" (pole1[33]));
			asm volatile( "EE.GET_GPIO_IN %[r]" : [r] "=r" (pole1[34]));
			asm volatile( "EE.GET_GPIO_IN %[r]" : [r] "=r" (pole1[35]));
			asm volatile( "EE.GET_GPIO_IN %[r]" : [r] "=r" (pole1[36]));
			asm volatile( "EE.GET_GPIO_IN %[r]" : [r] "=r" (pole1[37]));
			asm volatile( "EE.GET_GPIO_IN %[r]" : [r] "=r" (pole1[38]));
			asm volatile( "EE.GET_GPIO_IN %[r]" : [r] "=r" (pole1[39]));
			asm volatile( "EE.GET_GPIO_IN %[r]" : [r] "=r" (pole1[40]));
			asm volatile( "EE.GET_GPIO_IN %[r]" : [r] "=r" (pole1[41]));
			asm volatile( "EE.GET_GPIO_IN %[r]" : [r] "=r" (pole1[42]));
			asm volatile( "EE.GET_GPIO_IN %[r]" : [r] "=r" (pole1[43]));
			asm volatile( "EE.GET_GPIO_IN %[r]" : [r] "=r" (pole1[44]));
			asm volatile( "EE.GET_GPIO_IN %[r]" : [r] "=r" (pole1[45]));
			asm volatile( "EE.GET_GPIO_IN %[r]" : [r] "=r" (pole1[46]));
			asm volatile( "EE.GET_GPIO_IN %[r]" : [r] "=r" (pole1[47]));
			asm volatile( "EE.GET_GPIO_IN %[r]" : [r] "=r" (pole1[48]));
			asm volatile( "EE.GET_GPIO_IN %[r]" : [r] "=r" (pole1[49]));
			asm volatile( "EE.GET_GPIO_IN %[r]" : [r] "=r" (pole1[50]));
			asm volatile( "EE.GET_GPIO_IN %[r]" : [r] "=r" (pole1[51]));
			asm volatile( "EE.GET_GPIO_IN %[r]" : [r] "=r" (pole1[52]));
			asm volatile( "EE.GET_GPIO_IN %[r]" : [r] "=r" (pole1[53]));
			asm volatile( "EE.GET_GPIO_IN %[r]" : [r] "=r" (pole1[54]));
			asm volatile( "EE.GET_GPIO_IN %[r]" : [r] "=r" (pole1[55]));
			asm volatile( "EE.GET_GPIO_IN %[r]" : [r] "=r" (pole1[56]));
			asm volatile( "EE.GET_GPIO_IN %[r]" : [r] "=r" (pole1[57]));
			asm volatile( "EE.GET_GPIO_IN %[r]" : [r] "=r" (pole1[58]));
			asm volatile( "EE.GET_GPIO_IN %[r]" : [r] "=r" (pole1[59]));
			asm volatile( "EE.GET_GPIO_IN %[r]" : [r] "=r" (pole1[60]));
			asm volatile( "EE.GET_GPIO_IN %[r]" : [r] "=r" (pole1[61]));
			asm volatile( "EE.GET_GPIO_IN %[r]" : [r] "=r" (pole1[62]));
			asm volatile( "EE.GET_GPIO_IN %[r]" : [r] "=r" (pole1[63]));
			asm volatile( "EE.GET_GPIO_IN %[r]" : [r] "=r" (pole1[64]));
			asm volatile( "EE.GET_GPIO_IN %[r]" : [r] "=r" (pole1[65]));
			asm volatile( "EE.GET_GPIO_IN %[r]" : [r] "=r" (pole1[66]));
			asm volatile( "EE.GET_GPIO_IN %[r]" : [r] "=r" (pole1[67]));
			asm volatile( "EE.GET_GPIO_IN %[r]" : [r] "=r" (pole1[68]));
			asm volatile( "EE.GET_GPIO_IN %[r]" : [r] "=r" (pole1[69]));
			asm volatile( "EE.GET_GPIO_IN %[r]" : [r] "=r"(pole1[70]));
			asm volatile( "EE.GET_GPIO_IN %[r]" : [r] "=r"(pole1[71]));
			asm volatile( "EE.GET_GPIO_IN %[r]" : [r] "=r"(pole1[72]));
			asm volatile( "EE.GET_GPIO_IN %[r]" : [r] "=r"(pole1[73]));
			asm volatile( "EE.GET_GPIO_IN %[r]" : [r] "=r"(pole1[74]));
			asm volatile( "EE.GET_GPIO_IN %[r]" : [r] "=r"(pole1[75]));
			asm volatile( "EE.GET_GPIO_IN %[r]" : [r] "=r"(pole1[76]));
			asm volatile( "EE.GET_GPIO_IN %[r]" : [r] "=r"(pole1[77]));
			asm volatile( "EE.GET_GPIO_IN %[r]" : [r] "=r"(pole1[78]));
			asm volatile( "EE.GET_GPIO_IN %[r]" : [r] "=r"(pole1[79]));
			asm volatile( "EE.GET_GPIO_IN %[r]" : [r] "=r"(pole1[80]));
			asm volatile( "EE.GET_GPIO_IN %[r]" : [r] "=r"(pole1[81]));
			asm volatile( "EE.GET_GPIO_IN %[r]" : [r] "=r"(pole1[82]));
			asm volatile( "EE.GET_GPIO_IN %[r]" : [r] "=r"(pole1[83]));
			asm volatile( "EE.GET_GPIO_IN %[r]" : [r] "=r"(pole1[84]));
			asm volatile( "EE.GET_GPIO_IN %[r]" : [r] "=r"(pole1[85]));
			asm volatile( "EE.GET_GPIO_IN %[r]" : [r] "=r"(pole1[86]));
			asm volatile( "EE.GET_GPIO_IN %[r]" : [r] "=r"(pole1[87]));
			asm volatile( "EE.GET_GPIO_IN %[r]" : [r] "=r"(pole1[88]));
			asm volatile( "EE.GET_GPIO_IN %[r]" : [r] "=r"(pole1[89]));
			asm volatile( "EE.GET_GPIO_IN %[r]" : [r] "=r"(pole1[90]));
			asm volatile( "EE.GET_GPIO_IN %[r]" : [r] "=r"(pole1[91]));
			asm volatile( "EE.GET_GPIO_IN %[r]" : [r] "=r"(pole1[92]));
			asm volatile( "EE.GET_GPIO_IN %[r]" : [r] "=r"(pole1[93]));
			asm volatile( "EE.GET_GPIO_IN %[r]" : [r] "=r"(pole1[94]));
			asm volatile( "EE.GET_GPIO_IN %[r]" : [r] "=r"(pole1[95]));
			asm volatile( "EE.GET_GPIO_IN %[r]" : [r] "=r"(pole1[96]));
			asm volatile( "EE.GET_GPIO_IN %[r]" : [r] "=r"(pole1[97]));
			asm volatile( "EE.GET_GPIO_IN %[r]" : [r] "=r"(pole1[98]));
			asm volatile( "EE.GET_GPIO_IN %[r]" : [r] "=r"(pole1[99]));
			asm volatile( "EE.GET_GPIO_IN %[r]" : [r] "=r"(pole1[100]));
			asm volatile( "EE.GET_GPIO_IN %[r]" : [r] "=r"(pole1[101]));
			asm volatile( "EE.GET_GPIO_IN %[r]" : [r] "=r"(pole1[102]));
			asm volatile( "EE.GET_GPIO_IN %[r]" : [r] "=r"(pole1[103]));
			asm volatile( "EE.GET_GPIO_IN %[r]" : [r] "=r"(pole1[104]));
			asm volatile( "EE.GET_GPIO_IN %[r]" : [r] "=r"(pole1[105]));
			asm volatile( "EE.GET_GPIO_IN %[r]" : [r] "=r"(pole1[106]));
			asm volatile( "EE.GET_GPIO_IN %[r]" : [r] "=r"(pole1[107]));
			asm volatile( "EE.GET_GPIO_IN %[r]" : [r] "=r"(pole1[108]));
			asm volatile( "EE.GET_GPIO_IN %[r]" : [r] "=r"(pole1[109]));
			asm volatile( "EE.GET_GPIO_IN %[r]" : [r] "=r"(pole1[110]));
			asm volatile( "EE.GET_GPIO_IN %[r]" : [r] "=r"(pole1[111]));
			asm volatile( "EE.GET_GPIO_IN %[r]" : [r] "=r"(pole1[112]));
			asm volatile( "EE.GET_GPIO_IN %[r]" : [r] "=r"(pole1[113]));
			asm volatile( "EE.GET_GPIO_IN %[r]" : [r] "=r"(pole1[114]));
			asm volatile( "EE.GET_GPIO_IN %[r]" : [r] "=r"(pole1[115]));
			asm volatile( "EE.GET_GPIO_IN %[r]" : [r] "=r"(pole1[116]));
			asm volatile( "EE.GET_GPIO_IN %[r]" : [r] "=r"(pole1[117]));
			asm volatile( "EE.GET_GPIO_IN %[r]" : [r] "=r"(pole1[118]));
			asm volatile( "EE.GET_GPIO_IN %[r]" : [r] "=r"(pole1[119]));
			asm volatile( "EE.GET_GPIO_IN %[r]" : [r] "=r"(pole1[120]));
			asm volatile( "EE.GET_GPIO_IN %[r]" : [r] "=r"(pole1[121]));
			asm volatile( "EE.GET_GPIO_IN %[r]" : [r] "=r"(pole1[122]));
			asm volatile( "EE.GET_GPIO_IN %[r]" : [r] "=r"(pole1[123]));
			asm volatile( "EE.GET_GPIO_IN %[r]" : [r] "=r"(pole1[124]));
			asm volatile( "EE.GET_GPIO_IN %[r]" : [r] "=r"(pole1[125]));
			asm volatile( "EE.GET_GPIO_IN %[r]" : [r] "=r"(pole1[126]));
			asm volatile( "EE.GET_GPIO_IN %[r]" : [r] "=r"(pole1[127]));
			asm volatile( "EE.GET_GPIO_IN %[r]" : [r] "=r"(pole1[128]));
			asm volatile( "EE.GET_GPIO_IN %[r]" : [r] "=r"(pole1[129]));
			asm volatile( "EE.GET_GPIO_IN %[r]" : [r] "=r"(pole1[130]));
			asm volatile( "EE.GET_GPIO_IN %[r]" : [r] "=r"(pole1[131]));
			asm volatile( "EE.GET_GPIO_IN %[r]" : [r] "=r"(pole1[132]));
			asm volatile( "EE.GET_GPIO_IN %[r]" : [r] "=r"(pole1[133]));
			asm volatile( "EE.GET_GPIO_IN %[r]" : [r] "=r"(pole1[134]));
			asm volatile( "EE.GET_GPIO_IN %[r]" : [r] "=r"(pole1[135]));
			asm volatile( "EE.GET_GPIO_IN %[r]" : [r] "=r"(pole1[136]));
			asm volatile( "EE.GET_GPIO_IN %[r]" : [r] "=r"(pole1[137]));
			asm volatile( "EE.GET_GPIO_IN %[r]" : [r] "=r"(pole1[138]));
			asm volatile( "EE.GET_GPIO_IN %[r]" : [r] "=r"(pole1[139]));
			asm volatile( "EE.GET_GPIO_IN %[r]" : [r] "=r"(pole1[140]));
			asm volatile( "EE.GET_GPIO_IN %[r]" : [r] "=r"(pole1[141]));
			asm volatile( "EE.GET_GPIO_IN %[r]" : [r] "=r"(pole1[142]));
			asm volatile( "EE.GET_GPIO_IN %[r]" : [r] "=r"(pole1[143]));
			asm volatile( "EE.GET_GPIO_IN %[r]" : [r] "=r"(pole1[144]));
			asm volatile( "EE.GET_GPIO_IN %[r]" : [r] "=r"(pole1[145]));
			asm volatile( "EE.GET_GPIO_IN %[r]" : [r] "=r"(pole1[146]));
			asm volatile( "EE.GET_GPIO_IN %[r]" : [r] "=r"(pole1[147]));
			asm volatile( "EE.GET_GPIO_IN %[r]" : [r] "=r"(pole1[148]));
			asm volatile( "EE.GET_GPIO_IN %[r]" : [r] "=r"(pole1[149]));
			asm volatile( "EE.GET_GPIO_IN %[r]" : [r] "=r"(pole1[150]));
			asm volatile( "EE.GET_GPIO_IN %[r]" : [r] "=r"(pole1[151]));
			asm volatile( "EE.GET_GPIO_IN %[r]" : [r] "=r"(pole1[152]));
			asm volatile( "EE.GET_GPIO_IN %[r]" : [r] "=r"(pole1[153]));
			asm volatile( "EE.GET_GPIO_IN %[r]" : [r] "=r"(pole1[154]));
			asm volatile( "EE.GET_GPIO_IN %[r]" : [r] "=r"(pole1[155]));
			asm volatile( "EE.GET_GPIO_IN %[r]" : [r] "=r"(pole1[156]));
			asm volatile( "EE.GET_GPIO_IN %[r]" : [r] "=r"(pole1[157]));
			asm volatile( "EE.GET_GPIO_IN %[r]" : [r] "=r"(pole1[158]));
			asm volatile( "EE.GET_GPIO_IN %[r]" : [r] "=r"(pole1[159]));
			asm volatile( "EE.GET_GPIO_IN %[r]" : [r] "=r"(pole1[160]));
			asm volatile( "EE.GET_GPIO_IN %[r]" : [r] "=r"(pole1[161]));
			asm volatile( "EE.GET_GPIO_IN %[r]" : [r] "=r"(pole1[162]));
			asm volatile( "EE.GET_GPIO_IN %[r]" : [r] "=r"(pole1[163]));
			asm volatile( "EE.GET_GPIO_IN %[r]" : [r] "=r"(pole1[164]));
			asm volatile( "EE.GET_GPIO_IN %[r]" : [r] "=r"(pole1[165]));
			asm volatile( "EE.GET_GPIO_IN %[r]" : [r] "=r"(pole1[166]));
			asm volatile( "EE.GET_GPIO_IN %[r]" : [r] "=r"(pole1[167]));
			asm volatile( "EE.GET_GPIO_IN %[r]" : [r] "=r"(pole1[168]));
			asm volatile( "EE.GET_GPIO_IN %[r]" : [r] "=r"(pole1[169]));
			asm volatile( "EE.GET_GPIO_IN %[r]" : [r] "=r"(pole1[170]));
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
void app_main(void)
{		
			//kanal 1- LTCH - 40 CLK - 8, DATA - 3 (v pripade zmeny, zmneit aj v configu v Maine)
			//kanal 2- LTCH - 39 CLK - 38, DATA - 9 
			//pridat comboBox do aplikacie
			
			//rele 1 - pin 1, rele2 - pin 2 (len checkBoxy)
			//x10 rele1 - 40, rele2 - 41
	
			// Configure the GPIO
	    gpio_config_t io_conf;
	    io_conf.intr_type = GPIO_INTR_DISABLE;    // No interrupt
	    io_conf.mode = GPIO_MODE_OUTPUT;         // Set as output
	    io_conf.pin_bit_mask = ((1ULL << GPIO_NUM_1) |(1ULL << GPIO_NUM_2) | (1ULL << GPIO_NUM_3) | (1ULL << GPIO_NUM_8) | (1ULL << GPIO_NUM_9) | (1ULL << GPIO_NUM_38) | (1ULL << GPIO_NUM_39) | (1ULL << GPIO_NUM_40)| (1ULL << GPIO_NUM_41)| (1ULL << GPIO_NUM_42));
	    io_conf.pull_down_en = GPIO_PULLDOWN_DISABLE;
	    io_conf.pull_up_en = GPIO_PULLUP_DISABLE;
	    gpio_config(&io_conf);
	    
	    // Configure  as INPUTS
	    io_conf.pin_bit_mask = (1ULL << GPIO_NUM_18) | (1ULL << GPIO_NUM_17) | (1ULL << GPIO_NUM_16) | (1ULL << GPIO_NUM_15) | (1ULL << GPIO_NUM_7) | (1ULL << GPIO_NUM_6) | (1ULL << GPIO_NUM_5) | (1ULL << GPIO_NUM_4) | (1ULL << GPIO_NUM_10) | (1ULL << GPIO_NUM_11) | (1ULL << GPIO_NUM_12) | (1ULL << GPIO_NUM_13) | (1ULL << GPIO_NUM_14) | (1ULL << GPIO_NUM_21) | (1ULL << GPIO_NUM_47) | (1ULL << GPIO_NUM_48);
	    io_conf.mode = GPIO_MODE_INPUT;
	    io_conf.pull_up_en = GPIO_PULLUP_ENABLE;  
	    io_conf.pull_down_en = GPIO_PULLDOWN_DISABLE;
	    io_conf.intr_type = GPIO_INTR_DISABLE;
	    gpio_config(&io_conf);
	    
		

		//gpio_set_direction(18,GPIO_MODE_INPUT);
		REG_WRITE(GPIO_FUNC221_IN_SEL_CFG_REG, 18);
		//gpio_set_direction(17,GPIO_MODE_INPUT);
		REG_WRITE(GPIO_FUNC222_IN_SEL_CFG_REG, 17);
		//gpio_set_direction(16,GPIO_MODE_INPUT);
		REG_WRITE(GPIO_FUNC223_IN_SEL_CFG_REG, 16);
		//gpio_set_direction(15,GPIO_MODE_INPUT);
		REG_WRITE(GPIO_FUNC224_IN_SEL_CFG_REG, 15); 
		//gpio_set_direction(7,GPIO_MODE_INPUT);
		REG_WRITE(GPIO_FUNC225_IN_SEL_CFG_REG, 7);
		//gpio_set_direction(6,GPIO_MODE_INPUT);
		REG_WRITE(GPIO_FUNC226_IN_SEL_CFG_REG, 6);
		//gpio_set_direction(5,GPIO_MODE_INPUT);
		REG_WRITE(GPIO_FUNC227_IN_SEL_CFG_REG, 5);
		//gpio_set_direction(4,GPIO_MODE_INPUT);
		REG_WRITE(GPIO_FUNC228_IN_SEL_CFG_REG, 4);
		
		//gpio_set_direction(10,GPIO_MODE_INPUT);
		REG_WRITE(GPIO_FUNC129_IN_SEL_CFG_REG, 10);
		//gpio_set_direction(11,GPIO_MODE_INPUT);
		REG_WRITE(GPIO_FUNC130_IN_SEL_CFG_REG, 11);
		//gpio_set_direction(12,GPIO_MODE_INPUT);
		REG_WRITE(GPIO_FUNC131_IN_SEL_CFG_REG, 12);
		//gpio_set_direction(13,GPIO_MODE_INPUT);
		REG_WRITE(GPIO_FUNC252_IN_SEL_CFG_REG, 13);
		//gpio_set_direction(14,GPIO_MODE_INPUT);
		REG_WRITE(GPIO_FUNC253_IN_SEL_CFG_REG, 14);
		//gpio_set_direction(21,GPIO_MODE_INPzdUT);
		REG_WRITE(GPIO_FUNC254_IN_SEL_CFG_REG, 21);	
		//gpio_set_direction(47,GPIO_MODE_INPUT);
		REG_WRITE(GPIO_FUNC255_IN_SEL_CFG_REG, 47);
		//gpio_set_direction(48,GPIO_MODE_INPUT);
		REG_WRITE(GPIO_FUNC54_IN_SEL_CFG_REG, 48);
		
		for(int s=0; s<1; s++){
		gpio_set_level(41, 1);
		sys_delay_ms(1000);
		gpio_set_level(41, 0);
		sys_delay_ms(1000);
		}	
		//stdout("autoMAT");
		//PRIMANIE Z POCITATCA
		// 1. Configure UART parameters
    uart_config_t uart_config = {
        .baud_rate = 460800,                        // Baud rate
        .data_bits = UART_DATA_8_BITS,               // Data bits
        .parity    = UART_PARITY_DISABLE,            // No parity
        .stop_bits = 0x0,               // 1 stop bit
        .flow_ctrl = UART_HW_FLOWCTRL_DISABLE,       // No flow control
    };

    // 2. Install UART driver
    ESP_ERROR_CHECK(uart_driver_install(UART_NUM, BUF_SIZE * 2, 0, 0, NULL, 0));
    ESP_ERROR_CHECK(uart_param_config(UART_NUM, &uart_config));
    ESP_ERROR_CHECK(uart_set_pin(UART_NUM, UART_PIN_NO_CHANGE, UART_PIN_NO_CHANGE, UART_PIN_NO_CHANGE, UART_PIN_NO_CHANGE));

    //nastavenie_zosilnovaca(5);

		

		xTaskCreatePinnedToCore(dedic_task, "dedic", 4096, NULL, 5, NULL, 0);
		xTaskCreatePinnedToCore(dedic_task2, "dedic1", 4096, NULL, 5, NULL, 1);

	
		  
}
